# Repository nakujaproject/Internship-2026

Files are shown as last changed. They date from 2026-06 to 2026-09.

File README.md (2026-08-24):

# Nakuja Project internship 2026

**Vision**: Build and launch a sub-orbital rocket to 100 km (Kármán Line).

**Mission**: Successful N4 Launch by September 2026.

## Quick Navigation
- [Project Overview](./00_PROJECT_OVERVIEW)
- [Solid Propulsion](./01_SOLID_PROPULSION)
- [Airframe](./02_AIRFRAME)
- [Recovery/Avionics](./03_RECOVERY)
- [Progress Tracker](./00_PROJECT_OVERVIEW/02_Progress_Tracker.md)

**Workshop Hours**: 9:00 AM – 5:00 PM, Monday–Friday.

**How to Contribute**: See [Contributing Guidelines](CONTRIBUTING.md)

# Nakuja Rocketry Repository Structure

```text
Internship-2026/
├── README.md                        
├── 00_PROJECT_OVERVIEW/
│   ├── 01_N4_ROCKET/
│   │   ├── image/
│   │   ├── Rocket_Specification.md
│   ├── 02_Organistaion_&_Structure/
│   │   ├── Nakuja_Project_Organisation_&_Operational_Structure.docx
│   │   ├── 02_Progress_Tracker.md
│   ├── 03_Meeting_Minutes/
│   ├── 04_Risk_Register.md
│   ├── 05_Launch_Checklist.md
│   └── 06_Timeline_Gantt.md
│
├── 01_SOLID_PROPULSION/                  
│   ├── 01_Propellant/
│   │   ├── Grains/
│   │   ├── Liners/
│   │   ├── Ignitors/
│   │   ├── Crimson_Powder/
│   │   ├── Experiments/
│   │   └── Research/
│   ├── 02_Machining_Team/
|   |   ├── Nozzles/
|   |   ├── Bulkheads/
│   │   ├── Motor_Assembly/
|   |   └── Test_Stand/
│   ├── 03_Ignition_Circuit/
|   |   ├── Software/
|   |   ├── Hardware/
│   ├── 04_3D_Printing/
│   ├── 05_Documentation/
│   │
│   ├── Static_Tests/
│   │   ├── One_Grain/
│   │   └── Five_Grain/
│   │
│   └── Photos_&_Videos/
│
├── 02_AIRFRAME/
│   ├── CAD_Designs/
│   ├── Fabrication/
│   ├── Launch_Pad_Rail/
│   └── Integration/
│
├── 03_RECOVERY/
│   ├── Flight_Computer/
│   ├── Telemetry/
│   ├── Ejection_System/
│   ├── Parachutes/
│   └── Integration/
│
├── 04_CROSS_TEAM/
│   ├── Integration_Dry_Runs/
│   ├── Safety_Protocols/
│   ├── Budget_Purchasing/
│   └── Media_Outreach/
│
├── 05_ARCHIVES/
│   ├── Previous_Tests/
│   ├── Old_Designs/
│   └── Backup/
│
├── .github/  *Make sure each folder has its own template
│   ├── ISSUE_TEMPLATE/
│   │   ├── experiment-template.md
│   │   ├── static-test-template.md
│   │   └── task-template.md
│   │
│   └── workflows/
│       └── README.md                  # Future CI/CD workflows
│
└── docs/
    ├── Scientific_Method_Guide.md
    ├── Grain_Preparation_Criteria.md
    └── Folder_Naming_Convention.md
```

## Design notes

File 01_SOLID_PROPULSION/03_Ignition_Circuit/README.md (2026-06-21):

## Purpose

This folder serves as the main documentation and development space for the ignition subsystem. It should help future team members understand, reproduce, test, maintain, and improve the ignition system.

The folder should contain:

* ESP32 firmware for the igniter board.
* ESP32 firmware for the trigger board.
* Web dashboard source files.
* Circuit diagrams and PCB files.
* Pin mappings and wiring documentation.
* Sensor calibration notes.
* Static-test and dry-run telemetry data.
* Dashboard screenshots and CSV logs.
* Safety checklists and operating notes.
* Relevant progress reports and technical summaries.

## System Architecture

The ignition system is divided into two main hardware modules:

| Module | Location | Main Function |
| --- | --- | --- |
| Igniter Circuit Board | Near the motor or static test stand | Reads sensors, controls the ignition-output circuit, and sends telemetry |
| Trigger Circuit Board | Operator side / safe distance | Sends ignition commands, receives telemetry, and streams data to the dashboard |
| Web Dashboard | Laptop or tablet connected to the trigger board | Displays real-time telemetry, logs events, and exports CSV data |

## Igniter Circuit Board

The igniter board is the test-stand-side module. It handles sensor acquisition, ignition-output control, and telemetry transmission.

Main functions:

* Reads thrust data from a load cell through the HX711 module.
* Reads temperature using the DS18B20 temperature sensor.
* Interfaces with the pressure transmitter circuit for chamber pressure monitoring.
* Receives wireless commands from the trigger board.
* Controls the MOSFET-based ignition-output circuit.
* Limits the ignition-output duration using firmware safety logic.
* Sends telemetry data to the trigger board.

Main components:

| Component | Purpose |
| --- | --- |
| ESP32 | Main controller |
| HX711 | Load-cell signal acquisition |
| Load cell | Thrust measurement |
| DS18B20 | Temperature measurement |
| Pressure transmitter/interface | Chamber pressure measurement |
| IRFZ44N MOSFET | Ignition-output switching |
| Power regulation circuit | Stable supply for logic and sensor circuits |

## Trigger Circuit Board

The trigger board is the operator-side module. It acts as the control and communication bridge between the igniter board and the dashboard.

Main functions:

* Sends ignition commands to the igniter board.
* Receives telemetry from the igniter board through ESP-NOW.
* Creates a local Wi-Fi access point.
* Runs a WebSocket server for dashboard communication.
* Provides operator feedback using indicators such as buzzer, status LED, or display output.
* Supports safer test operation by keeping the operator away from the test stand.

## Web Dashboard

The dashboard is a browser-based interface for real-time test monitoring and data recording.

Main functions:

* Displays thrust, pressure, and temperature values.
* Shows telemetry trends using graphs.
* Displays system and connection status.
* Logs important events such as arming, disconnection, and ignition status.
* Allows recording to be started and stopped.
* Exports telemetry as timestamped CSV files for later analysis.

The dashboard is developed using:

| Technology | Use |
| --- | --- |
| HTML | Dashboard structure |
| CSS | Styling and layout |
| JavaScript | Data handling, plotting, event logging, and CSV export |
| WebSocket  | Real-time telemetry communication |
| Node.js | Dashboard testing or telemetry simulation where applicable |

## Communication Flow

The system uses two communication layers:

| Link | Method | Purpose |
| --- | --- | --- |
| Igniter board ↔ Trigger board | ESP-NOW | Board-to-board command and telemetry communication |
| Trigger board ↔ Dashboard | Wi-Fi access point + WebSocket | Real-time dashboard streaming |

General data flow:

```text
Sensors
   ↓
Igniter Circuit Board
   ↓
ESP-NOW
   ↓
Trigger Circuit Board
   ↓
Wi-Fi + WebSocket
   ↓
Web Dashboard
   ↓
CSV Export
```

## Telemetry Variables

| Variable | Unit | Source |
| --- | ---: | --- |
| Thrust | N | Load cell + HX711 |
| Pressure | bar | Pressure transmitter |
| Temperature | °C | DS18B20 |
| Armed State | Status | Firmware logic |
| Ignition State | Status | Firmware logic |
| Time | s / ms | ESP32 or dashboard timestamp |

## Sensor and Data Acquisition

### Load Cell and HX711

The load cell is used to measure thrust during static testing. The HX711 converts the small load-cell signal into digital data that can be processed by the ESP32.

The HX711 sampling rate was improved to increase the number of useful data points during short static-test burns. This improves thrust-curve resolution and helps with later comparison against simulation results.

### Temperature Sensor

The DS18B20 digital temperature sensor is used for temperature measurement. It provides a digital reading and reduces the need for analog signal conditioning.

### Pressure Transmitter Interface

The pressure measurement system is intended to monitor chamber pressure during static testing. Since the ESP32 reads voltage, the pressure transmitter signal must be conditioned into a safe analog voltage range before being connected to the ESP32 analog input.

Pressure data is important for understanding combustion behavior, validating simulations, and supporting future motor scaling decisions.

## Safety Logic

The ignition system is safety-critical. The firmware and operating procedure must ensure that ignition only occurs under controlled conditions.

Core safety features:

* Remote operator-side command.
* Wireless separation between operator and test stand.
* Arming logic before ignition.
* Timed ignition-output window.
* Status feedback through the dashboard and indicators.
* Telemetry confirmation before test operation.
* Data recording for post-test review.
* Documentation of abnormal behavior before further testing.

## Software Folder

The `Software/` folder should contain all firmware and dashboard-related files.

Recommended structure:

```text
Software/
├── Igniter_Board_Firmware/
├── Trigger_Board_Firmware/
├── Web_Dashboard/
└── Simulation_or_Test_Tools/
```

Recommended contents:

* ESP32 igniter firmware.
* ESP32 trigger firmware.
* Dashboard HTML, CSS, and JavaScript files.
* WebSocket or Node.js simulation tools.
* Required libraries.
* Upload instructions.
* Firmware notes.
* Dashboard screenshots.
* Sample test data.

## Hardware Folder

The `Hardware/` folder should contain all physical design and electronics documentation.

Recommended structure:

```text
Hardware/
├── Schematics/
├── PCB/
├── Wiring_Diagrams/
├── Photos/
├── BOM.md
└── Pin_Mapping.md
```

## Development Status

| Area | Status |
| --- | --- |
| Igniter board firmware | In development / testing |
| Trigger board firmware | In development / testing |
| Web dashboard | Developed for real-time telemetry visualization  |
| ESP-NOW communication | Implemented for board-to-board communication |
| WebSocket communication | Implemented for dashboard streaming |
| HX711 load-cell acquisition | Improved for higher sampling-rate thrust capture |
| DS18B20 temperature sensing | Integrated |
| Pressure transmitter interface | Requires final validation and calibration |
| Power stability | Brownout mitigation requires final validation |
| CSV export | Implemented in dashboard workflow |
| Static-test validation | To be updated after each test campaign |

## Repository Scope

This folder covers:

* Ignition system electronics.
* ESP32 firmware.
* Wireless communication.
* Web dashboard development.
* Sensor interfacing.
* Telemetry logging.
* Calibration notes.
* Hardware documentation.
* Test data.
* Safety checklists.

## Safety Notice

All ignition-system testing must be conducted only under approved Nakuja Project procedures, supervision, safe-distance operation, and proper pre-test checks.

This repository folder is for electronics, firmware, telemetry, calibration, data logging, and safety documentation only.

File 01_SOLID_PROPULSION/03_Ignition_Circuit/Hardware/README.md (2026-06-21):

# Hardware — Ignition Circuit

## Overview

This folder contains the hardware documentation for the Nakuja Project ignition and real-time telemetry system. It includes circuit diagrams, PCB files, wiring diagrams, pin mappings, power-system notes, bill of materials, and reference photos.

The hardware system is divided into two main modules:

1. Igniter Circuit Board
2. Trigger Circuit Board

The igniter board is placed near the motor or static test stand, while the trigger board is operated from a safe distance.

## Recommended Folder Structure

```text
Hardware/
├── README.md
├── Schematics/
├── PCB/
├── Wiring_Diagrams/
├── Photos/
├── BOM.md
└── Pin_Mapping.md
```

## Main Hardware Modules

| Module | Location | Purpose |
| --- | --- | --- |
| Igniter Circuit Board | Near static test stand | Sensor reading, telemetry transmission, ignition-output control |
| Trigger Circuit Board | Operator side | Command input, telemetry reception, dashboard link, operator feedback |
| Sensor Interfaces | Test-stand side | Thrust, pressure, and temperature measurement |
| Power System | Both boards | Provides regulated voltage to electronics and sensors |

## Igniter Circuit Board

The igniter board handles test-stand-side sensing and output control.

Main hardware functions:

* Interface with the load cell through the HX711 module.
* Interface with the DS18B20 temperature sensor.
* Interface with the pressure transmitter circuit.
* Control the MOSFET-based ignition-output stage.
* Send telemetry to the trigger board.
* Receive wireless command signals from the trigger board.

Recommended documentation:

```text
Igniter_Board/
├── schematic.pdf
├── pcb_layout.png
├── wiring_diagram.png
├── board_photo.jpg
└── notes.md
```

## Trigger Circuit Board

The trigger board handles the operator-side control and communication functions.

Main hardware functions:

* Provide operator command input.
* Give status feedback through buzzer, LED, or display output.
* Receive telemetry from the igniter board.
* Support Wi-Fi and WebSocket communication to the dashboard.
* Maintain operator-side separation from the test stand.

Recommended documentation:

```text
Trigger_Board/
├── schematic.pdf
├── pcb_layout.png
├── wiring_diagram.png
├── board_photo.jpg
└── notes.md
```

## Main Components

| Component | Purpose |
| --- | --- |
| ESP32 | Main controller for both boards |
| HX711 | Load-cell signal acquisition |
| Load cell | Thrust measurement |
| DS18B20 | Temperature measurement |
| Pressure transmitter/interface | Chamber pressure measurement |
| IRFZ44N MOSFET | Ignition-output switching |
| Buck converter | Step-down voltage regulation |
| Boost converter | Pressure transmitter supply where required |
| XT60 / XT30 connectors | Secure power connection |
| JST connectors | Secure sensor connections |
| Buzzer | Operator feedback |
| Status LED | Visual indication |

## Power System

The hardware should include clear documentation of the power path.

Document the following:

* Main battery voltage.
* Regulated logic voltage.
* ESP32 supply voltage.
* Sensor supply voltage.
* Pressure transmitter supply voltage.
* Ground reference connections.
* Connector type and polarity.
* Fuse or protection method where used.
* Brownout issues and mitigation steps.

## Sensor Interfaces

### Load Cell and HX711

The load cell and HX711 subsystem is used for thrust measurement. The hardware documentation should include:

* Load-cell wiring.
* HX711 wiring.
* HX711 sampling-rate configuration.
* Calibration connection notes.
* Mechanical mounting reference where available.

### DS18B20 Temperature Sensor

The DS18B20 subsystem is used for temperature measurement. The hardware documentation should include:

* Sensor wiring.
* Pull-up resistor value where used.
* Connector type.
* Physical mounting location.

### Pressure Transmitter Interface

The pressure transmitter/interface is used for chamber pressure measurement. The hardware documentation should include:

* Pressure transmitter wiring.
* Supply voltage.
* Current-to-voltage conversion circuit.
* ESP32 analog input connection.
* Resistor value used for conversion.
* Expected voltage range.
* Calibration notes.

## PCB Documentation

For each PCB revision, include:

| File | Description |
| --- | --- |
| Schematic | Circuit-level design |
| PCB layout | Board routing and component placement |
| Gerber files | Fabrication files |
| Board photos | Physical reference |
| Revision notes | What changed between versions |
| Test notes | What was verified |

## Pin Mapping

Create or update `Pin_Mapping.md` with a table such as:

| Function | ESP32 Pin | Board | Notes |
| --- | ---: | --- | --- |
| MOSFET gate | GPIO26 | Igniter | Ignition-output control |
| HX711 DOUT | GPIO33 | Igniter | Load-cell data |
| HX711 SCK | GPIO32 | Igniter | Load-cell clock |
| DS18B20 data | GPIO14 | Igniter | Temperature input |
| Pressure input | GPIO13 | Igniter | Analog pressure signal |
| Buzzer | To be documented | Trigger | Operator feedback |
| Status input/button | To be documented | Trigger | Operator command or state input |

## Hardware Documentation Rules

When adding hardware files:

1. Use clear file names.
2. Separate schematics, PCB files, wiring diagrams, and photos.
3. Label every board revision.
4. Add notes for tested and untested circuits.
5. Document connector polarity.
6. Document voltage levels.
7. Document sensor pinouts.
8. Keep photos compressed but clear.
9. Do not upload unexplained Gerber or schematic files.
10. Add a short note when replacing or modifying a component.

## Current Status

| Area | Status |
| --- | --- |
| Igniter board hardware | In development / testing |
| Trigger board hardware | In development / testing |
| Load-cell interface | Integrated |
| Temperature sensor interface | Integrated |
| Pressure transmitter interface | Requires final validation |
| Power regulation | Requires brownout validation |
| PCB documentation | To be updated with final board files |
| Wiring documentation | To be completed with labelled diagrams |

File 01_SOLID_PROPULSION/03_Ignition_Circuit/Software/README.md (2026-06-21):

# Software — Ignition Circuit

## Overview

This folder contains all software files for the Nakuja Project ignition and real-time telemetry system. It includes ESP32 firmware for the igniter and trigger boards, web dashboard source files, and simulation or testing tools used during development.

The software system supports wireless command transmission, real-time telemetry streaming, dashboard visualization, event logging, and CSV data export.

## Recommended Folder Structure

```text
Software/
├── README.md
├── Igniter_Board_Firmware/
├── Trigger_Board_Firmware/
├── Web_Dashboard/
└── Simulation_or_Test_Tools/
```

## Software Modules

| Module | Purpose |
| --- | --- |
| `Igniter_Board_Firmware/` | Firmware for the test-stand-side ESP32 board |
| `Trigger_Board_Firmware/` | Firmware for the operator-side ESP32 board |
| `Web_Dashboard/` | Browser-based telemetry dashboard files |
| `Simulation_or_Test_Tools/` | Scripts or tools for testing telemetry without full hardware |

## Igniter Board Firmware

The igniter board firmware runs on the ESP32 located near the static test stand.

Main responsibilities:

* Read thrust data from the HX711 load-cell subsystem.
* Read temperature data from the DS18B20 sensor.
* Read pressure data from the pressure transmitter interface.
* Receive ignition commands from the trigger board through ESP-NOW.
* Control the MOSFET-based ignition output.
* Enforce the programmed ignition safety window.
* Send telemetry packets to the trigger board.

Recommended files:

```text
Igniter_Board_Firmware/
├── README.md
├── main.ino
├── config.example.h
├── pins.h
└── libraries.md
```

## Trigger Board Firmware

The trigger board firmware runs on the ESP32 located with the operator.

Main responsibilities:

* Receive telemetry from the igniter board.
* Send operator ignition commands to the igniter board.
* Create the local Wi-Fi access point.
* Run the WebSocket server for dashboard communication.
* Forward telemetry data to the dashboard.
* Provide operator feedback using indicators such as buzzer, LED, or display output.

Recommended files:

```text
Trigger_Board_Firmware/
├── README.md
├── main.ino
├── config.example.h
├── pins.h
└── libraries.md
```

## Web Dashboard

The web dashboard is used to monitor the static test in real time from a laptop or tablet.

Main functions:

* Display thrust, pressure, and temperature.
* Plot telemetry values against time.
* Show system connection status.
* Log important events.
* Start and stop data recording.
* Export recorded telemetry as CSV files.

Recommended files:

```text
Web_Dashboard/
├── README.md
├── index.html
├── style.css
├── script.js
├── assets/
├── screenshots/
└── sample_data/
```

## Communication Flow

```text
Igniter Board Firmware
        ↓
ESP-NOW telemetry
        ↓
Trigger Board Firmware
        ↓
Wi-Fi Access Point + WebSocket
        ↓
Web Dashboard
        ↓
CSV Export
```

## Main Technologies

| Technology | Use |
| --- | --- |
| ESP32 | Main microcontroller platform |
| ESP-NOW | Board-to-board wireless communication |
| Wi-Fi Access Point | Local dashboard connection |
| WebSocket | Real-time telemetry streaming |
| HTML | Dashboard structure |
| CSS | Dashboard styling |
| JavaScript | Dashboard logic, plotting, recording, and CSV export |
| Node.js | Optional testing or telemetry simulation |

## Telemetry Data

The software should handle the following main telemetry values:

| Variable | Unit | Description |
| --- | ---: | --- |
| Thrust | N | Load-cell measurement through HX711 |
| Pressure | bar | Pressure transmitter/interface reading |
| Temperature | °C | DS18B20 sensor reading |
| Armed State | Status | Indicates arming condition |
| Ignition State | Status | Indicates ignition-output state |
| Time | s / ms | Timestamp for plotting and data recording |

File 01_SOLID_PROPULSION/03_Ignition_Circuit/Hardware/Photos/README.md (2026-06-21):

# Hardware Photos

## Overview

This folder contains reference photos for the Nakuja Project ignition circuit hardware.

Photos should help team members understand the physical assembly, wiring, PCB layout, connector arrangement, test setup, and hardware changes between revisions.

## Recommended Contents

```text
Photos/
├── README.md
├── Igniter_Board/
├── Trigger_Board/
├── PCB_Fabrication/
├── Sensor_Connections/
├── Power_System/
└── Test_Setup/
```

## Photos to Include

| Photo Type | Purpose |
| --- | --- |
| Igniter board top view | Shows component placement |
| Igniter board wiring | Shows sensor and power connections |
| Trigger board top view | Shows operator-side hardware |
| Trigger board wiring | Shows command and feedback connections |
| PCB fabrication photos | Shows etching, drilling, soldering, or manufacturing process |
| HX711/load-cell connection | Shows thrust sensor wiring |
| DS18B20 connection | Shows temperature sensor wiring |
| Pressure interface setup | Shows pressure sensor/transmitter connection |
| Power system photo | Shows battery, buck converter, boost converter, and connectors |
| Test setup photo | Shows safe hardware arrangement during dry run or static test  |

## Photo Naming Format

Use clear file names:

```text
igniter_board_revA_top_view.jpg
igniter_board_revA_wiring.jpg
trigger_board_revA_top_view.jpg
trigger_board_revA_wiring.jpg
pcb_etching_revA_process.jpg
hx711_load_cell_connection.jpg
ds18b20_sensor_connection.jpg
pressure_interface_test_setup.jpg
power_system_wiring_revA.jpg
```

## Documentation Notes

For important photos, add a short note explaining:

* What the photo shows.
* Which board revision it belongs to.
* Whether the setup was tested.
* Any known issue visible in the photo.
* Date taken, if available.

## Quality Guidelines

* Upload clear and well-lit photos.
* Avoid duplicate photos.
* Avoid blurry wiring photos.
* Compress very large images before uploading.
* Do not upload unrelated personal photos or unsafe test images without context.

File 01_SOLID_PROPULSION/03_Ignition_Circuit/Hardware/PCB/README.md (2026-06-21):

# PCB Documentation

## Overview

This folder contains printed circuit board documentation for the Nakuja Project ignition circuit hardware.

It should include PCB layout files, Gerber files, board images, fabrication notes, and revision records for the igniter board and trigger board.

## Recommended Contents

```text
PCB/
├── README.md
├── Igniter_Board/
├── Trigger_Board/
├── Gerber_Files/
├── PCB_Layout_Images/
└── Fabrication_Notes/
```

## PCB Files to Upload

| File Type | Purpose |
| --- | --- |
| Schematic-linked PCB layout | Shows component placement and routing |
| Gerber files | Used for PCB fabrication |
| Drill files | Used for PCB hole drilling |
| Top copper image | Shows top copper routing |
| Bottom copper image | Shows bottom copper routing |
| Silkscreen image | Shows labels and component positions |
| Board photo | Shows the physical fabricated board |
| Fabrication notes | Documents etching, drilling, soldering, or manufacturing steps |

## Board Revision Format

Use clear revision names:

```text
igniter_board_revA
trigger_board_revA
igniter_board_revB
trigger_board_revB
```

## Recommended Revision Table

| Board | Revision | Date | Status | Notes |
| --- | --- | --- | --- | --- |
| Igniter Board | Rev A | YYYY-MM-DD | Draft / Fabricated / Tested | Initial version |
| Trigger Board | Rev A | YYYY-MM-DD | Draft / Fabricated / Tested | Initial version |

## Documentation Notes

For every PCB version, document:

* Board name.
* Revision number.
* Date created.
* Design software used.
* Main changes from previous version.
* Known issues.
* Test status.
* Photos of the final assembled board where available.

## Safety Note

PCB files must match the latest verified schematic and firmware pin mapping. Any mismatch between PCB routing, firmware pins, and wiring diagrams must be corrected before testing.

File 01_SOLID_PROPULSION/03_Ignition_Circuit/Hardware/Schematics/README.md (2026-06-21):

## File: `Schematics/README.md`

# Schematics

## Overview

This folder contains circuit schematics for the Nakuja Project ignition system hardware.

The schematics should document the electrical connections for the igniter board, trigger board, sensor interfaces, power regulation stage, and ignition-output switching circuit.

## Recommended Contents

* Igniter board schematic.
* Trigger board schematic.
* Power regulation schematic.
* HX711 load-cell interface schematic.
* DS18B20 temperature sensor interface.
* Pressure transmitter/interface circuit.
* MOSFET ignition-output switching circuit.
* Status LED and buzzer connections.

## Documentation Notes

Each schematic should clearly show:

* Component labels.
* Connector names.
* Voltage levels.
* Ground reference.
* ESP32 pin connections.
* Sensor wiring.
* Power input and output paths.
* Revision number and date.

---

## File: `PCB/README.md`

# PCB

## Overview

This folder contains printed circuit board documentation for the ignition system.

It should include PCB layout files, Gerber files, board images, fabrication notes, and revision history for both the igniter board and trigger board.

## Recommended Contents

* PCB layout screenshots.
* Gerber files.
* Board fabrication files.
* Etching or manufacturing notes.
* Component placement diagrams.
* Top and bottom copper layer images.
* Board revision notes.
* Photos of assembled PCBs.

## Documentation Notes

Each PCB revision should include:

| Item | Description |
| --- | --- |
| Board name | Igniter board or trigger board |
| Revision | Rev A, Rev B, etc. |
| Date | Date uploaded or fabricated |
| Status | Draft, fabricated, tested, or archived |
| Notes | Main changes or known issues |

---

## File: `Wiring_Diagrams/README.md`

# Wiring Diagrams

## Overview

This folder contains wiring diagrams for the ignition system.

The wiring diagrams should make it easy for a team member to connect the boards, sensors, power supply, and dashboard communication hardware correctly.

## Recommended Contents

* Full system wiring diagram.
* Igniter board wiring diagram.
* Trigger board wiring diagram.
* Load-cell and HX711 wiring.
* DS18B20 wiring.
* Pressure transmitter/interface wiring.
* Power wiring.
* Connector pinout diagrams.

## Documentation Notes

Each wiring diagram should clearly show:

* Connector names.
* Pin numbers.
* Wire colors where applicable.
* Voltage level.
* Ground connections.
* Signal direction.
* Sensor polarity.
* Power polarity.
* Safety-related connections.

---

## File: `Photos/README.md`

# Photos

## Overview

This folder contains reference photos for the ignition system hardware.

Photos should help future team members understand the physical assembly, wiring, PCB layout, and test setup.

## Recommended Contents

* Igniter board photos.
* Trigger board photos.
* PCB fabrication photos.
* Wiring photos.
* Sensor connection photos.
* Dashboard setup photos.
* Static-test setup photos where appropriate.

## Photo Naming Format

Use clear names such as:

```text
igniter_board_revA_top_view.jpg
trigger_board_revA_wiring.jpg
hx711_load_cell_connection.jpg
pressure_interface_test_setup.jpg
pcb_etching_process_revA.jpg
```

## Documentation Notes

Avoid uploading unclear or duplicate photos. Each important photo should be labelled or accompanied by a short note explaining what it shows.

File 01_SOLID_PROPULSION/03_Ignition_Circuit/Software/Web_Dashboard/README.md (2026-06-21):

# Web Dashboard

## Overview

This folder contains the browser-based dashboard for the Nakuja Project ignition and real-time telemetry system.

The dashboard is used to monitor thrust, pressure, temperature, connection status, arming state, and ignition events during dry runs and static motor tests. It receives telemetry through a WebSocket connection and allows recorded data to be exported as CSV files.

## Main Functions

* Display real-time thrust readings.
* Display real-time pressure readings.
* Display real-time temperature readings.
* Plot telemetry values against time.
* Show connection status.
* Log important events.
* Start and stop data recording.
* Export recorded telemetry as CSV files.
* Support review of static-test and dry-run data.

## Recommended Folder Contents

```text
Web_Dashboard/
├── README.md
├── index.html
├── style.css
├── script.js
├── assets/
├── screenshots/
└── sample_data/
```

## Main Files

| File/Folder | Purpose |
| --- | --- |
| `index.html` | Main dashboard page structure |
| `style.css` | Dashboard styling and layout |
| `script.js` | WebSocket connection, charting, event logging, and CSV export |
| `assets/` | Logos, icons, and visual resources |
| `screenshots/` | Dashboard preview images |
| `sample_data/` | Example telemetry data for testing |

## Dashboard Data

| Variable | Unit | Description |
| --- | ---: | --- |
| Thrust | N | Load-cell measurement |
| Pressure | kPa / bar | Pressure transmitter/interface reading |
| Temperature | °C | DS18B20 reading |
| Armed State | Status | System arming condition |
| Ignition State | Status | Ignition-output condition |
| Time | s / ms | Used for plotting and recording |

## Communication

The dashboard receives data from the trigger board through a WebSocket connection.

```text
Trigger Board
     ↓
Wi-Fi Access Point
     ↓
WebSocket
     ↓
Browser Dashboard
```

## Development Notes

When updating the dashboard, document:

* Dashboard version.
* WebSocket IP address or hostname.
* WebSocket port.
* Telemetry packet format.
* Chart update rate.
* CSV export format.
* Known bugs.
* Screenshots of the interface.

## Testing Notes

The dashboard can be tested using:

* Live data from the trigger board.
* Simulated telemetry from Node.js or another test script.
* Sample CSV files.
* Manually generated telemetry packets.

## Safety Note

The dashboard is a monitoring and recording interface. It should not be treated as the only safety control. Physical procedures, firmware safety logic, and approved test checklists must still be followed.

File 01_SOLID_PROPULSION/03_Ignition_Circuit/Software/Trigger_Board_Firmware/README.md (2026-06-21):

# Trigger Board Firmware

## Overview

This folder contains the ESP32 firmware for the trigger-side board of the Nakuja Project ignition and real-time telemetry system.

The trigger board is positioned with the operator at a safe distance. It sends ignition commands, receives telemetry from the igniter board, provides operator feedback, and streams data to the web dashboard.

## Main Responsibilities

* Send ignition commands to the igniter board.
* Receive telemetry from the igniter board through ESP-NOW.
* Create a local Wi-Fi access point for dashboard connection.
* Run a WebSocket server for real-time dashboard communication.
* Forward telemetry values to the dashboard.
* Provide operator feedback using buzzer, LED, LCD, or other indicators.
* Support safe operator-side control.

## Main Interfaces

| Function | Device/Interface | Notes |
| --- | --- | --- |
| Board-to-board communication | ESP-NOW | Receives telemetry and sends commands |
| Dashboard connection | Wi-Fi access point | Laptop connects locally |
| Dashboard streaming | WebSocket server | Sends live telemetry |
| Operator feedback | Buzzer / LED / display | Shows status and alerts |
| Operator command | Push button / switch | Used for controlled command input |

## Recommended Folder Contents

```text
Trigger_Board_Firmware/
├── README.md
├── main.ino
├── config.example.h
├── pins.h
└── libraries.md
```

## Firmware Logic

The firmware should generally follow this sequence:

1. Initialize pins and feedback devices.
2. Initialize ESP-NOW communication.
3. Create the Wi-Fi access point.
4. Start the WebSocket server.
5. Receive telemetry from the igniter board.
6. Forward telemetry to the dashboard.
7. Monitor operator command input.
8. Send ignition command only when required.
9. Report connection and system-status changes.

## Communication Role

```text
Igniter Board
     ↓
ESP-NOW
     ↓
Trigger Board
     ↓
Wi-Fi + WebSocket
     ↓
Web Dashboard
```

## Documentation Requirements

When firmware is uploaded, include:

* Firmware version.
* Required libraries.
* Board type used.
* Pin mapping.
* Wi-Fi access point name.
* WebSocket port.
* Upload instructions.
* Known issues.
* Test notes.

## Safety Note

The trigger board should not send an ignition command accidentally. Operator input, arming status, communication status, and system state should be handled clearly in the firmware.

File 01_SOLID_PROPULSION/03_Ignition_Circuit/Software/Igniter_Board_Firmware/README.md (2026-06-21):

# Igniter Board Firmware

## Overview

This folder contains the ESP32 firmware for the igniter-side board of the Nakuja Project ignition and real-time telemetry system.

The igniter board is positioned near the solid rocket motor or static test stand. It is responsible for reading sensor data, receiving ignition commands, controlling the ignition-output circuit, and transmitting telemetry to the trigger board.

## Main Responsibilities

* Read thrust data from the load cell through the HX711 module.
* Read temperature data from the DS18B20 temperature sensor.
* Read pressure data from the pressure transmitter/interface circuit.
* Receive wireless commands from the trigger board.
* Control the MOSFET-based ignition-output circuit.
* Enforce the programmed ignition safety window.
* Send telemetry data to the trigger board.

## Main Hardware Interfaces

| Function | Device/Interface | Notes |
| --- | --- | --- |
| Thrust measurement | Load cell + HX711 | Used for static-test thrust data |
| Temperature measurement | DS18B20 | Digital temperature sensor |
| Pressure measurement | Pressure transmitter/interface | Requires signal conditioning before ESP32 input |
| Ignition output | MOSFET switching stage | Controlled by ESP32 firmware |
| Wireless communication  | ESP-NOW | Receives command and sends telemetry |

## Suggested Pin Mapping

| Function | ESP32 Pin | Notes |
| --- | ---: | --- |
| MOSFET gate | GPIO26 | Ignition-output control |
| HX711 DOUT | GPIO33 | Load-cell data |
| HX711 SCK | GPIO32 | Load-cell clock |
| DS18B20 data | GPIO14 | Temperature sensor data |
| Pressure input | GPIO13 | Analog pressure signal  |

## Recommended Folder Contents

```text
Igniter_Board_Firmware/
├── README.md
├── main.ino
├── config.example.h
├── pins.h
└── libraries.md
```

## Firmware Logic

The firmware should generally follow this sequence:

1. Initialize ESP32 pins, sensors, and communication.
2. Read thrust, temperature, and pressure values.
3. Send telemetry to the trigger board.
4. Wait for valid command from the trigger board.
5. Check arming and safety conditions.
6. Activate ignition output only when allowed.
7. Automatically disable ignition output after the safety window.
8. Continue sending telemetry and system-status data.

## Documentation Requirements

When firmware is uploaded, include:

* Firmware version.
* Required libraries.
* Board type used.
* Pin mapping.
* Upload instructions.
* Calibration assumptions.
* Known issues.
* Test notes.

## Safety Note

The ESP32 must not directly power the ignition load. It should only control the switching stage. The ignition output must remain disabled until all safety conditions are satisfied.

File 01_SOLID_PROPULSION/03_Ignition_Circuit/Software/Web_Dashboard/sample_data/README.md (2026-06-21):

# Sample Dashboard Data

## Overview

This folder contains sample telemetry data for testing and documenting the Nakuja ignition web dashboard.

The files in this folder are not real static-test results. They are only used to confirm dashboard formatting, CSV export, telemetry parsing, and documentation examples.

## Recommended Files

| File | Purpose |
|---|---|
| `sample_telemetry_packet.json` | Example WebSocket telemetry packet |
| `sample_dashboard_data.csv` | Example dashboard CSV export |
| `sample_event_log.txt` | Example event log output, if required |

## Sample Data Rules

- Clearly label all sample files.
- Do not mix sample data with real test data.
- Do not use sample data for engineering conclusions.
- Real dry-run and static-test data should be stored in a separate test-data folder.
- Update the sample files when the dashboard telemetry format changes.

## Expected Telemetry Variables

| Variable | Unit | Description |
|---|---:|---|
| Temperature | °C | DS18B20 temperature reading |
| Pressure | kPa / bar | Pressure transmitter/interface reading |
| Thrust | N | Load-cell and HX711 thrust reading |
| Armed State | Status | Ignition arming condition |
| Event | Text | Optional event log message |

## Notes

Sample data is useful for software testing, documentation, and demonstrating dashboard behavior without connecting the full ignition hardware.

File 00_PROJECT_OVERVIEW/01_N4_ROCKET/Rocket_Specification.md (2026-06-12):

# N4 rocket portal

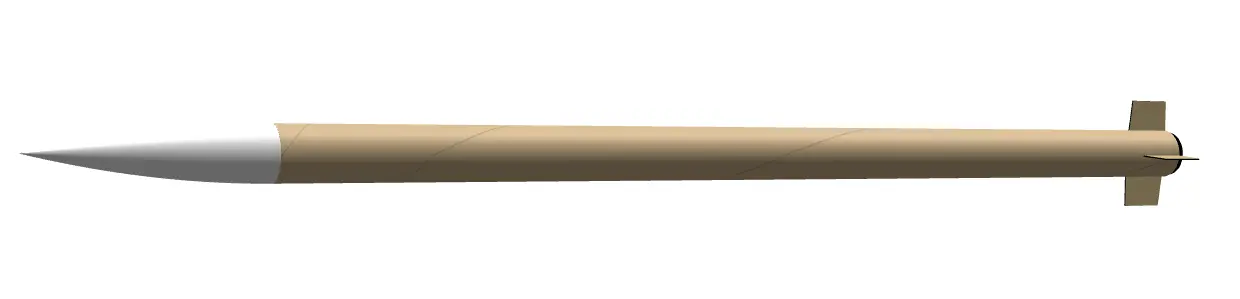
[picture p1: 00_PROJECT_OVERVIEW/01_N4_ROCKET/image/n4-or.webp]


## Specification

| Rocket | N-4  <br>(Names TBD) |
| --- | --- |
| Airframe material | Fibreglass |
| Length | 255 cm |
| External diameter | 110 mm |
| Dry mass | 13.1 kg |
| Total mass | 24.8 kg |
| Simulated apogee | 3,702 m |
| Propellant | KNSB |
| Simulated total impulse | 8,315 \[N•s\] (M2410 motor) |

## General information

| Component | Link  | 
|---|---|
| Rocket measured data | |
| Rocket photos | |

## Airframe
| Component | Link  | 
|---|---|
| OpenRocket simulation file |[link]https://github.com/nakujaproject/N4-Airframe-CAD-files/blob/main/N4_current.ork |
| Airframe CAD data |[link]https://github.com/nakujaproject/N4-Airframe-CAD-files |
| 3D Print data (Nose cone, launch lugs)|[link]https://github.com/nakujaproject/N4-Airframe-CAD-files |
| Avionics bay design data | |
| Parachute design data | |
| Fin design data | |

## Recovery
| Component | Link  | 
|---|---|
| Flight computer PCB design (Wifi-based. 3 of 4 N-3 rockets use this design) | []() |
| Flight computer PCB design (LoRa-based. 1 of 4 N-3 rocket uses this design) | []() |
| Ejection PCB design | []() |
| Flight computer firmware | |  
| Ground station dashboard |  | 

## Propulsion

| Component | Link  | 
|---|---|
| Solid rocket motor design calculation  | [link](https://github.com/nakujaproject/N-4_Solid_Propulsion/blob/main/SRM%20Components/Design%20Calculations.pdf)  |
| OpenMotor simulation file | [link](https://github.com/nakujaproject/N-4_Solid_Propulsion/blob/main/Grains/N4_grain%20design.ric) |  
| Casing CAD data  | [link](https://github.com/nakujaproject/N-4_Solid_Propulsion/blob/main/SRM%20Components/Casing.SLDPRT)  |  
| Casing drawing  | [link](https://github.com/nakujaproject/N-4_Solid_Propulsion/blob/main/SRM%20Components/Bulkhead_Drawing.pdf)|
| Nozzle CAD data  | [link](https://github.com/nakujaproject/N-4_Solid_Propulsion/blob/main/SRM%20Components/Nozzle2.SLDPRT) |  
| Nozzle drawing (No mounting holes)  | [link](https://github.com/nakujaproject/N-4_Solid_Propulsion/blob/main/SRM%20Components/Nozzle2_Drawing_redesigned.PDF)  |  
| Bulkhead CAD data |  [link](https://github.com/nakujaproject/N-4_Solid_Propulsion/blob/main/SRM%20Components/Bulkhead.SLDPRT) |  
| Bulkhead drawing (No mounting holes) | [link](https://github.com/nakujaproject/N-4_Solid_Propulsion/blob/main/SRM%20Components/Bulkhead_Drawing.pdf)|
| SRM casting video| | 

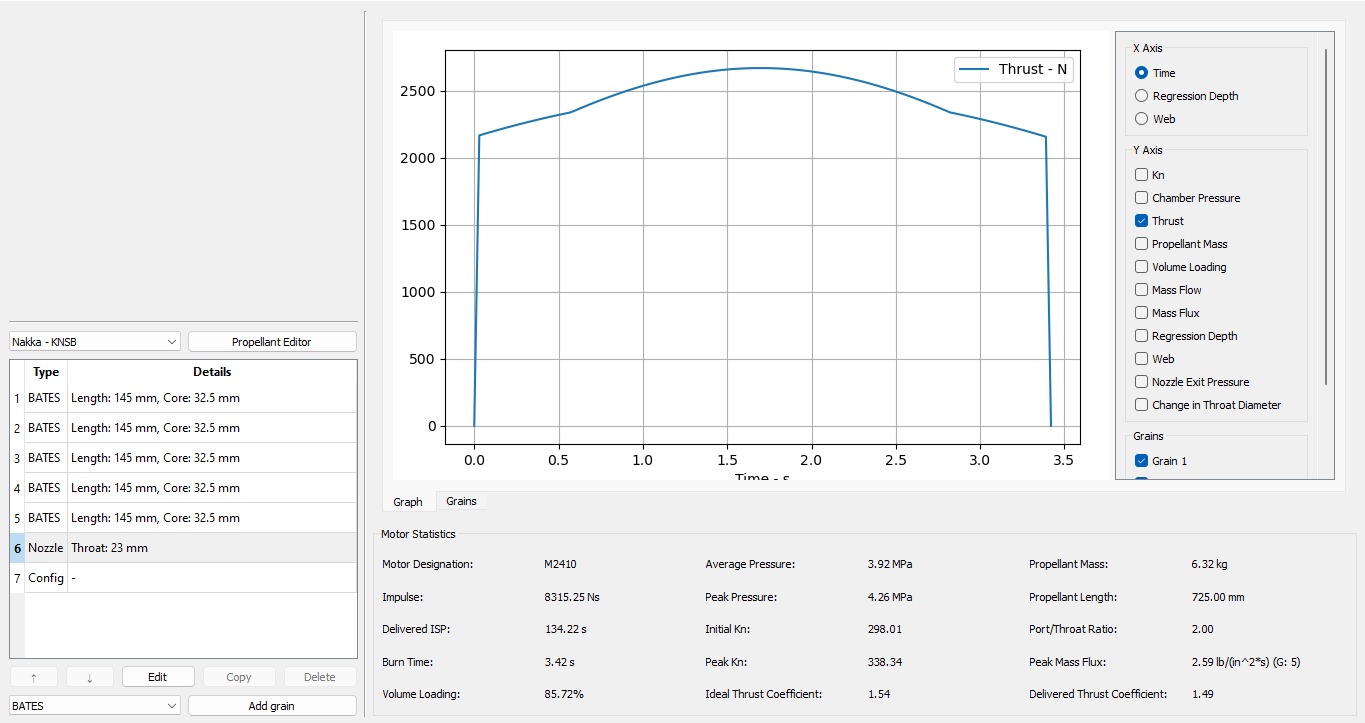
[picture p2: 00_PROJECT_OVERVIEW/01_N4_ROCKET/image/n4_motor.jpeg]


## Static test stand
| Component | Link  | 
|---|---|
| Ignitor design | |
| Ignition circuit design data | | 
| Ignition controller PCB design data | |
| Ignition controller firmware | | 
| Static test stand design calculation |  |
| Static test stand CAD data | |

## Testing
| Component | Link  | 
|---|---|
| Static test data| |
| Static test videos | | 
| Pop test data| |
| Pop test video| |
| Parachute test video| |
| Drone test data |  |

## Launch preparation documents
| Component | Link  | 
|---|---|
| Launch procedure | |
| Dry run | |
| Participants list || 

## Launch data
| Component | Link  | 
|---|---|
| Sensor telemetry data | |
| Video from onboard camera  | |
| Photos for launch | |

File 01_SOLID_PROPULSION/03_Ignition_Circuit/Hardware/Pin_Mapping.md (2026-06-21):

# Pin Mapping — Ignition Circuit

## Overview

This file documents the ESP32 pin assignments used in the Nakuja Project ignition and real-time telemetry system.

The pin mapping should be updated whenever the firmware, PCB, or wiring changes.

## Igniter Board Pin Mapping

| Function | ESP32 Pin | Direction | Device / Interface | Notes |
| --- | ---: | --- | --- | --- |
| Ignition MOSFET gate | GPIO26 | Output | IRFZ44N MOSFET | Controls ignition-output switching |
| HX711 DOUT | GPIO33 | Input | HX711 load-cell amplifier | Load-cell data line |
| HX711 SCK | GPIO32 | Output | HX711 load-cell amplifier | Load-cell clock line |
| DS18B20 data | GPIO14 | Input / data | DS18B20 temperature sensor | One-wire temperature data |
| Pressure input | GPIO13 | Analog input | Pressure transmitter/interface | Conditioned analog pressure signal |
| 5 V supply | 5 V / VIN | Power | ESP32 and logic circuits | From regulated supply |
| GND | GND | Ground | Common ground | Must be shared by logic and sensor circuits |

## Trigger Board Pin Mapping

| Function | ESP32 Pin | Direction | Device / Interface | Notes |
| --- | ---: | --- | --- | --- |
| Buzzer | GPIO18 | Output | Active buzzer | Audio feedback |
| Status button | GPIO32 | Input | Push button / status input | Operator input or status control |
| Wi-Fi access point | Internal radio | Wireless  | Dashboard connection | Local dashboard link |
| ESP-NOW communication | Internal radio | Wireless  | Igniter board | Board-to-board communication |
| WebSocket server | Internal Wi-Fi | Wireless  | Dashboard | Telemetry streaming |
| 5 V supply | 5 V / VIN | Power | ESP32 and logic circuits | From regulated supply |
| GND | GND | Ground | Common ground | Required for stable operation |

## Communication Details

| Link | Method | Notes |
| --- | --- | --- |
| Igniter board to trigger board | ESP-NOW | Sends telemetry and receives command |
| Trigger board to dashboard | Wi-Fi access point | Local dashboard connection |
| Dashboard telemetry | WebSocket, port 81 | Real-time data streaming |

## Important Hardware Notes

* GPIO26 controls the ignition-output switching stage through the MOSFET.
* The ESP32 must not directly power the ignition load.
* The pressure transmitter/interface must be conditioned before connection to the ESP32 ADC.
* All sensor and logic grounds must share a correct reference.
* Final pin mapping must match both the firmware and PCB layout.
* Any pin change must be updated in this file, the firmware, and the wiring diagram.

## Revision History

| Date | Revision | Change | Updated By |
| --- | --- | --- | --- |
| YYYY-MM-DD | Rev A | Initial pin mapping documentation | Joel Litu Ehenzo |

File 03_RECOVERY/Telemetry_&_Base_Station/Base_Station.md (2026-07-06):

# Base Station Hardware Documentation

**Nakuja Internship 2026 Recovery Team | N4 Rocket**

---

## 1. Introduction

The Nakuja N4 Base Station is the ground control hardware unit used to command, monitor, and recover the N4 rocket during flight operations. It functions as the primary interface between the ground crew and the rocket's Flight Computer (FC), enabling real-time monitoring of telemetry and the issuing of safety-critical commands during the launch and recovery sequence.

The base station is a self-contained, battery-powered unit built around two microcontrollers (an Arduino ATMEGA2560 and a NodeMCU-32S ESP32) and is designed to be portable, robust, and operable in the field.

### Key Functions
* **Arming:** Enables a physical arming switch and corresponding indicator LED that must be actuated by the ground crew before the recovery system (parachute deployment charges) can be live. This is a safety interlock that prevents accidental deployment during handling, transport, and pad operations.
* **Telemetry Reception:** Continuously receives downlink telemetry data (e.g., altitude, GPS position, battery status, system state) transmitted by the Flight Computer over the wireless link via the patch antenna, and relays this data to a PC over USB for logging, display, and analysis.
* **Parachute Deployment:** Allows the ground crew to transmit discrete commands to the Flight Computer through a terminal interface on the PC or the on-board keypad, including manual deployment of the drogue and/or main parachute in the event of a recovery anomaly.

---

## 2. System Architecture & Signal Flow

### Data & Command Signal Paths
* **Telemetry Path (Downlink):** Flight Computer → (RF downlink) → Patch Antenna → RF Amplifier → XBee Pro radio module → Arduino ATMEGA2560 → Serial/USB → Ground PC
* **Command Path (Uplink):** Ground PC / Keypad → Arduino ATMEGA2560 → XBee Pro radio module → RF Amplifier → Patch Antenna → (RF uplink) → Flight Computer
* **Auxiliary Path:** ESP32 (NodeMCU-32S) → handles auxiliary I/O: battery-level sensing, status LEDs, and Bluetooth-based status reporting, communicating with the ATMEGA2560 over UART.
* **Power Distribution:** 4S Li-Fe battery pack → BMS → Buck Converters (5V/3.3V) → distributes regulated power to all subsystems.

### Wireless Communication
The base station communicates with the Flight Computer entirely wirelessly, using a long-range, license-free RF data link. Wireless communication is implemented using XBee Pro radio modules which independently manage packetization, addressing, error checking, and over-the-air transmission. 

To extend the reliable range of the wireless link, the base station's receive/transmit path is routed through an external patch antenna rather than relying solely on the XBee module's integral antenna.

---

## 3. Power System

* **Supply:** Power is supplied by 4 x Lithium-Iron (Li-Fe / LiFePO4) 2500 mAh, 3.7V cells, connected in series to form a single battery pack. Cells are spot-welded together in series (rather than soldered) to form a low-resistance, mechanically robust series stack. The resulting pack is housed in a custom 3D-printed enclosure, designed to mechanically secure the cells, provide impact protection, and route wiring cleanly to the BMS and power input connector.
* **Battery Management:** The series battery stack is interfaced with a 3S-rated Battery Management System (BMS) that serves as a protection circuit sitting between the raw cell stack and the rest of the power system. It is responsible for over-charge protection, over-discharge protection, over-current protection, and short-circuit protection.
* **Voltage Regulation:** The regulated output of the BMS is stepped down to the voltages required by the onboard electronics using two buck converters: 3.3V and 5V.

---

## 4. User Interface & Indicators

### Hardware Switches
* **Power Switch:** Controls the main power state of the base station.
* **Arming Switch:** Arms the recovery system and turns on the Armed LED to confirm status, enabling parachute deployment commands to go live.

### Status LEDs
| LED | Function |
| :--- | :--- |
| **Armed LED** | Illuminates when the arming switch has been actuated and the system has confirmed an armed state, signaling that parachute deployment commands are now live. |
| **Data LED** | Pulses/illuminates on receipt of valid telemetry packets from the Flight Computer, giving the operator a visual heartbeat of the downlink. |
| **Connection LED** | Indicates that a valid wireless link (XBee association) is established between the base station and the Flight Computer. |
| **4th LED** | Reserved/spare status indicator for additional fault or mode signaling. |

### Keypad Mapping (3x4 Matrix Keypad)
| Key | Action | Functionality |
| :---: | :--- | :--- |
| **0** | HELP | Prints full list of commands/key mapping to the laptop via Serial. |
| **1** | ARM | Arms the ESP32. |
| **2** | DISARM | Disarms the ESP32. |
| **3** | RESET | Sends Reset command to ESP32. |
| **4** | MAIN ON | Turns on main chute deployment. |
| **5** | MAIN OFF | Turns off main chute deployment. |
| **6** | Page Cycle | Cycles the LCD display through its 4 pages: `PAGE_MAIN` → `PAGE_ALT` → `PAGE_GPS` → `PAGE_PYRO` → back to `PAGE_MAIN`. Clears and redraws the LCD. |
| **7** | DROGUE_ON | Turns on drogue chute deployment. |
| **8** | DROGUE_OFF | Turns off drogue chute deployment. |
| **9** | STATUS | Prints a status string to the laptop over USB serial (Shows `"STATUS->USB"` on LCD row 3). |
| **\*** | XBee Toggle | Toggles a local boolean (`xbeeOnLocal`) and sends either `XBEE_ON` or `XBEE_OFF` to the ESP32 depending on the new state. *Note: this toggle is purely local and can desync if a command fails.* |
| **#** | Clear LCD | Clears the LCD screen and forces a full redraw of the current page. |

### LCD Display
A 16x2-character LCD display with an I2C interface module provides at-a-glance status information (e.g., link status, armed state, battery level) directly on the base station enclosure.

---

## 5. Base Station Controllers

### Arduino ATMEGA 2560 (Central Controller)
Responsible for:
* Managing the XBee Pro shield and the serial command/telemetry protocol to and from the Flight Computer.
* Scanning the keypad matrix and driving the I2C LCD display.
* Driving the Armed/Data/Connection status LEDs and reading the arming switch.
* Forwarding telemetry received over the XBee link to the ground PC over USB/serial, and forwarding commands from the PC/keypad to the XBee link.
* Communicating with the ESP32 module over UART for auxiliary data such as battery level.

### NodeMCU-32S (ESP32)
Handles auxiliary monitoring functions, primarily:
* **Battery-level sensing:** Reading the analog voltage from the resistor-divider network and computing the remaining battery state-of-charge.
* Links with the XBees and reports back to the Arduino MEGA 2560.

---

## 6. Fabrication

* **PCB Design:** The base station's circuit board was produced in-house using a PCB etching process. The copper-clad board was patterned and chemically etched to form the circuit traces, after which through-hole and surface-mount components were manually soldered onto the board.
* **Testing:** Continuity testing is performed across all etched traces after fabrication to verify that no open circuits (incomplete etches) or short circuits (etching defects/bridges) are present before populating the board with components.
* **Battery Casing:** The 4-cell Li-Fe battery pack is housed in a custom-designed, 3D-printed casing dimensioned specifically to the spot-welded cell stack, providing mechanical retention and protection.

---

## 7. Bill of Materials (BOM)

| Component | EasyEDA Footprint | Qty |
| :--- | :--- | :---: |
| Buck converter (3.3V) | MP1584EN-5V | 1 |
| Buck converter (5V) | MP1584EN-5V | 1 |
| Switches | KEY-SMD_L6.0-W3.6-LS8.0 | 2 |
| LED | LED-TH LED-3MM_RED | 4 |
| Capacitor 10µF | CAP-TH BD5.0-P2.00-D0.6-FD | 2 |
| Diode | DIODE-1N4001 | 2 |
| XT30 Connector | CONN-TH_XT30UPB-F | 1 |
| 330Ω Resistor | RESISTORS THROUGHHOLE: RESISTOR_HORIZONTAL_RM10MM-VG | 3 |
| 10kΩ Resistor | RESISTORS_THROUGHHOLE: RESISTOR_HORIZONTAL_RM10MM-VG | 1 |
| 6.2kΩ Resistor | RESISTORS THROUGHHOLE: RESISTOR_HORIZONTAL_RM10MM-VG | 1 |
| 1kΩ Resistor | RESISTORS THROUGHHOLE: RESISTOR HORIZONTAL RM10MM-VG | 1 |
| RF Amplifier (patch antenna) | CONN-TH_XT30UPB-F | 1 |
| Keypad (3x4) | KEYPAD3X4 | 1 |
| XBee Pro Shield V03 | XBEE PRO V03 SHIELD | 1 |
| Arduino ATMEGA2560 | ARDUINO_ATMEGA2560_UFFH | 1 |
| NodeMCU-32S (ESP32) | AI-THINKER_NODEMCU-32SLUA | 1 |
| LCD Display (16x2, I2C) | 16*2 I2C LCD DISPLAY WITH INTERFACE1 | 1 |
| Bluetooth Module | BLUETOOTH MODULE | 1 |

---

## 8. Pin Assignments

### Arduino ATMEGA 2560
| Pin | Function / Connection |
| :---: | :--- |
| **D16** | BT RX |
| **D17** | BT TX |
| **D20** | LCD SDA |
| **D21** | LCD SCL |
| **D30** | Arming Switch |
| **D32** | Armed LED |
| **D34** | Data LED |
| **D35** | Connection LED |
| **D41** | KEY R2 |
| **D43** | KEY R1 |
| **D45** | KEY C2 |
| **D47** | KEY R3 |
| **D49** | KEY C0 |
| **D51** | KEY R0 |
| **D53** | KEY C1 |
| **5V** | +5V |

### ESP32 (NodeMCU-32S)
| Pin | Function / Connection |
| :---: | :--- |
| **1 (Vin)** | +5V |
| **13 (p32)**| XBee 9 |
| **14 (p35)**| XBee 11 |
| **15 (p34)**| XBee 10 |
| **17 (svp)**| Battery Level |
| **19 (3.3v)**| +3.3V |
| **29 (P5)** | XBee 12 |
| **38 (GND)**| GND |

---

## 9. Circuit Schematic & Project Links

* **EasyEDA Schematic & PCB Editor:** [EasyEDA Project Link](https://easyeda.com/editor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)
* **ESP32 Firmware Code:** [esp32_xbee_i2c_bridge.ino on GitHub](https://github.com/nakujaproject/internship2025/blob/e6acc07d8d0487493078e238bd3c8c6412509ef3/recovery%20team/N4-code/N4-Flight-Software/n4-flight-software/test/base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)
* **Arduino MEGA Firmware Code:** [mega_base_station_controller.ino on GitHub](https://github.com/nakujaproject/internship2025/blob/e6acc07d8d0487493078e238bd3c8c6412509ef3/recovery%20team/N4-code/N4-Flight-Software/n4-flight-software/test/base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 station_controller.ino)

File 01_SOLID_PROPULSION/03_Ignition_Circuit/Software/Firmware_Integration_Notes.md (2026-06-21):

# Firmware Integration Notes

## Overview

This document explains how the Nakuja ignition system firmware components work together.

The system uses two ESP32 boards:

1. **Igniter Board** — reads sensor data and controls the ignition-output switching stage.
2. **Trigger Board** — receives telemetry from the igniter board, sends ignition commands, and forwards telemetry to the web dashboard.

The dashboard receives real-time telemetry from the trigger board through a WebSocket connection.

## Firmware Data Flow

```text
Igniter Board
    ↓
ESP-NOW telemetry
    ↓
Trigger Board
    ↓
Wi-Fi Access Point + WebSocket
    ↓
Web Dashboard
```

## Igniter Board Role

The igniter board is positioned near the motor or static test stand.

Main functions:

* Reads thrust from the load cell through the HX711.
* Reads temperature from the DS18B20 sensor.
* Reads pressure from the analog pressure interface.
* Receives ignition command from the trigger board using ESP-NOW.
* Controls the MOSFET-based ignition output.
* Sends telemetry to the trigger board.

## Trigger Board Role

The trigger board is positioned with the operator.

Main functions:

* Receives telemetry from the igniter board using ESP-NOW.
* Parses the received telemetry.
* Converts the telemetry into dashboard-compatible JSON.
* Creates a Wi-Fi access point named `NAKUJA`.
* Runs a WebSocket server on port `81`.
* Sends telemetry to the web dashboard.
* Sends the ignition command to the igniter board when the trigger input is activated.
* Provides local feedback through the LCD and buzzer.

## Telemetry Format from Igniter Board

The igniter board sends telemetry as a comma-separated string:

```text
thrust,temp,pressure
```

Example:

```text
12.8,27.5,101.3
```

Field order:

| Position | Field | Unit | Description |
| ---: | --- | ---: | --- |
| 1 | `thrust` | N | Load-cell thrust value |
| 2 | `temp` | °C | DS18B20 temperature value |
| 3 | `pressure` | kPa / configured unit | Pressure sensor/interface value |

## Telemetry Format Sent to Dashboard

The trigger board converts the received telemetry into JSON before sending it to the dashboard.

Expected JSON format:

```json
{
  "thrust": 12.8,
  "temp": 27.5,
  "pressure": 101.3,
  "ignition_armed": false
}
```

The dashboard reads:

| JSON Field | Used For |
| --- | --- |
| `thrust` | Thrust card and thrust chart |
| `temp` | Temperature card and temperature chart |
| `pressure` | Pressure card and pressure chart |
| `ignition_armed` | Event/status display |
| `event` | Optional event log message |

## Ignition Command Format

The trigger board sends the ignition command to the igniter board through ESP-NOW.

Current command:

```text
on
```

When the igniter board receives `on`, it starts the firmware ignition window and drives the MOSFET output for the configured duration.

## Important Safety Notes

* The ESP32 must not directly power the ignition load.
* The ESP32 output pin should only control the MOSFET switching stage.
* The ignition-output window is limited in firmware.
* A proper arming condition should be added when the final hardware arm switch is confirmed.
* Firmware testing must be done only under approved Nakuja Project safety procedures.

## Current Pin Summary

### Igniter Board

| Function | ESP32 Pin |
| --- | ---: |
| MOSFET gate | GPIO26 |
| HX711 DOUT | GPIO33 |
| HX711 SCK | GPIO32 |
| DS18B20 data | GPIO14 |
| Pressure analog input | GPIO13 |

### Trigger Board

| Function | ESP32 Pin |
| --- | ---: |
| Buzzer | GPIO18 |
| Status button | GPIO32 |
| LCD I2C address | `0x3F` |
| WebSocket port  | `81` |

## Integration Checklist

Before testing both boards together:

* [ ] Igniter firmware compiles successfully.
* [ ] Trigger firmware compiles successfully.
* [ ] `pitches.h` exists in the trigger firmware folder.
* [ ] ESP32 board package is installed.
* [ ] Required libraries are installed.
* [ ] Igniter board boots with ignition output LOW.
* [ ] Trigger board creates the `NAKUJA` Wi-Fi access point.
* [ ] Dashboard connects to the trigger board WebSocket server.
* [ ] Igniter board sends telemetry in `thrust,temp,pressure` format.
* [ ] Trigger board converts telemetry to JSON.
* [ ] Dashboard cards update correctly.
* [ ] Dashboard charts update correctly.
* [ ] CSV recording and download are tested.
* [ ] Ignition command is tested only under approved safe conditions.

## Known Pending Improvements

| Area | Status |
| --- | --- |
| Hardware arming input | Pending final pin confirmation |
| Pressure calibration | Pending final validation |
| Load-cell calibration factor | Requires final calibration confirmation |
| Brownout mitigation | Requires hardware validation |
| Offline dashboard libraries  | Future improvement |

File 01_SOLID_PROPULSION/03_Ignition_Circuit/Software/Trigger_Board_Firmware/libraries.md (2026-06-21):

# Required Libraries — Trigger Board Firmware

## Overview

This file lists the libraries required by the trigger board firmware.

## Libraries

| Library | Purpose |
|---|---|
| `WiFi.h` | Wi-Fi access point and ESP32 wireless setup |
| `esp_now.h` | ESP-NOW communication with the igniter board |
| `WebSocketsServer.h` | WebSocket server for dashboard telemetry |
| `ArduinoJson.h` | JSON formatting for dashboard packets |
| `LiquidCrystal_I2C.h` | 16x2 I2C LCD display support |
| `Arduino.h` | Core Arduino functions |
| `pitches.h` | Local note-frequency definitions for buzzer melody |

## Notes

- The firmware uses the ESP32 Arduino core.
- The receive callback uses the ESP32 core 3.x callback format.
- The send callback uses the ESP32 core 3.x `wifi_tx_info_t` format.
- Confirm the installed WebSockets library matches `WebSocketsServer.h`.
- Confirm the installed LCD library supports the `LiquidCrystal_I2C` class.
- Record tested library versions after successful compilation.

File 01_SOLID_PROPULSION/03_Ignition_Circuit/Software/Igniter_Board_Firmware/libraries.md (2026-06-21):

# Required Libraries — Igniter Board Firmware

## Overview

This file lists the libraries required by the igniter board firmware.

## Libraries

| Library | Purpose |
|---|---|
| `WiFi.h` | ESP32 Wi-Fi mode setup |
| `esp_now.h` | ESP-NOW communication |
| `HX711_ADC.h` | HX711 load-cell data acquisition |
| `OneWire.h` | OneWire communication for DS18B20 |
| `DallasTemperature.h` | DS18B20 temperature reading |
| `Arduino.h` | Core Arduino functions |

## Notes

- The firmware uses the ESP32 Arduino core.
- The receive callback uses the ESP32 core 3.x callback format.
- Confirm the installed HX711 library matches `HX711_ADC.h`.
- Record tested library versions after successful compilation.

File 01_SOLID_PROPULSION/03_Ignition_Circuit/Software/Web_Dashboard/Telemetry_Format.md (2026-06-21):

# Telemetry Format — Web Dashboard

## Overview

This document defines the telemetry data format expected by the Nakuja ignition system web dashboard.

The dashboard receives telemetry from the trigger board through a WebSocket connection. The trigger board receives telemetry from the igniter board and forwards it to the dashboard.

## Expected WebSocket Address

```text
ws://<ESP32_IP_ADDRESS>:81
```

Example:

```text
ws://192.168.4.1:81
```

## Expected JSON Packet

```json
{
  "temp": 27.5,
  "pressure": 101.3,
  "thrust": 12.8,
  "ignition_armed": false,
  "event": "Telemetry update"
}
```

## Field Description

| Field | Type | Unit | Description |
| --- | --- | ---: | --- |
| `temp` | Number  | °C | Temperature reading from the DS18B20 sensor |
| `pressure` | Number  |  kPa | Pressure reading from the pressure transmitter/interface |
| `thrust` | Number  | N | Thrust reading from the load cell and HX711 |
| `ignition_armed` | Boolean | - | Shows whether the ignition system is armed |
| `event` | String  | - | Optional event message displayed in the dashboard event log |

## CSV Export Format

The dashboard records telemetry in the following format:

```csv
Stopwatch Time (HH:mm:ss.ms),Temperature (°C),Pressure (kPa),Thrust (N)
```

Example:

```csv
00:00:00.000,27.50,0.00,0.00
00:00:00.250,27.60,0.50,0.20
00:00:00.500,27.70,1.20,0.50
```

## Notes

* The dashboard expects valid JSON packets.
* Invalid or missing numerical values may be ignored.
* The WebSocket server is expected to run on port `81`.
* The trigger board should send telemetry at a stable rate suitable for dashboard plotting.
* Simulated telemetry must be clearly labelled so it is not confused with real static-test data.

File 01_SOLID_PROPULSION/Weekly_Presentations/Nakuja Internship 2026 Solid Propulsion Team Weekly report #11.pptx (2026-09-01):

## Nakuja Internship 2026 Solid Propulsion Team Weekly report #11

Presented by: Ben Wetu

August 28, 2026

## This week's tasks

1. Cooking of grains
2. Liner preparation
3. Nozzle and bulkhead fabrication
4. 5 grain static test

## Cooking of grains for 5 & 4 grain test

Purpose: These grains will be used during the 5 grain static test was held on Wednesday 26/08/2026 and 4 grain on Friday 4/09/2026.
Result: 6 out of 9 grains have been prepared

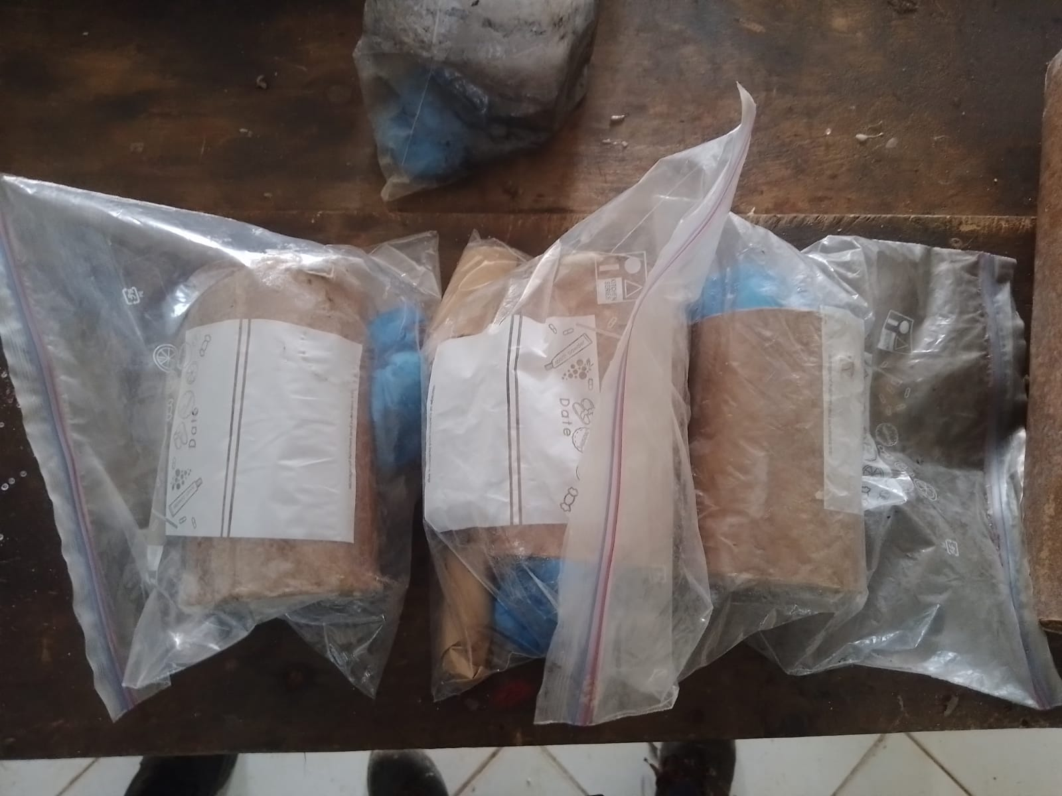
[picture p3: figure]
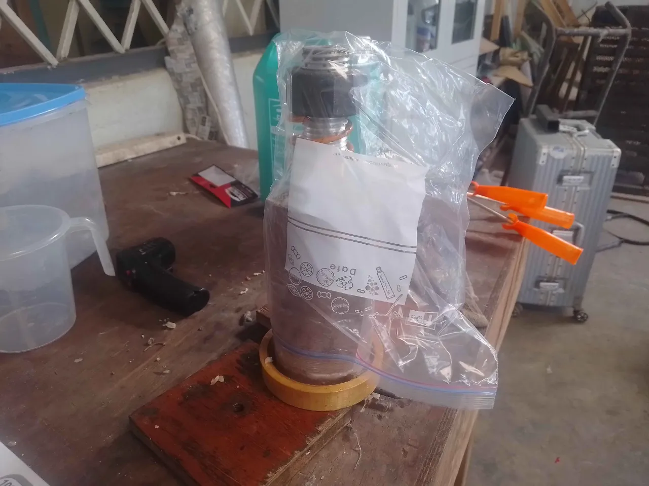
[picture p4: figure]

## 2. Liner preparation

Purpose: In preparation of the static tests campaign, we have fabricated 2 liners and both can fit the Aluminium and Stainless Steel dimensions.
Result: 6 out of 7 liners have been fabricated

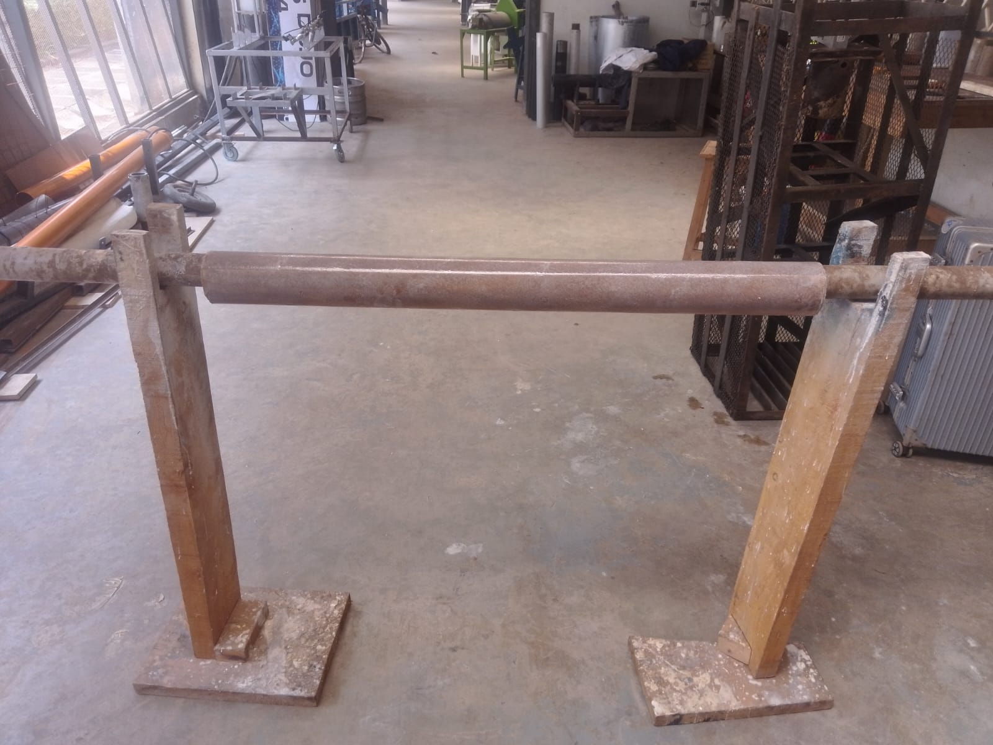
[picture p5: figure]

## 3. Machining of nozzle and bulkhead

Purpose: In preparation of the 4 grain static test, nozzle and bulkhead machining has began.
Result:

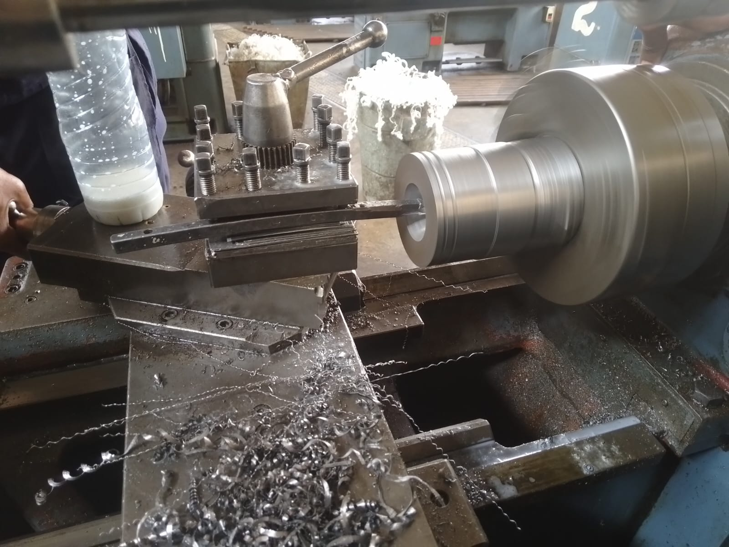
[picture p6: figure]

## 4. 5 grain static test

Purpose: This test was done in preparation for launch of the N4 rocket. 1.4g of Sodium Bicarbonate was added to each grain in an attempt to suppress the burn rate.
Result: The static test experienced CATO (Catastrophe At Take Off) as there was a rapid increase in pressure which caused the Solid Rocket Motor to explode.

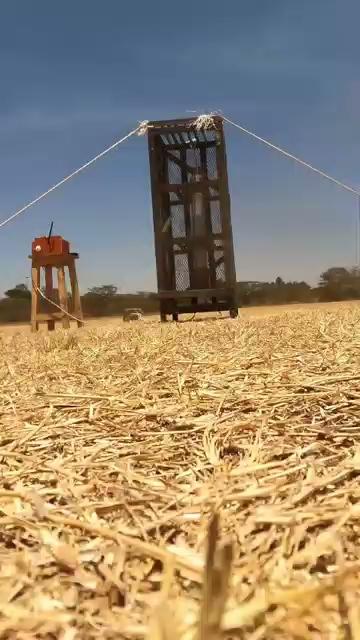
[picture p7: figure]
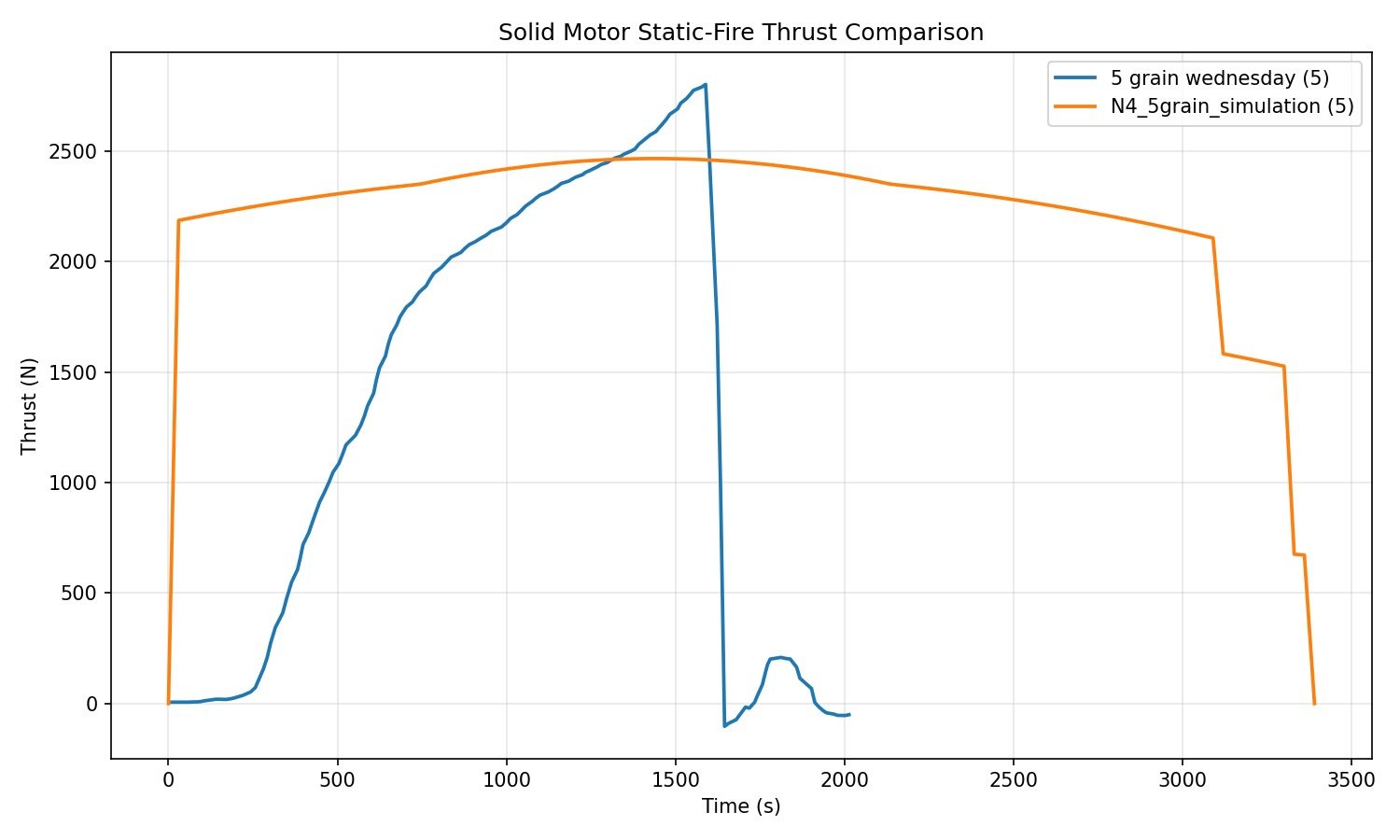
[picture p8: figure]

## Probable causes + solutions

1. Back burn -this was caused by movement of heat outside the thermal liner. This was because the liner had space between the casing.
Solution -use two liners for extra insulation. One continuous across the casing, another for individual grains.
1. Weak Aluminium alloy used -the Al 6063-T5 alloy used had a safety factor of 1.5 which decreases with increase in temperature.
Proposed changes:
1. Add 14g of Sodium Bicarbonate to the 5 grain test
2. Add 2.8g of Sodium Bicarbonate to 4 grain test

## Next week’s tasks

1. Motor assembly for 4 grain test
2. 4 grain static test using Stainless Steel dimensions
3. 5 grain static test with added suppressant
4. Compile report

## Challenges experienced

1. None experienced
Supervisors’ note:
Visit Solid Propulsion github projects @ https://github.com/orgs/nakujaproject/projects/26 to review the tasks done.

## Thank you for your attention!

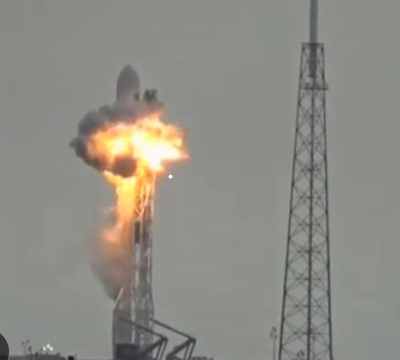
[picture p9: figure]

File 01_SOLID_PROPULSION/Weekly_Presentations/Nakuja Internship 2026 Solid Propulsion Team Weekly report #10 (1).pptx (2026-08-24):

## Nakuja Internship 2026 Solid Propulsion Team Weekly report #10

Presented by: Collins Kinyua

August 21, 2026

## This week's tasks

1. Cooking of grains for 4 grain test (stainless steel) & 5 grain test (Aluminium)
2. Machining of core rods
3. 3 grain static test
4. Liner preparation
5. One grain static test

## Cooking of grains for 5 grain test

Purpose: These grains will be used during the 5 grain static test which will be held on Wednesday 26/08/2026.
Result: 5 out of 9 grains have been prepared


## 2. Machining of core rods

Purpose: In preparation for mass production, the machining sub-team has been machining 3 new core rods to help increase number of grains cooked per day
Result: 3 out of 4 core rods complete

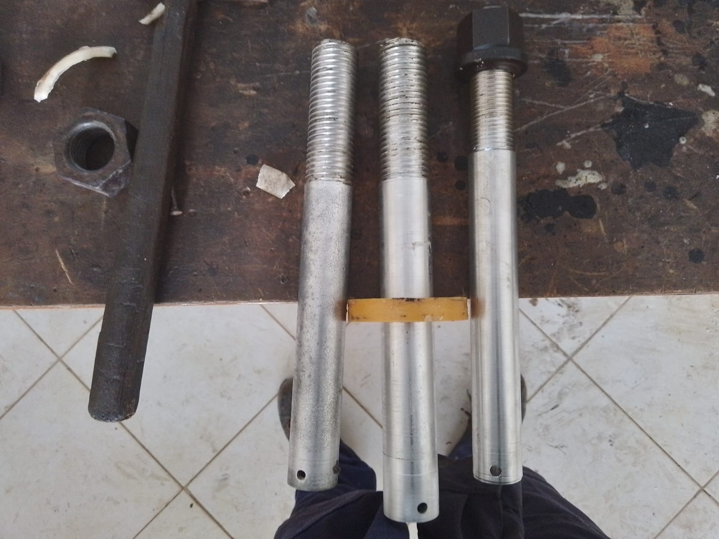
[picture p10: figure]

## 3. 3 grain static test

Purpose: This test was done in order to quantitatively verify the effect of adding 1% of Sodium Bicarbonate to the KNSB grains to act as a suppressant thus effectively lowering the peak thrust and by extension peak pressure values.
Result: The static test was a success with the data indicating lower thrust values than simulated one. The motor produced an ISP which was 89.69% of the theoretical maximum.
Results from previous test

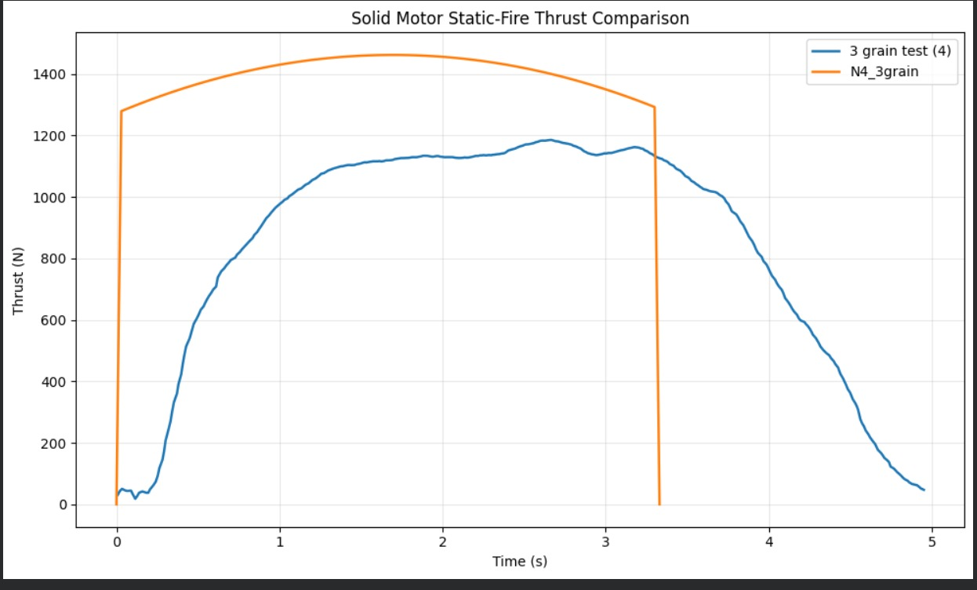
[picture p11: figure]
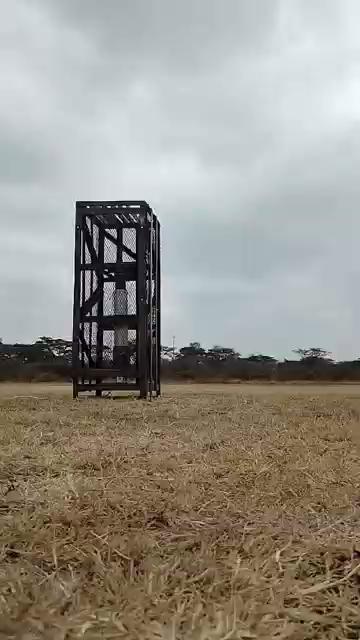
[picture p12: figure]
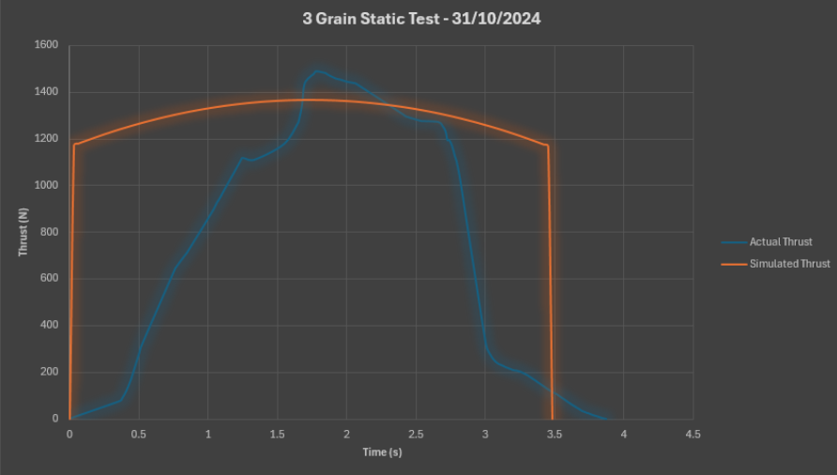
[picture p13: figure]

## 4. Liner preparation

Purpose: In preparation of the static tests campaign, we have fabricated 2 liners and both can fit the Aluminium and Stainless Steel fabrication.
Result: 5 out of 6 liners have been fabricated

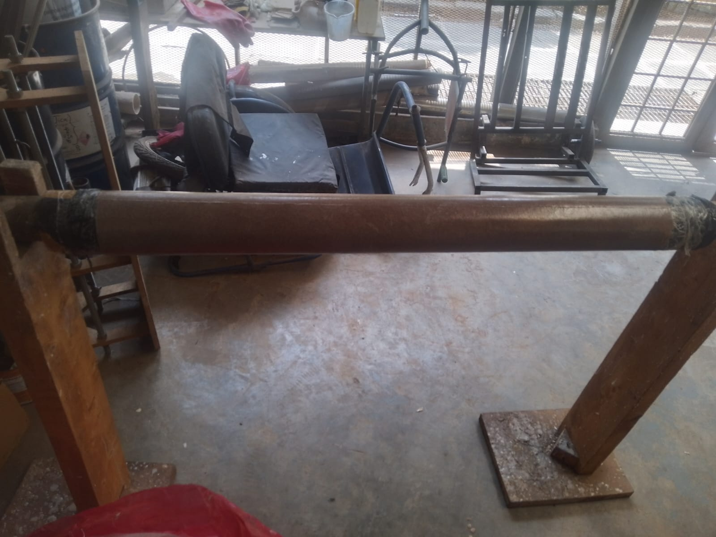
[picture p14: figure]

## 5. One grain static test: Cured after 2 weeks vs 3 days

Purpose: This static test was done in order to make a quantitative decision on the curing time for KNSB propellant grain. According to Richard Nakka, he states that for KNSB grains need one or two days prior to demoulding i.e removing the core rod (we remove the core rod after a day) after which the grains have fully cured and solidified. He also states that full curing may take a week but is is perfectly acceptable to fire a grain anytime after demoulding. https://www.nakka-rocketry.net/sorb.html
As observed from the first static test i.e. grain cured after 2 weeks, the longer the grain stays in storage, the higher the chances of being exposed to moisture which lowers the quality of the grain.
Conclusion: Curing time shall be 5 days instead of 3 to allow the grain to solidify properly
Results from 2 weeks cured Results from 3 days cured

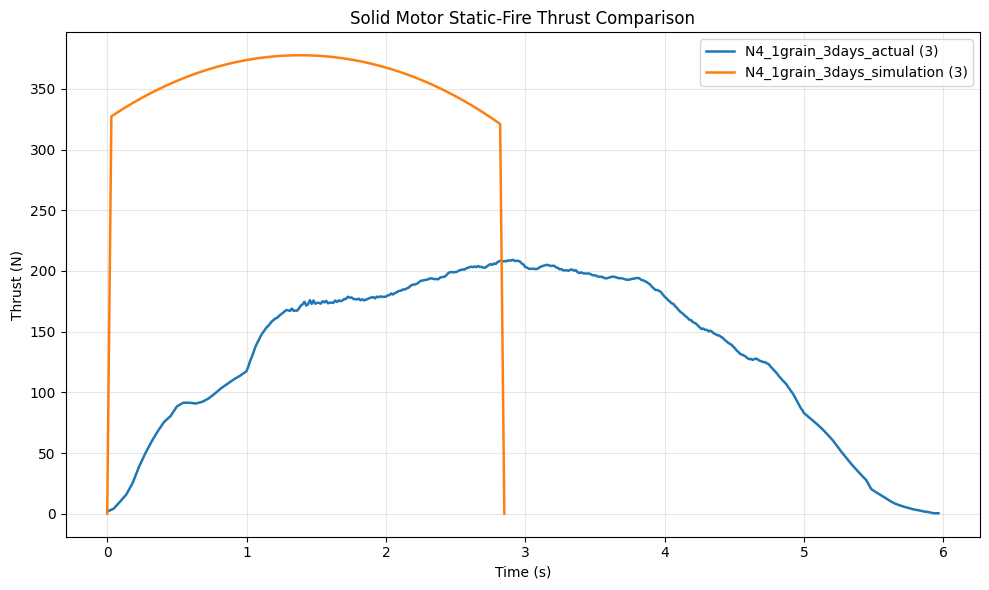
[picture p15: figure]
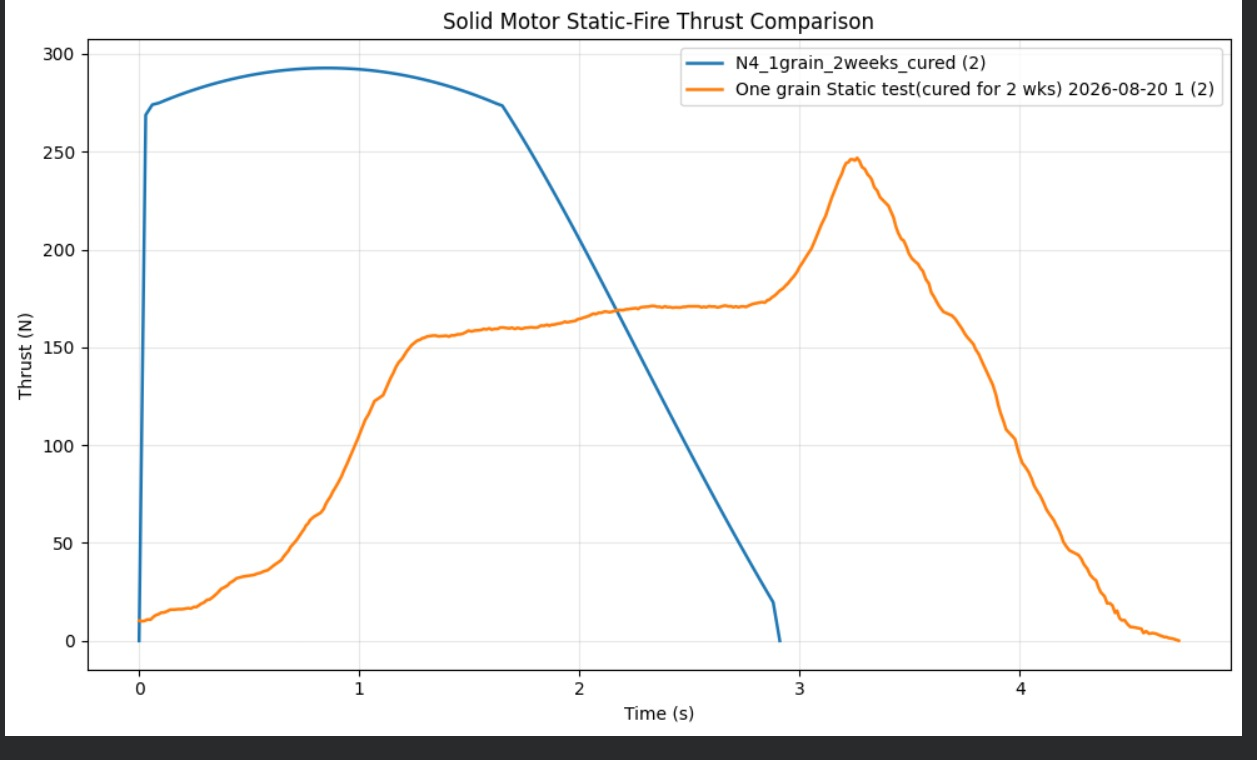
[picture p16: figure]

## Next week’s tasks

1. 5 grain static test
2. Motor assembly for 4 grain stainless steel casing
3. Cooking of grains
4. Liner preparation
5. Nozzle and bulkhead fabrication

## Challenges experienced

1. Transport of the test stand using a wheelbarrow has become tedious and is creating internal friction.
Supervisors’ note:
Visit Solid Propulsion github projects @ https://github.com/orgs/nakujaproject/projects/26 to review the tasks done.

## Thank you for your attention!

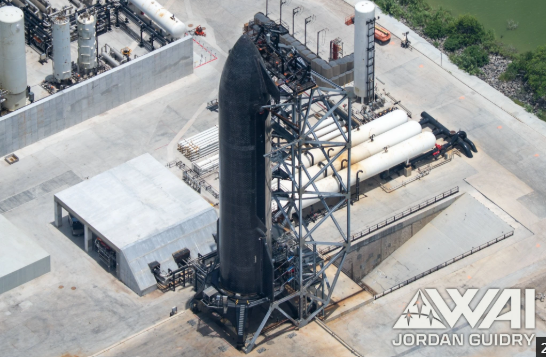
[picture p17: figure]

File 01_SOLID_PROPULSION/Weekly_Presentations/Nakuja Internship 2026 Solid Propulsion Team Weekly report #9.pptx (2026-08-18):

## Nakuja Internship 2026 Solid Propulsion Team Weekly report #9

Presented by: Paschal Peter

August 17, 2026

## Last week’s tasks

1. Cooking of grains for 3 grain static tests
2. Machining of core rods
3. Motor assembly for 3 grain test
4. Static test dry run (To test new ignition circuit hardware)
5. Liner preparation
6. Ignitor preparation

## Cooking of grains for 3 grain test

Purpose: These grains will be used during the 3 grain static test which will be held on Monday 17/08/2026.
Result: 3 out of 12 grains have been prepared


## 2. Machining of core rods

Purpose: In preparation for mass production, the machining sub-team has been machining 3 new core rods to help increase number of grains cooked per day
Result: The Aluminium 7075 core rods were turned to a diameter of 38 mm from 50 mm, the remaining operation is threading and once done be Monday 17/08/2026, the propellant sub-team can now easily mass-produce the propellant grains.

## 3. Motor assembly for 3 grain test

Purpose: In preparation for the 3 grain test, the propellant sub-team has been drilling, tapping and assembling the dry Solid Rocket Motor. This test will be done on Monday 17/08/2026
Result:

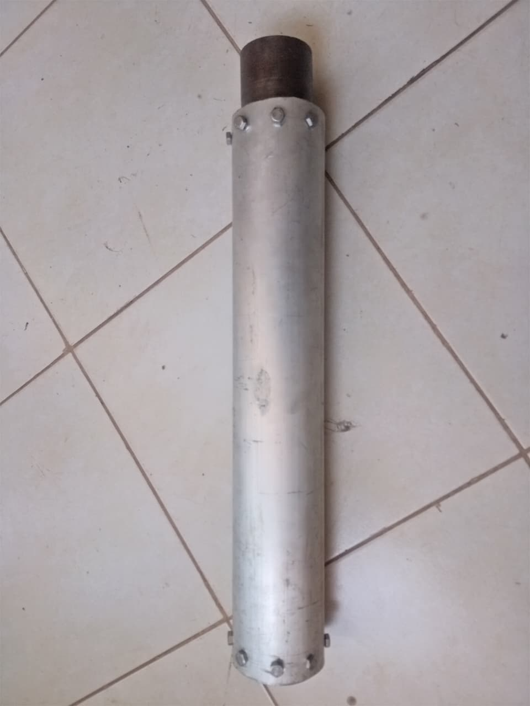
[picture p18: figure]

## 4. Static test dry run

Purpose: On addition of new hardware i.e. 3D printed case, LCD screen etc, the ignition subteam performed a dry run to ensure the ignition circuit was working (both trigger and igniter).
Result: The dry run was a success and we can proceed with the static test on Monday.

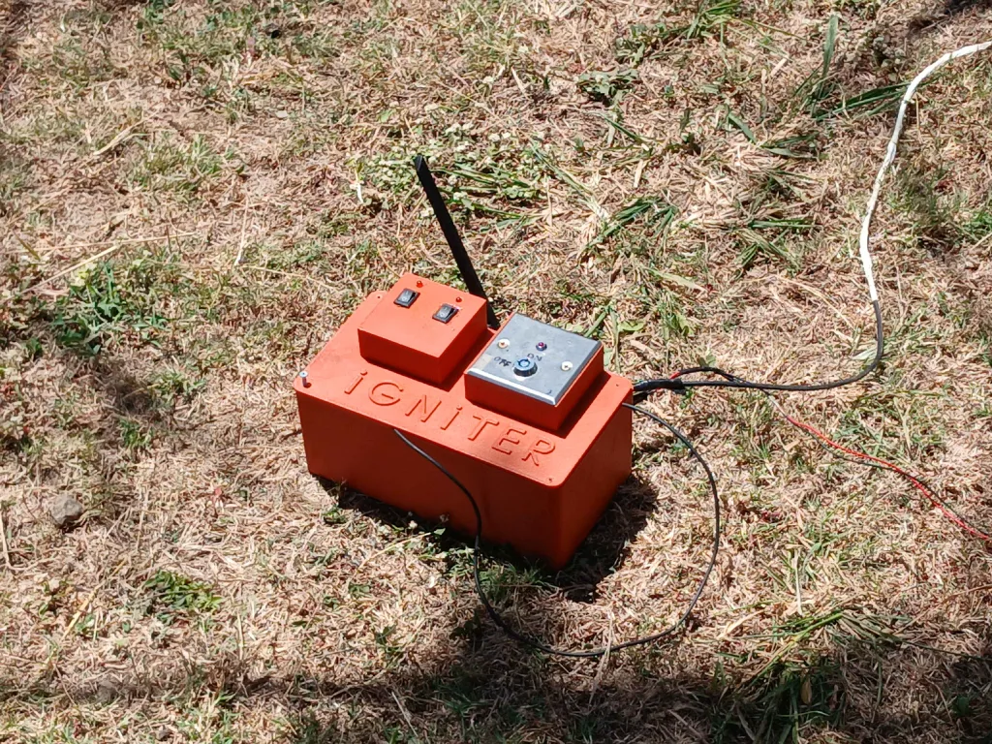
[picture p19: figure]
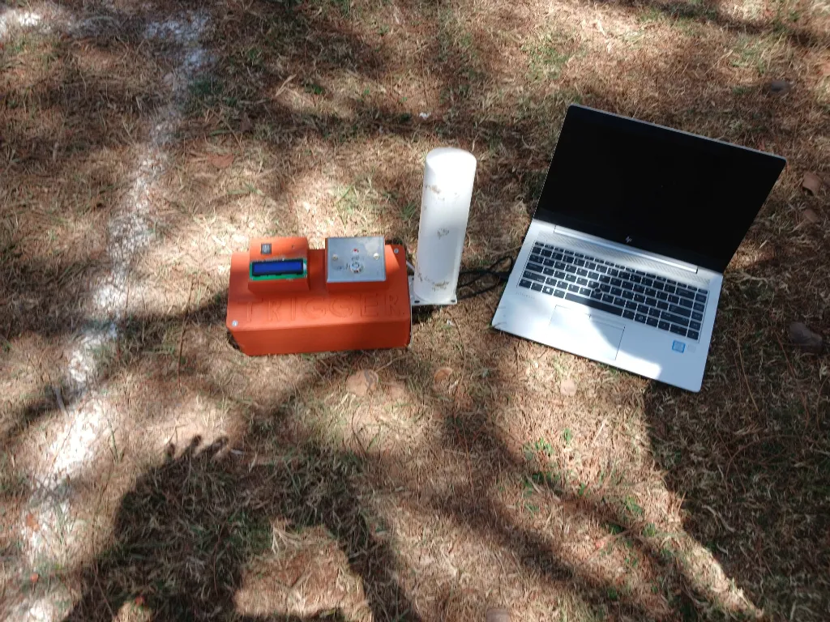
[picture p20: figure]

## 5. Liner preparation

Purpose: In preparation of the static tests campaign, we have fabricated 2 liners and both can fit the Aluminium and Stainless Steel fabrication.
Result: 3 out of 6 liners have been fabricated


## 6. Ignitor preparation

Purpose: In preparation for the static test campaign (3, 4 & 5 grain), the propellant sub-team prepared 3 whole ignitors which will be subdivided by mass later (20 g is used per static test) and will be used during the upcoming static test.
Result:

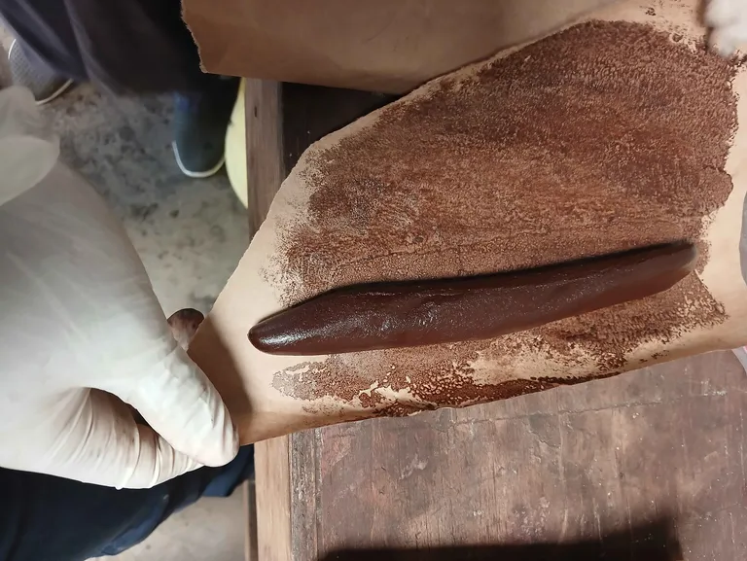
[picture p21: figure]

## This week's tasks

1. 3 grain static test
2. Cooking of grains for 4 grain test (stainless steel) & 5 grain test (Aluminium)
3. Machining of core rods
4. Machining of nozzle and bulkhead for 4 grain stainless steel Solid Rocket Motor.

## Challenges experienced

1. None
Supervisors’ note:
Visit Solid Propulsion github projects @ https://github.com/orgs/nakujaproject/projects/26 to review the tasks done.

## Thank you for your attention!

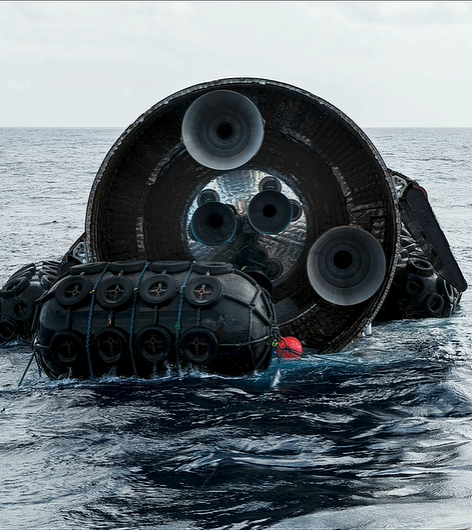
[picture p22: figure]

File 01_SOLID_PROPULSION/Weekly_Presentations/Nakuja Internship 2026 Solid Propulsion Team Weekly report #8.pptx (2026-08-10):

## Nakuja Internship 2026 Solid Propulsion Team Weekly report #8

Presented by: Bravin Limuli

August 7, 2026

## This week’s tasks

1. Update of static test procedure
2. Cooking of grains for 3 grain static test
3. Ignition circuit fabrication
4. Liner preparation
5. Purchasing of items

## Update of static test procedure

Purpose: Upon discussion with the supervisors, we decided to perform 3 static tests before mass production begins.
Here is the critical path documentation for the three planned static tests: https://github.com/nakujaproject/Internship-2026/blob/main/01_SOLID_PROPULSION/Static_Tests/N4%20Version%201%20%26%202%20%E2%80%93%20Final%20Test%20Campaign%20%26%20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

Static Test number | Casing material | No. of grains | Date planned
8 | Aluminium 6063-T5 | 3 | Monday 17/08/2026
9 | Stainless steel G 304 SCH 10 | 4 | Friday 21/08/2026
10 | Aluminium 6063-T5 | 5 | Monday 24/08/2026

## 2. Cooking of grains

Purpose: In-line with the planned static tests, the propellant sub-team has started grain preparation which will be used for the 3 grain test.
Result: 1 out of the planned 12 grains has already been prepared.

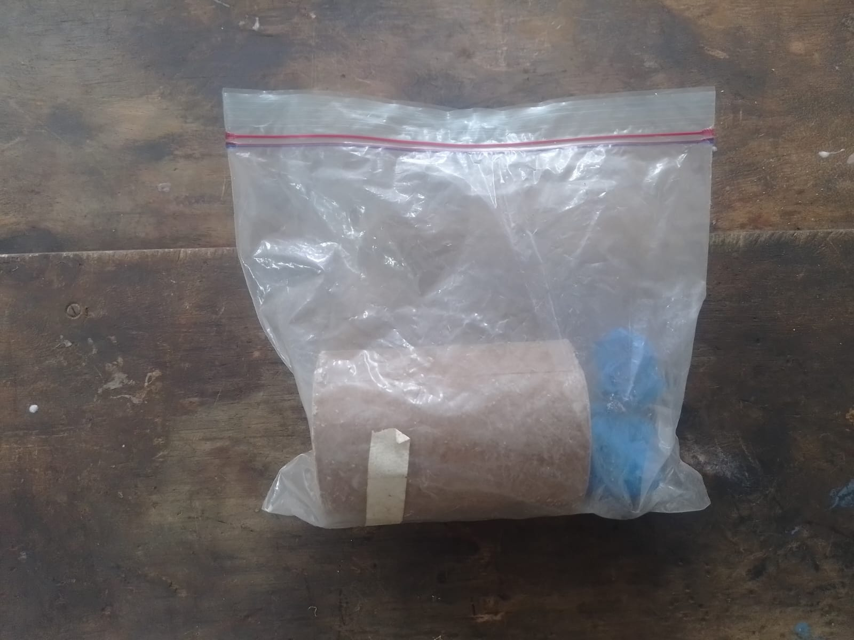
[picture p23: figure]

## 3. Ignition circuit fabrication

Purpose: In preparation for the upcoming static test campaign, the ignition circuit sub team has been fabricating a new ignition circuit which will be used.
Changes made:
1. Use of a perfboard instead of Printed Circuit Board (PCB) for easy repair and maintenance
2. Use of a relay instead of MOSFET
3. Addition of 3D printed case to improve reliability and protection during field tests

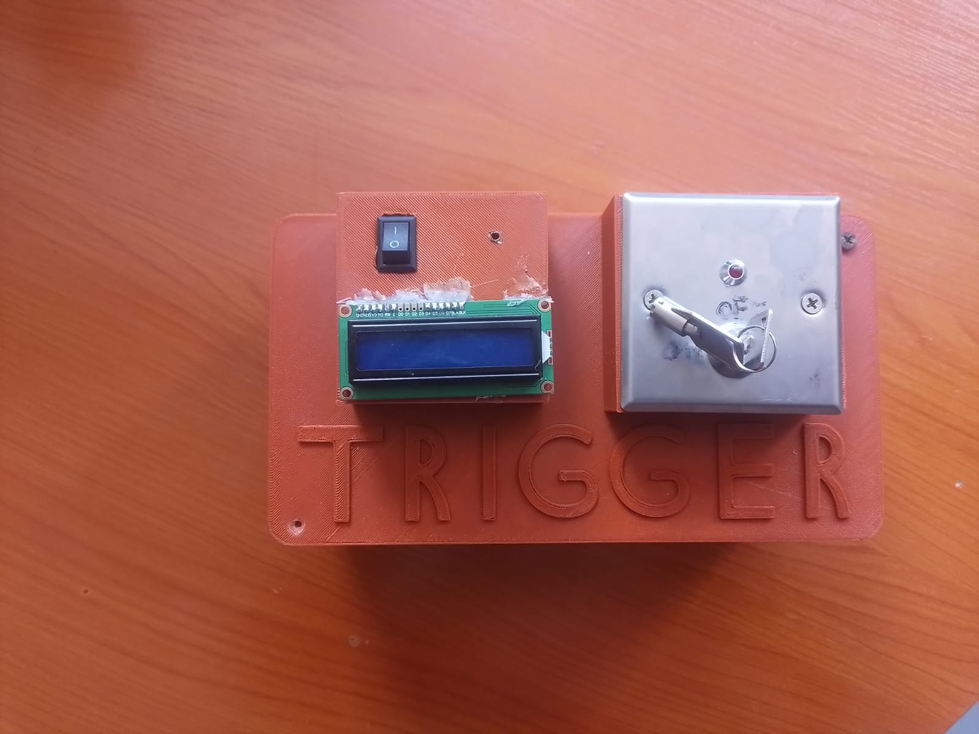
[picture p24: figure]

## 4. Liner preparation

Purpose: In preparation of the static tests, we have fabricated 2 liners and both can fit the Aluminium and Stainless Steel fabrication.
Result: 2 out of 4 liners have been fabricated


## 5. Purchasing of items

Purpose: In preparation for the upcoming static test, critical materials have to be purchased, here is the link to the purchase request for the 2nd disbursement: https://docs.google.com/spreadsheets/d/1ItQDAlRLaYcg9si493R-wpe7q-Kaqn-85Dn_sr7F3AY/edit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

## Next week's tasks

1. Cooking of grains for 3 grain and 5 grain static tests
2. Machining of core rods
3. Motor assembly for 3 grain test
4. Static test dry run (To test new ignition circuit hardware)
5. Liner preparation

## Challenges experienced

1. Poor internet connectivity.
Supervisors’ note:
Visit Solid Propulsion github projects @ https://github.com/orgs/nakujaproject/projects/26 to review the tasks done.

## Thank you for your attention!


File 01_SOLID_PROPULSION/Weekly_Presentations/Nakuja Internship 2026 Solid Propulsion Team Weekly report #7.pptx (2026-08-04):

## Nakuja Internship 2026 Solid Propulsion Team Weekly report #7

Presented by: Lynn Talam

July 31, 2026

## Tasks completed this week

1. 3D printed top and bottom plate for new casting tool design
2. Outlined procedure for N4 Version 2 Solid Rocket Booster production
3. 3D print trigger circuit casing
4. Mandrel fabrication to fit new dimensions
5. One grain static test (control and suppressant)

## 3D printed top and bottom plate for the new casting tool design

Purpose: Due to change in dimension for the grain diameter (Outer diameter increased from 86 mm to 104 mm), the team had to re-design the casting tools to fit this dimensions. One out of four casting tools have been printed.
Result:


## 2. Outlined procedure for N4 Version 2 SRB manufacturing

Reason for Version 2 change:
- Change in casing material from Aluminium A6063-T5 to stainless steel G 304 schedule 10
- Increase in motor outer diameter from 100 mm to 114 mm
- Improvement in grain preparation (curing under pressure, fine milled KNO3)
- Reduction in number of grains from 5 to 4 to reduce peak thrust to the target value of ~2322N
Documentation for critical path to N4 version 2 SRB manufacturing: https://github.com/nakujaproject/Internship-2026/blob/main/01_SOLID_PROPULSION/Static_Tests/Four_Grain_Test/Critical%20Path%20For%20N4%20Version%202%20Solid%20Rocket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

## 3. 3D print igniter circuit casing

Purpose: In order to protect the ignition circuit during static test and launch, the ignition sub-team designed and outer casing to protect the PCB during field tests.
Result:


## 4. Mandrel fabrication to fit new dimensions

Purpose: In order to fit the new dimensions for the outer diameter of the grain, the propellant subteam fabricated a new mandrel which will be used during liner fabrication.
Result:


## 5. One grain static test #6: Control test

Purpose: Due to exposure and entry of moisture during the first control static test, the propellant subteam prepared another grain and it was fired during the 6th static test. This grain will be used as our reference point when making any potential changes to the grain.
Result:


## 6. One grain static test #7: Addition of suppressant (Sodium Bicarbonate)

Purpose: Following the control static test, a second test was carried out using a KNSB grain with 1% sodium bicarbonate suppressant added to evaluate whether it’ll reduce thrust output.
Result: The SRM produced ~76% of the theoretical ISP and the peak thrust was slightly below simulated values indicating excellent performance of the suppressant.
Unfortunately, no video footage was captured as the SD card in the GoPro was full at the time of the static test.


## Next week’s tasks

1. Cooking of grains for 4 grain static test
2. Old grains disposal
3. Purchasing of items
4. Liner preparation
5. Liner thickness testing (Burn test)
6. Ignition circuit fabrication
7. Ignitor preparation and testing

## Challenges experienced

1. Poor internet connectivity.
Supervisors’ note:
Visit Solid Propulsion github projects @ https://github.com/orgs/nakujaproject/projects/26 to review the tasks done.

## Thank you for your attention!


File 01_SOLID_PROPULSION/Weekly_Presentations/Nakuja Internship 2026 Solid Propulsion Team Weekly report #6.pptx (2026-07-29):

## Nakuja Internship 2026 Solid Propulsion Team Weekly report #6

Presented by: BenCollins Mureithi

July 24, 2026

## Tasks completed this week

1. Cooking of grains for testing (control grain + suppressant)
2. One grain static test (surfactant, suppressant)
3. Old grains disposal
4. Test stand analysis
5. 3D print igniter circuit cover
6. 5 grain motor design + open rocket simulation
7. Drafting of a purchase request for second disbursement

## Cooking of propellant grain to be used as control

Purpose: Upon data analysis from the first one grain static test, we discovered an unusually long burn time which is an indicator of moisture presence in the propellant grain. This suggests that the data collected does not reflect the true performance of the grain thus the one grain test for the control grain has to be repeated while preventing moisture entry as our main objective.
Mitigation strategy: After cooking the grain and motor assembly, it shall be stored in a ziplock bag at all times.
Grain during storage: Solid Rocket Motor before static test:


## 2. One grain static test # 3 & 4 - Addition of surfactant

Purpose: Two one grain static tests were performed for grains containing 1% Sodium Laureth Sulphate (SLES) and 0.1% Sodium Lauryl Sulphate (SLS) in an attempt to mitigate air bubbles and voids, both of which produced similar results. The thrust output from both tests indicate that they cannot be used for motor integration.
Recommendation: SLS or SLES cannot be used for KNSB propellant grains as it suppresses the burn rate which affects the thrust output negatively.
Alternative: Use Lecithin


## 3. One grain static test #5 -Addition of suppressant

Purpose: Upon analysis from previous static tests, we noticed that the actual thrust often exceeds the simulated thrust. To mitigate this observation, we decided to add a suppressant to the KNSB grain.
Challenge encountered: Upon performing the one grain test #5, the test was successful except 1 major issue, due to a faulty load cell, we were not able to retrieve the thrust values generated by the static test. This necessitated purchasing of a new load cell as the one we have has been causing issues all through the test campaign.
Thrust curve from previous tests: Static test video: Faulty load cell:


## 4. Old grains disposal

Purpose: In an attempt to free up the inventory of old grains, the team decided to dispose some of the old propellant grains which were cooked by the previous teams. The grains were disposed remotely in batches of 6 inside a trench located at the baseball pitch at a safe distance of 30m


## 5. Test stand analysis

Purpose:To determine if the test stand could topple in a multi-grain static test. The designer from the previous team said it couldn't as the more the thrust the more stable it gets as its being pressed downward. However, the Load cell support should be reinforced further as the current one yielded in their last five grain test.


## 6. 3D printing igniter circuit cover

Purpose: The ignition circuit (trigger and ignitor circuit) fabricated by previous teams did not have any external shielding thus components were exposed to the physical elements which affected the reliability of the circuit as we noticed from the dry runs we conducted. This necessitated design and fabrication of a new case in order to improve the durability and reliability of the ignition circuit system.
Result:


## 7. 5 grain motor design + open rocket flight simulation

Purpose: In preparation for the 5 grain static test, we had to redesign the 5 grain configuration to fit the new dimensions of the new stainless steel casing.
Major change: Since our current casing has a wider diameter, this has led to a corresponding increase in propellant mass hence thrust, which in turn exceeds our target apogee from 3.5 Km to ~5 Km.
The thrust output of the new SRM cannot be reduced to a four grain as we will not reach the target apogee.


## 8. Drafting of purchase request for second disbursement

Purpose: As a result of continuous work being done on the project, most consumables i.e Sorbitol, Latex gloves etc have started to get depleted. This has led us to draft a purchase request with proper justification in order to restock some of the utilised materials and also replacement of faulty items.
Link to the new purchase request: https://docs.google.com/spreadsheets/d/1ItQDAlRLaYcg9si493R-wpe7q-Kaqn-85Dn_sr7F3AY/edit?usp=sharing

## Next week's tasks

1. Ignitor preparation and testing
2. Purchasing of items
3. One grain static test
4. Old grains disposal
5. Liner thickness testing (Burn test)
6. Load cell sensitivity analysis
7. 3D print trigger circuit casing

## Challenges experienced

1. Faulty load cell led to no data being recorded during the 5th static test
2. Unavailability of project car led us to use a wheelbarrow to transport the test stand which was tedious.
Supervisors’ note:
Visit Solid Propulsion github projects @ https://github.com/orgs/nakujaproject/projects/26 to review the tasks done.

## Potential concerns

1. Team members i.e. Recovery and Solid Propulsion are required to clean their respective working areas (Rapid Prototyping 1 and Exhibition Space) 15 mins before closing time every working day.
2. The purchased pipe has a ‘flash' which might act as a failure point during the 5 grain static test.


## Thank you for your attention!


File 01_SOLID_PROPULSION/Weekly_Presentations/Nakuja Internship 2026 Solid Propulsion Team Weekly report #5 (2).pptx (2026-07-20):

## Nakuja Internship 2026 Solid Propulsion Team Weekly report #5

Presented by: Collins Kinyua

July 17, 2026

## Tasks completed this week

1. Cooking of grains for one grain static test (addition of surfactant & suppressant)
2. Pyrogenic ignitor cooking and testing
3. Purchasing of items i.e. Stainless steel casing, crafting paper
4. Design and fabrication of new igniter circuit
5. One grain static fire test

## 1. Cooking of grain for static test – Addition of surfactant

Purpose: This grain contained ~1.8% of Sodium Laureth Sulphate (SLES) which is used as a surfactant i.e. it lowers the surface tension between the fuel (Sorbitol) and oxidizer (KNO3) which improved castability and removed air bubbles.
Major breakthrough: We were able to mitigate voids and air bubbles within the grains
Grain during cooking: Grain after curing: Grain core:


## 2. Cooking of pyrogenic igniter and testing

Purpose: This ignitor contained a new cooking method in an attempt to increase the burn rate of the ignitor by using black powder in the middle section of the ignitor and as our main pyrogen to generate required temperature and pressure while the KNSB is used as the binder.

## 3. Purchasing of items i.e. Stainless steel casing & craft paper

Purpose: This was done in preparation for the five grain test, the Stainless Steel G 304 schedule 10 round tube will be used as the casing while the craft paper will be used as ablative liner.


## 4. Design and fabrication of new trigger circuit

Problem statement: During last weeks’ (10/07) dry run and static test, the igniter circuit proved to be unreliable as we experienced various faults i.e. Miss-fire, incorrect data from load cell, short circuit that destroyed a mosfet.
Due to this challenges, the ignition circuit sub-team decided to fabricate a new pcb which to improve on reliability.
Result:


## 5. One grain static test #1

Purpose: This test was done as a control variable using the current grain preparation methods and the data will be compared against subsequent tests.
Video footage: Thrust curve comparison:


## 6. One grain test #2

Purpose: This test was done with a propellant grain with an altered Oxidiser to Fuel ratio of 60:40 as opposed to the standard 65:35, which means that the propellant is fuel rich which should correspond to a lower thrust output. This was done in an attempt to lower the thrust output.
Video footage: Thrust curve:


## Next week's tasks

1. Ignitor preparation and testing
2. Cooking of grains for testing
3. One grain static test
4. Old grains disposal
5. Liner thickness testing (Burn test)
6. Motor assembly for one grain test
7. 3D print ignition circuit casing

## Challenges experienced

1. Unavailability of power led to delays in 3D printing.
2. Unavailability of project car led us to use a wheelbarrow to transport the test stand which was tedious.
Supervisors’ note:
Visit Solid Propulsion github projects @ https://github.com/orgs/nakujaproject/projects/26 to review the tasks done.

## Potential concerns

1. Due to a higher expected thrust output value for the five grain test, our load cell cannot record the expected peak thrust thus a new load cell is required.
2. An increase in Solid Rocket Motor diameter and requires redesign of the body tube and flight computer avionics bay to compensate for this change.

## Thank you for your attention!


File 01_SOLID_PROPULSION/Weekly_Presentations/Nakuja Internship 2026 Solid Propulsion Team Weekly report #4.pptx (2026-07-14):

## Nakuja Internship 2026 Solid Propulsion Team Weekly report #4

Presented by: Paschal Peter

July 10, 2026

## Tasks completed this week

1. Pyrogenic ignitor testing
2. Cooking of grains for one grain static test
3. Catalyst determination from Chemistry labs
4. Dry run
5. One grain static fire test

## Pyrogenic ignitor testing

Purpose: For effective Solid Rocket Motor (SRM) ignition, the pyrogenic ignitor used has to have a very short burn time to provide as much heat to the grains as possible and reach the required SRM chamber pressure.
The first test done was to try to reduce the burn time of the ignitor by increasing the number of nichrome wires in the ignitor from one to three.
Previous design: New design:
Result: This resulted in a shorter burn time i.e 5.25 seconds for the previous design and 5.12 seconds for the new design, a 2.5% improvement. Our aim is to reduce the burn time upon subsequent tests.


## 2. Cooking of grains for one grain static test

Purpose: Two Potassium Nitrate & Sorbitol (KNSB) propellant grains were prepared using the standard procedure documented here (https://github.com/nakujaproject/Internship-2026/blob/main/01_SOLID_PROPULSION/01_Propellant/Grains/GrainProcedure%20Update%202.pdf). This KNSB grain will be used as the control for our grain analysis test campaign.
The second prepared grain had an altered oxidiser to fuel ratio of 60:40 as opposed to the standard 65:35 making a slightly fuel rich mixture in an attempt to reduce thrust output
Control grain: Fuel rich propellant:


## 3. Catalyst determination from chemistry labs

Purpose: This experiment was done to help theoretically determine the correct epoxy to catalyst ratio to be used during liner preparation. Fourier-transform infrared spectroscopy (FTIR) and Atomic Absorption Spectroscopy (AAS) tests were done.
Result: The report is currently being written and will be uploaded to github once complete. The following were the FTIR test results. We await AAS test results.


## 4. Dry run

Purpose: This was done in preparation of the static test which is to be held on Friday 10/07/2026 and these were the objectives met:
a. Verify remote ignition circuit functionality using an empty Solid Rocket Motor (SRM).
b. Practice team coordination, timing, and emergency procedures.
c. Measure total setup-to-ignition time. 1hr 5mins (2:55 pm to 4pm) in our third attempt
d. Ensure all members are familiar with roles and safety protocols.
e. Identify any issues before the actual static test.
Challenges faced:
a. Load cell battery failure
b. Uncommanded ignition failure
The dry run report is documented here (https://github.com/nakujaproject/Internship-2026/blob/main/01_SOLID_PROPULSION/Static_Tests/One_Grain_Tests/dry_run_report.pdf) with the relevant photos and video uploaded to the joint album.

## 5. One grain static fire test

Purpose: This one grain static fire test will be used as the control or reference test in the coming subsequent tests. We will gather the data from this test and use it to improve our propellant grains.
Result: The static fire test was unsuccessful due to a faulty ignition wire which caused a short circuit which destroyed the mosfet, thus ignition did not take place.

## Next week's tasks

1. Pyrogenic ignitor testing
2. Cooking of grains for one grain static test
3. Liner thickness testing (Burn test)
4. Purchasing of items i.e. Stainless steel casing, crafting paper
5. Nozzle and Bulkhead machining
6. 3D print ignition circuit casing
7. One grain static fire test

## Challenges experienced

1. None encountered
Supervisors’ note:
Visit Solid Propulsion github projects @ https://github.com/orgs/nakujaproject/projects/26 to review the tasks done.

## Potential concerns

1. The load cell has a rating of 3000N while our expected peak thrust is 2500N which might require replacement of load cell
2. Concerns on test stand stability

## Thank you for your Attention!


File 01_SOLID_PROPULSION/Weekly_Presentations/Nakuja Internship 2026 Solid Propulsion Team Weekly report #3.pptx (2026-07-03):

## Nakuja Internship 2026 Solid Propulsion Team Weekly report #3

Presented by: Ben Wetu

July 3, 2026

## Tasks completed this week

1. Cooked one propellant grain
2. Prepared 3 pyrogenic ignitors
3. Validated the error we got from open motor for the one grain test
4. Motor assembly
5. Designed a new ignitor circuit casing

## Cooked one grain

Purpose: This Potassium Nitrate & Sorbitol (KNSB) propellant grain will be used as the control grain for the upcoming grain analysis and testing campaign. This propellant grain will be used for microscopic analysis to determine the number of voids or air bubbles formed during the curing process.
The grains were compressed with a force of 236.88 N with a compression length of 2.8 cm. The spring details are here (https://docs.google.com/document/d/1tc-LvfmBLr1dBrcV1fSMpZ0FVgUXRoszm2JYe_RCPrE/edit?usp=sharing).
Sections for microscopic analysis:


## 2. Preparation of pyrogenic ignitor

We embarked on designing a new pyrogenic ignitor by adding Black Powder (Potassium Nitrate, Sulphur, Charcoal) to the previous KNSB + FeO3 ignitor.
This was done to improve the ignition properties of the pyrogenic ignitor thus leading to a faster and more reliable Solid Rocket Motor ignition with the right chamber pressure.
Tests on the new ignitor design shall be done next week.


## 3. Error validation from Open Motor

Upon simulating, the motor performance for the one grain test, we encountered an open motor error; low exit pressure nozzle flow may separate but upon research from Richard Nakka and consulting with early N4 members, we concluded the following (full documentation available here (https://github.com/nakujaproject/Internship-2026/tree/main/01_SOLID_PROPULSION/Static_Tests/One_Grain_Tests)) also uploaded to github:
1. No need to change the grain diameter and nozzle size in order to test hardware to be used in the 5 grain static test.
2. It is possible to obtain the pressure exponent without a pressure sensor using the following relation:


## 4. Motor Assembly for one grain test

The machining sub-team began and completed assembling the dry solid rocket motor in preparation for a one grain test.


## 5. Designed new ignitor circuit casing

The ignitor circuit i.e. the one used to ignite the nichrome wire to fire the solid rocket motor, needed a new casing design and the following was the proposed design which is ready for 3D printing as soon as the filament is purchased


## Next week's tasks

1. Pyrogenic ignitor testing
2. Cooking of grains for one grain static test
3. Old grains disposal
4. Liner thickness testing (Burn test)
5. Purchasing of items i.e. Stainless steel casing, crafting paper
6. Motor assembly for one grain test
7. 3D print ignition circuit casing

## Challenges experienced

1. Delayed procurement of items led to stalling of some tasks.
Supervisors’ note:
Visit Solid Propulsion github projects @ https://github.com/orgs/nakujaproject/projects/26 to review the tasks done.

## Thank you for your Attention!


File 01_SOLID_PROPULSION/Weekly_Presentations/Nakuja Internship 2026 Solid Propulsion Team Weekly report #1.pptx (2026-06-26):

## Nakuja Internship 2026 Solid Propulsion Team Weekly report #1

Presented by: Collins Kinyua

June 19, 2026

## Tasks completed this week:

1. Began procurement process for new SRM casing and simulated possible solid rocket motor performance.
2. Design of new casing for ignition circuit system.
3. Wrote a report on mitigation of pressure spikes in BATES(BAllistic Test and Evaluation System) grain.
4. Failure analysis of previous static tests.

## Procurement process for new casing and simulated SRM performance

Problem statement: Upon use of the Aluminum A6063-T5 casing during static fire testing led to rapid unscheduled disassembly (The motor exploded during static fire testing).
This indicated that the Aluminum casing could not withstand the simulated peak pressure value which necessitated a change of casing material.


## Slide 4

The following materials were considered:
1. Mild steel SCH 160 -available in our inventory
2. Stainless steel G 316 -Kens Metal industries
3. Carbon steel seamless pipe schedule 40 Grade B API 5L -Kens metal industries.

## Selected Material

Stainless steel G316 is the material to be used for the casing.
It is selected for having a 2mm thickness and higher yield strength than aluminium.
See the full comparison table to aluminium here (https://docs.google.com/spreadsheets/d/12ZEqdzojJpOwdd-moT2f31HzPiEnxrXmXsnNbVNElK4/edit?usp=sharing)

Parameter | Aluminium 6063-T5 | Stainless Steel G316
Outer Diameter | 100 mm | 101.6 mm
Inner Diameter | 94 mm | 97.6 mm
Thickness (t) | 3 mm | 2 mm

## 2. Design of new casing for ignition circuit.

Problem statement: During static fire testing, the current ignition circuit system (Trigger and Ignitor circuit) was bulky to transport and set-up prompting a change to a more compact and heat resistant design.
Old Design:


## New proposed design:

Trigger casing Trigger top cover


## 3. Report on mitigation of pressure spikes in BATES grain.

Key findings:
Two main areas of focus were brought to attention:
A. Structural Integrity of the grain
B. Ignition timing

## Structural Integrity

Problem faced:
1. Formation of air bubbles and voids -this causes rapid increase in chamber pressure contributing to CATO.
2. Erosive burning -this was observed by ejection of unburnt chunks of propellant during static test.
Proposed solutions:
1. Addition of surfactant -Sodium Laureth Sulphate(~1%), reduces the surface tension of sorbitol thus allowing wetting of KNO3 crystal without forming air bubbles and voids.
2. Addition of plasticizer -Glycerol(~1%) introduces flexibility to the binder thus allowing the grain to resist cracking during firing to prevent erosive burning

## B. Ignition timing

Problem statement:
During previous static fire testing, delayed ignition was observed which contributes to non-uniform pressure rises.


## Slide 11

Proposed solution:
1. Implementation of a dual ignition sequence consisting of high-sensitivity primer (KNO3, Charcoal, Isopropyl Alcohol -Binding agent) and internal pyrogenic ignitor charge to ensure the entire grain surface initiates combustion simultaneously, preventing localised pressure surges caused by slow or uneven ignition.
2. Increase inter-grain spacing to 15% of grain diameter to allow for easy penetration of hot gases thus instantaneous ignition.


## Effect of adding primer and increasing spacing between the grains inside the SRM

Delayed ignition without primer: Proper ignition with primer:
(Notice the time taken to reach 500N in both curves, it should be instantaneous)


## 4. Failure analysis of previous static tests.

A scientific workflow for failure analysis was developed and will be used to record, analyse and provide possible solutions for why the previous N-4 SRM failed.
This is the workflow we came up with:


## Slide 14


## Challenges faced this week

1. Lack of internet connection hindered effective research.

## The End!


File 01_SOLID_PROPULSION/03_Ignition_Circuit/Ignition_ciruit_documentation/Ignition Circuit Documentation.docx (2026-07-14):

NAKUJA SOLID ROCKET MOTOR

IGNITION PROCESS

A Technical Explanation of the Firmware, Wireless Link, and Safety Logic Governing Ignition


Prepared by Ben Wetu

Table of Contents

1. Introduction & System Overview.................................................................................... 3

1.1 Why This Separation Matters.................................................................................. 3

2. Hardware Involved in the Ignition Path........................................................................... 3

2.1 The Critical Path..................................................................................................... 4

3. Step-by-Step: How Ignition Is Triggered.......................................................................... 5

Step 1 — Operator presses and releases the arm/fire button......................................... 5

Step 2 — Trigger Board broadcasts the ignition command.............................................. 5

Step 3 — Trigger Board gives operator feedback............................................................ 5

Step 4 — Igniter Board receives and validates the command.......................................... 5

Step 5 — Ignition pin is driven HIGH.............................................................................. 5

Step 6 — Automatic cut-off after 15 seconds................................................................. 6

4. Ignition Sequence Diagram............................................................................................ 6

5. Timing Behaviour of the Ignition Pin............................................................................... 7

5.1 Why a Fixed Timer Instead of a Manual Hold............................................................ 7

6. Safety Mechanisms and Failure Handling........................................................................ 8

6.1 Boot-Time Safety Default........................................................................................ 8

6.2 Exact-Match Command Validation........................................................................... 8

6.3 Self-Terminating Burn Window................................................................................ 8

7. Telemetry Running Alongside Ignition............................................................................ 9

7.1 Data Flow Summary................................................................................................ 9

# 1. Introduction & System Overview

This report explains, in detail, how the ignition process works on the NAKUJA solid motor static-fire test stand. The system is built from two ESP32 microcontroller boards that communicate wirelessly, plus a browser-based dashboard for the operator. Its job is to let an operator safely trigger ignition of a solid rocket motor from a distance while continuously monitoring thrust, chamber temperature, and chamber pressure.

The system is composed of three cooperating parts:

· Igniter Board — mounted at the test stand itself, next to the motor. It reads sensor data and physically switches the ignition circuit.

· Trigger Board — the operator's console, some distance away. It hosts the arm/fire button, a local display, and a Wi-Fi access point.

· Web Dashboard — a browser page that connects over Wi-Fi to visualize live telemetry and log the test.

The two boards never touch the same wires — they communicate purely over a wireless protocol called ESP-NOW, which is what allows the operator to stand at a safe distance from the motor while still commanding ignition in real time.

1.1 Why This Separation Matters

Keeping the ignition switch physically at the motor (Igniter Board) and the human trigger physically at the operator's console (Trigger Board) is a deliberate safety boundary. The only thing that crosses the gap between operator and motor is a short wireless message — there is no direct electrical path a person could accidentally complete, and the Igniter Board defaults its ignition pin to LOW on every boot regardless of what the Trigger Board is doing. Figure 1 on the title page illustrates this layout; refer back to it whenever the roles of the two boards are mentioned below.

# 2. Hardware Involved in the Ignition Path

The table below lists every component that plays a role in either sensing the motor or carrying out the ignition command.

Component | Board | Function
HX711 + load cell | Igniter | Measures thrust force, sampled at 80 Hz, 8-sample smoothing
DS18B20 | Igniter | Motor/chamber temperature, read asynchronously once per second
Analog pressure sensor | Igniter | Chamber pressure via ADC, 10-sample rolling average
Ignition MOSFET/relay (GPIO 26) | Igniter | Switches power to the e-match / igniter element
ESP32 + ESP-NOW radio | Both | Low-latency peer-to-peer wireless link between boards
Arm/fire push-button | Trigger | Operator input that initiates the ignition command
16x2 I2C LCD | Trigger | Local read-out of live telemetry and ignition status
Piezo buzzer | Trigger | Audible non-blocking melody cue on ignition
Wi-Fi AP + WebSocket server | Trigger | Bridges ESP-NOW telemetry to the browser dashboard

## 2.1 The Critical Path

Only a small subset of this hardware is actually in the ignition 'critical path' — the chain of events that must work correctly for ignition to happen safely and on command:

· The push-button on the Trigger Board (physical input).

· The ESP-NOW radio link between the two ESP32s (wireless transport).

· The receiveCallback() handler and ignition pin (GPIO 26) on the Igniter Board (the actual switch).

Everything else — the LCD, buzzer, dashboard, load cell, temperature and pressure sensors — is instrumentation. It informs the operator but is not required for ignition itself to occur.

# 3. Step-by-Step: How Ignition Is Triggered

This section walks through exactly what happens, in order, from the moment the operator presses the button to the moment the burn ends.

## Step 1 — Operator presses and releases the arm/fire button

The button is wired to GPIO 32 on the Trigger Board with INPUT_PULLUP, so it reads HIGH when not pressed and LOW while pressed. The firmware specifically watches for the release edge, not the press itself — the code tracks a buttonDown flag and only fires when the button transitions from pressed back to released. This release-triggered design avoids firing immediately on contact bounce during the press.

## Step 2 — Trigger Board broadcasts the ignition command

On a valid release, the Trigger Board calls broadcast("on"), which sends the two-character string "on" as an ESP-NOW packet to the broadcast MAC address (FF:FF:FF:FF:FF:FF). Because ESP-NOW is connectionless and does not require an established Wi-Fi association, this message reaches the Igniter Board within a few milliseconds.

if (digitalRead(STATUS_BUTTON)) {
if (!buttonDown) {
buttonDown = true;
broadcast("on");
// LCD + buzzer feedback follows
}
} else {
buttonDown = false;
}

## Step 3 — Trigger Board gives operator feedback

Immediately after sending the command, the Trigger Board updates its LCD to read "! IGNITION !" and starts a short, non-blocking buzzer melody so the operator has audible and visual confirmation that the command was sent — independent of whether the Igniter Board actually received it.

## Step 4 — Igniter Board receives and validates the command

The Igniter Board's ESP-NOW receive callback fires as soon as the packet arrives. It copies the incoming bytes into a buffer and compares it against the literal string "on". Only an exact match is accepted; anything else is silently ignored.

void receiveCallback(const esp_now_recv_info_t *recv_info,
const uint8_t *data, int dataLen) {
char buffer[ESP_NOW_MAX_DATA_LEN + 1];
int msgLen = min(ESP_NOW_MAX_DATA_LEN, dataLen);
strncpy(buffer, (const char *)data, msgLen);
buffer[msgLen] = '\0';
if (strcmp(buffer, "on") == 0) {
IGN_STATUS = true;
t_ignition_start = millis();
}
}

## Step 5 — Ignition pin is driven HIGH

Setting IGN_STATUS to true and recording t_ignition_start does not itself fire the igniter — it only arms a condition that the main loop() checks on every pass. The main loop continuously evaluates whether IGN_STATUS is true and whether less than 15,000 milliseconds have elapsed since t_ignition_start. While both are true, it drives the ignition pin HIGH, which switches on the circuit feeding the e-match / igniter element in the motor.

if (IGN_STATUS && (millis() - t_ignition_start < 15000)) {
digitalWrite(ign_pin, HIGH);
} else {
digitalWrite(ign_pin, LOW);
IGN_STATUS = false;
}

## Step 6 — Automatic cut-off after 15 seconds

There is no separate "off" command from the operator. The Igniter Board is entirely self-timed: once 15,000 milliseconds have elapsed since ignition started, the same condition above becomes false on its own, the pin is driven LOW, and IGN_STATUS resets — returning the board to its safe idle state without requiring any further wireless communication.
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

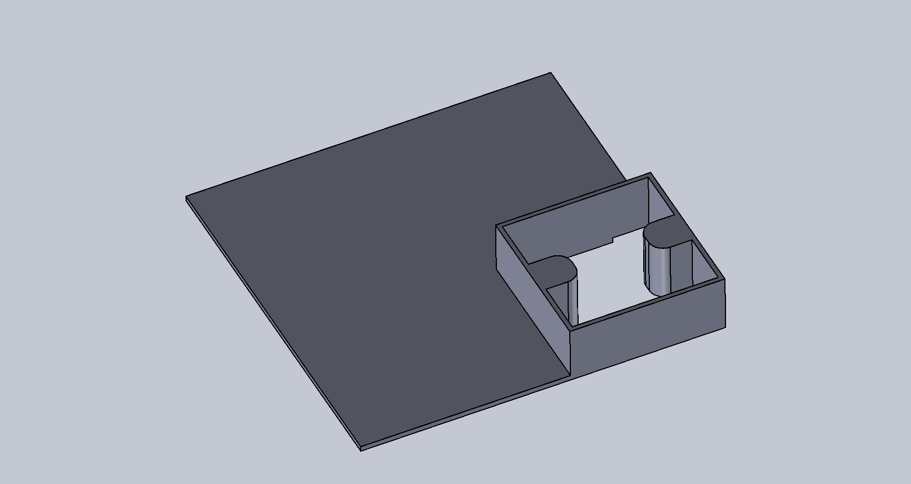
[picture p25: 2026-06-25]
01_SOLID_PROPULSION/03_Ignition_Circuit/Hardware/Photos/trigger cover TOP.PNG

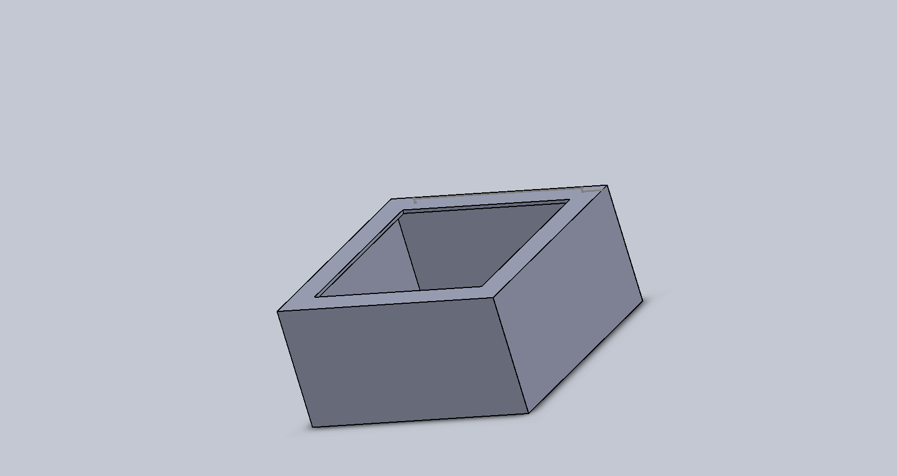
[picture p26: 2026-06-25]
01_SOLID_PROPULSION/03_Ignition_Circuit/Hardware/Photos/trigger 3d casing simplw (2).PNG

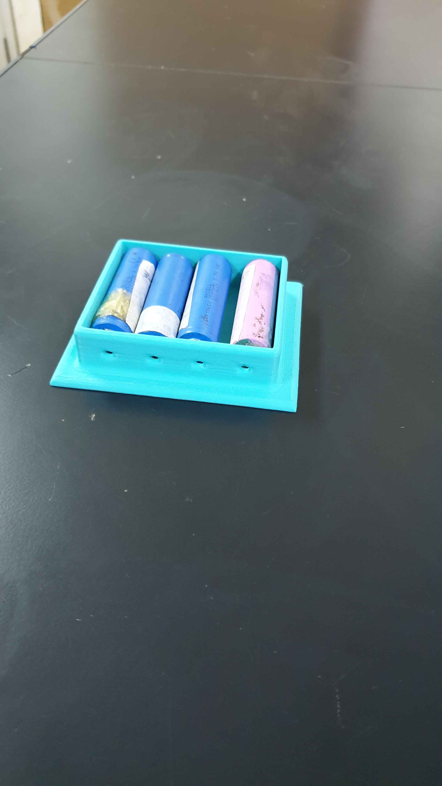
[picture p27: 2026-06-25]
01_SOLID_PROPULSION/03_Ignition_Circuit/Hardware/Photos/Battery_holder_ignition_circuit.jpeg

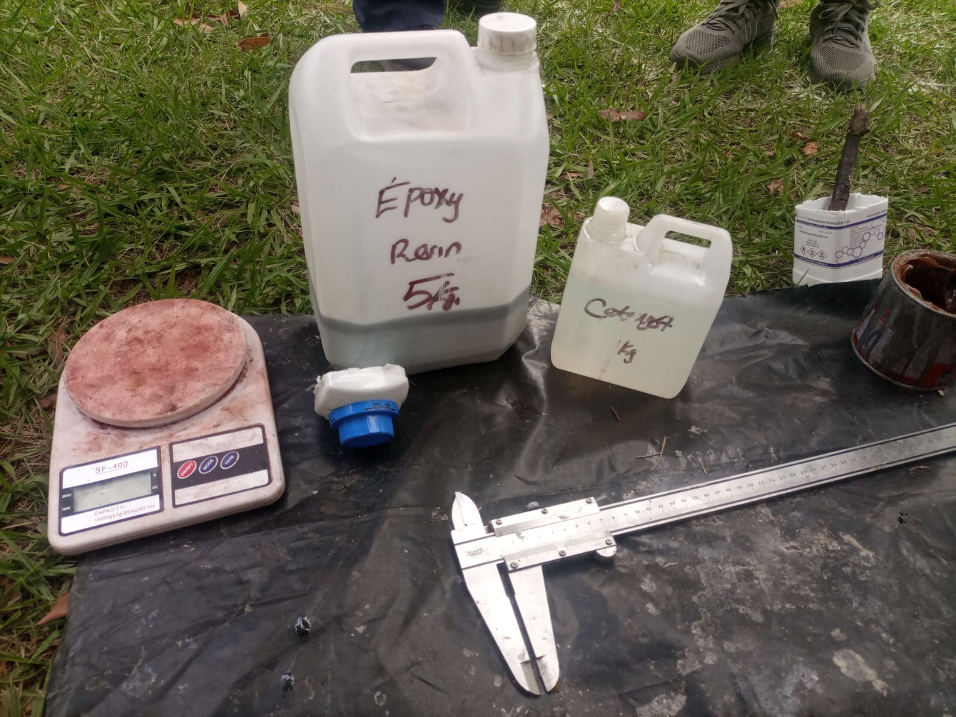
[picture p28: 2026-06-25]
01_SOLID_PROPULSION/01_Propellant/Liners/Liner_requirements.jpeg

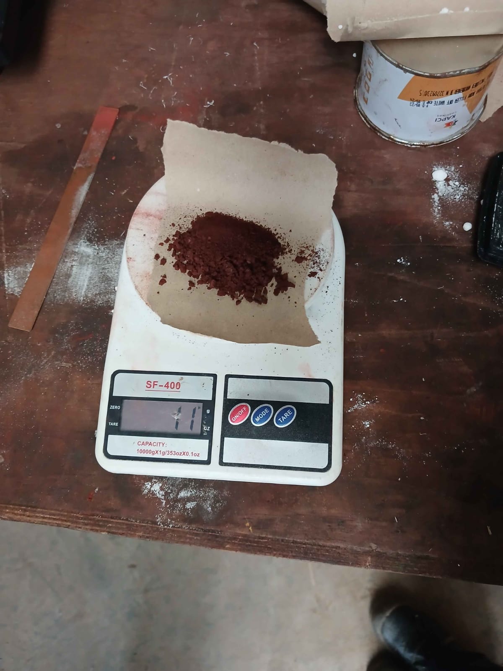
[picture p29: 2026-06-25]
01_SOLID_PROPULSION/01_Propellant/Crimson_Powder/Photos/Crimson_Powder_Image_June2026.jpeg

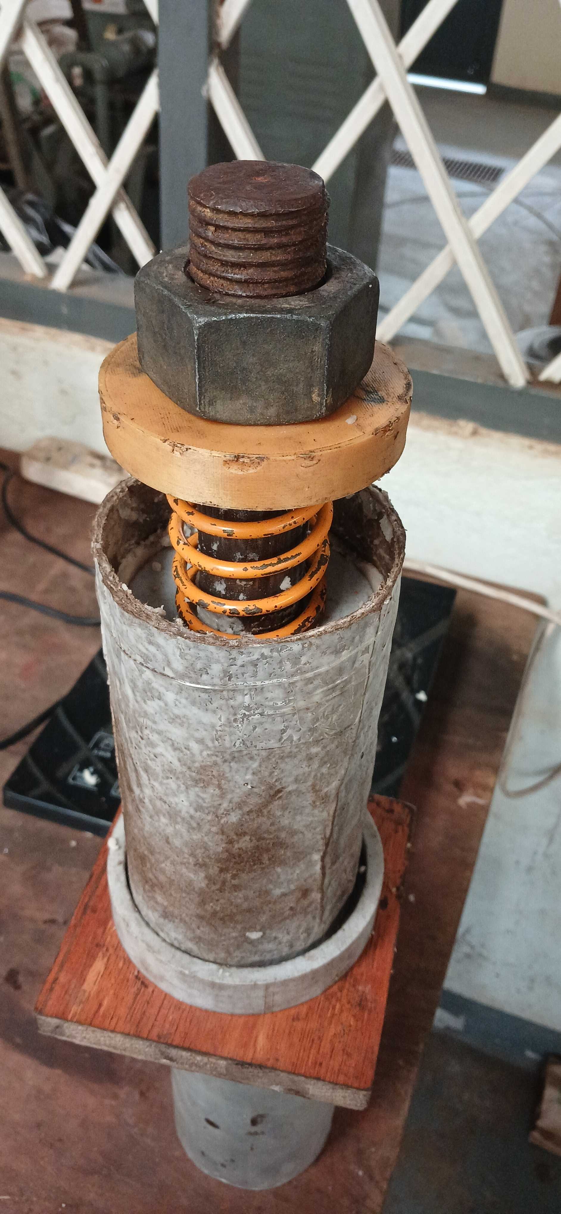
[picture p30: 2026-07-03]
01_SOLID_PROPULSION/01_Propellant/Grains/Photos/Grains_cured_under_pressure.jpg

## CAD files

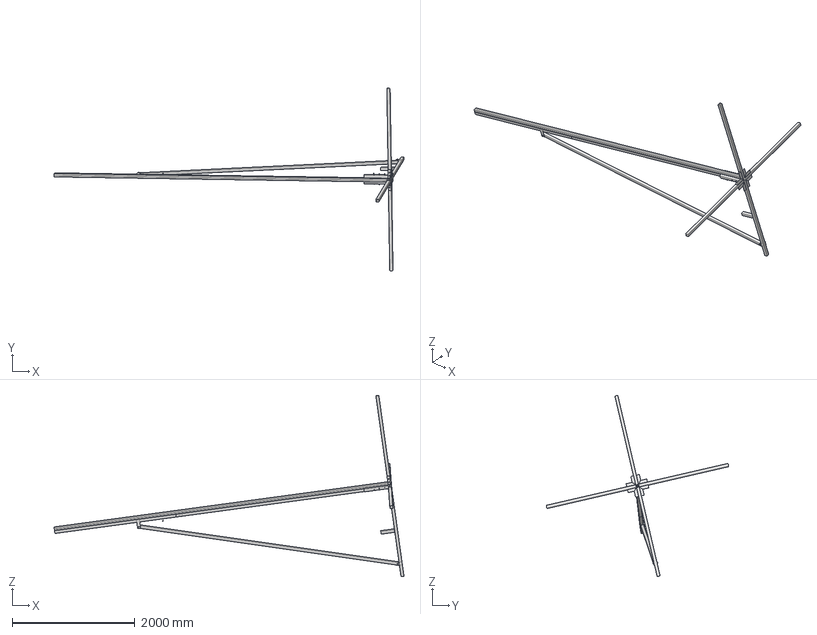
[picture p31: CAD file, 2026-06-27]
02_AIRFRAME/CAD_Files/END LAUNCHPAD ASSEMBLY.stp
5714.3 x 2980.7 x 2961.6 mm
leg x 3
Angle line1 x 4
Angle line2 x 4
SUPPORT LEG
rest arm
top support x 2
outer flat x 2
telecopic frame BOTTOM
telecopic frame top
telecopic frame COUPLER
NEW SUPPORT
ISO 4014 - M8 x 70 x 12
thread rod x 3
ISO 4032 - M8 x 10
ISO 4032 - M8_1 x 6
Launchrail

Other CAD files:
01_SOLID_PROPULSION/02_Machining/one-grain static test motor/bulk_head/bulkHead_94mm.dwg
01_SOLID_PROPULSION/02_Machining/one-grain static test motor/casing/casing_258mm.dwg
01_SOLID_PROPULSION/02_Machining/one-grain static test motor/nozzle/nozzle_94mm.dwg
01_SOLID_PROPULSION/02_Machining/one-grain static test motor/bulk_head/bulkHead_94mm.ipt
01_SOLID_PROPULSION/02_Machining/one-grain static test motor/casing/casing_258mm.ipt
01_SOLID_PROPULSION/02_Machining/one-grain static test motor/nozzle/nozzle_94mm.ipt

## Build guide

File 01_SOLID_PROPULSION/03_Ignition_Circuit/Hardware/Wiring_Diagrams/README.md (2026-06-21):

# Wiring Diagrams

## Overview

This folder contains wiring diagrams for the Nakuja Project ignition circuit hardware.

The wiring diagrams should help team members correctly connect the igniter board, trigger board, sensors, power supply, and dashboard communication setup.

## Recommended Contents

```text
Wiring_Diagrams/
├── README.md
├── Full_System_Wiring/
├── Igniter_Board_Wiring/
├── Trigger_Board_Wiring/
├── Sensor_Wiring/
└── Power_Wiring/
```

## Diagrams to Include

| Diagram | Purpose |
| --- | --- |
| Full system wiring diagram | Shows the complete ignition system connection |
| Igniter board wiring diagram | Shows test-stand-side wiring |
| Trigger board wiring diagram | Shows operator-side wiring |
| HX711 and load-cell wiring | Shows thrust measurement connection |
| DS18B20 wiring | Shows temperature sensor connection |
| Pressure transmitter/interface wiring | Shows pressure measurement connection |
| Power wiring diagram | Shows battery, regulators, and board supply paths |
| Connector pinout diagram | Shows XT, JST, and board connector wiring |

## Wiring Documentation Requirements

Each wiring diagram should clearly show:

* Component names.
* Connector names.
* Pin numbers.
* Wire colors where applicable.
* Voltage levels.
* Ground connections.
* Signal direction.
* Power polarity.
* Sensor polarity.
* ESP32 pin connections.
* Revision date.

## Recommended Naming Format

```text
full_system_wiring_revA.png
igniter_board_wiring_revA.png
trigger_board_wiring_revA.png
hx711_load_cell_wiring_revA.png
pressure_interface_wiring_revA.png
power_distribution_wiring_revA.png
```

## Important Notes

* The wiring diagram must match the schematic.
* The wiring diagram must match `Pin_Mapping.md`.
* Any changed wire, connector, or ESP32 pin must be updated here.
* Sensor wiring should be labelled clearly to avoid reverse connection.
* Power and ground wiring should be shown clearly to reduce brownout and grounding issues.

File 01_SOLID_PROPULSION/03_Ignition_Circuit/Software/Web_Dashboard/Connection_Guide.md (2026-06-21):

# Dashboard Connection Guide

## Overview

This document explains how to connect the Nakuja ignition web dashboard to the ESP32 trigger board.

The dashboard receives telemetry through a WebSocket connection from the trigger board. The trigger board receives telemetry from the igniter board and forwards it to the browser dashboard.

## Connection Steps

1. Power the trigger board.
2. Confirm that the trigger board has created its Wi-Fi access point.
3. Connect the laptop or tablet to the trigger board Wi-Fi network.
4. Open the dashboard file in a browser:

```text
index.html
```

5. Enter the ESP32 IP address in the dashboard input field.
6. Click **Connect**.
7. Confirm that the dashboard status changes to **Connected**.
8. Confirm that temperature, pressure, and thrust values update.

## Default WebSocket Settings

| Item | Value |
| --- | --- |
| Default ESP32 IP address | `192.168.4.1` |
| WebSocket port | `81` |
| WebSocket address | `ws://192.168.4.1:81` |
| Dashboard file | `index.html` |
| Logo file | `nakuja_icon.png` |

## Expected Connection Flow

```text
Igniter Board
     ↓
ESP-NOW
     ↓
Trigger Board
     ↓
Wi-Fi Access Point
     ↓
WebSocket
     ↓
Browser Dashboard
```

## Successful Connection Indicators

A successful connection should show:

* Dashboard status changes from **Disconnected** to **Connected**.
* System status changes to **Operational**.
* Temperature value updates.
* Pressure value updates.
* Thrust value updates.
* Event log records the connection event.

## Troubleshooting

| Problem | Possible Cause | Recommended Check |
| --- | --- | --- |
| Dashboard does not connect  | Wrong IP address | Confirm the ESP32 IP address |
| Status remains disconnected | WebSocket server is not running | Check trigger board firmware |
| Values remain zero | No telemetry packets received | Check ESP-NOW communication |
| Charts do not update | Invalid telemetry format | Check JSON field names |
| CSV has no data | Recording was not started | Click **Start Recording** before test |
| Logo does not show | Missing image file | Confirm `nakuja_icon.png` is in the same folder as `index.html` |
| Browser shows errors | Missing internet/CDN access | Check Chart.js loading or use offline libraries later |

## Notes

* The laptop must be connected to the ESP32 trigger board access point before the dashboard can connect.
* The WebSocket server is expected to run on port `81`.
* The dashboard is a monitoring and recording interface only.
* It does not replace firmware safety logic, physical safety procedures, or approved test checklists.

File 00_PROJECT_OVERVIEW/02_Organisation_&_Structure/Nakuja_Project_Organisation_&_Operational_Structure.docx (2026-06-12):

Nakuja Project

Organization Structure & Operations Manual

Date: 15 June, 2026.

Prepared by: Collins Kinyua, Team Coordinator.

### 1. Introduction

Nakuja Project is a university-based organization dedicated to designing, building, and launching sub-orbital rockets. Our flagship project is N4 — a solid-propelled rocket targeting 3.5 km altitude with a Can Sat payload.

It also aims to provide hands-on aerospace engineering experience, foster interdisciplinary collaboration, and promote scientific excellence among students. We operate primarily during the internship period (June–August) and academic term with flexible participation.

Current Goal (2026): Achieve a successful 5-grain static test and N4 launch by end of July 2026.

### 2. Mission, Vision & Values

- Mission: Build a liquid propelled rocket to reach the Karman Line(100km).
- Vision: Become Africa’s leading launch provider.
- Core Values: Safety first, scientific rigor, documentation, collaboration, and continuous improvement (“standing on the shoulders of giants”).

### 3. Organizational Structure

Nakuja operates with a flat but clear hierarchy:

Supervisors

- Dr. Shohei Aoki
- Dr. Patrick Irungu
- Dr. Anthony Muchiri

Leadership(Students)

- Team Coordinator
- Team Leaders (Solid, Airframe and Recovery)
- Digital Media

Core Teams

- Solid Propulsion Team
- Airframe Team
- Recovery Team
- KEFIRE (Liquid Propulsion Team) - Research & Prototyping

### 4. Work Policies & Procedures

Working Hours

- Monday to Friday: 9:00 AM – 5:00 PM
- Lunch Break: 1:00 PM – 2:00 PM
- Members may come within these hours and contribute as their schedule allows.

Workstations & Access

- Main Areas:
  - Main Brainstorming Room (IPIC 1st Floor)
  - Rapid Prototyping Lab 1 (IPIC 1st Floor)
  - Exhibition Hall (IPIC Ground Floor)
  - Advanced Research Lab (IPIC Liquid Team)
- Additional Areas: Garden Space (Solid & Airframe), Baseball Pitch (Solid & Recovery).
- Restricted Access: Chemistry labs, Engineering workshops and other areas require an official signed letter from one of the supervisors.

Safety & Conduct

- Safety boots and overalls are mandatory in workshops and Exhibition Hall.
- Clean workstations by 4:45 PM daily.
- Strict adherence to safety protocols during propellant handling and static tests.

### 5. Communication & Documentation

Primary Channels

- GitHub — Official documentation, weekly memos, experiment reports, progress tracking.
- Discord — Day-to-day communication, quick questions, announcements.

Daily Requirement

Every member must post at least one photo + short summary of activities done in their team’s Discord channel or GitHub repository (Internship-2026).

Weekly Reporting

- Detailed weekly memos submitted every Friday.
- Friday Meeting: 2:00 PM – 4:00 PM (all teams present progress).
- Fortnight Leaders Meeting (Team Coordinator + Team Leads).

### 6. Resource Management & Purchasing

Consumables Borrowing

- All tools and consumables are managed by Mr. Lenny.
- Sign-out / sign-in register required for every item borrowed and returned the same day.

Purchasing Process

- Each team has a designated purchasing member.
- Purchases are consolidated periodically for efficiency.
- Procedure:
  1. Submit the documents for procurement (list of items, justification document)
  2. After the supervisor’s approval, go to the store
  3. Get receipt with “Dr. Peter Oketch” written on it.
  4. Take a photo of receipt + date + till/paybill. Share the photo on the WhatsApp procurement group.
  5. The supervisor will make the payment via Mpesa
- Travel claims: Seek approval by explaining the necessity of the travel. Once approved, carry the travel form upon departure from Mr. Billy for reimbursement.

### 7. Progress Tracking & Scientific Approach

- All work follows the Scientific Method: Problem → Hypothesis → Experiment → Analysis → Iteration.
- Progress tracked via GitHub Projects.
- Every experiment requires a one-page hypothesis sheet

### 8. Team Roles & Responsibilities

Cross-Learning & Responsibility

While tasks are assigned to specific subgroups for efficiency, every member is expected to develop a broad understanding of the assigned team e.g. Solid Propulsion.

Documentation & Housekeeping

Documentation is a shared responsibility. Every member must document their work, observations, and lessons learned. Maintaining a clean workspace and proper tool return is also everyone’s duty.

Safety Note

Access to the Workshops is restricted. Members must complete the internal attachment/training before working there. This rule will be strictly enforced for safety.

Teams

1. Solid Propulsion -this team is tasked with developing the solid propellant (KNSB), machining the Solid Rocket Motor components (Bulkhead & Nozzle) and reaching a target peak thrust of 2500N which will contribute towards the rocket reaching its 3.5 Km target. The team will work on the following aspects: Propellant, Machining, Ignition Circuit, 3D Printing, and Documentation.

2. Airframe -this team is tasked with designing and fabricating the body tube and launch pad for the N-4 rocket.

3. Recovery -this team is tasked with designing and fabricating the flight computer, telemetry and parachute deployment system.

4. Liquid Propulsion -this team is currently dealing with researching and prototyping a liquid propelled engine for future flight missions.

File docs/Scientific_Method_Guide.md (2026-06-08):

This file explains the scientific method.

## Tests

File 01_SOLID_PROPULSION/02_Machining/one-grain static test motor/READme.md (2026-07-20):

# One-Grain Static Test Motor

This repository/folder contains the design files for a **one-grain static test motor**. It includes manufacturing drawings and the native CAD project for editing.

## Working Drawings (PDFs)

The following manufacturing-ready drawings are provided:

- **`bulkHead_94mm.pdf`** – Bulkhead drawing (94 mm Casing Inner Diameter)
- **`casing_258mm.pdf`** – Casing drawing (258 mm Long)
- **`nozzle_94mm.pdf`** – Nozzle drawing (94 mm Casing Inner Diameter)

These PDFs serve as the primary reference for fabrication.

## Editing the Design Files

To modify the parametric 3D models:

1. **Install Autodesk Inventor** (any recent version compatible with the project files).
2. **Download the entire folder** `"one-grain static test motor"`.
3. **Open the project file**:  
   **`One-Grain Static Test Al-Motor 2026.ipj`**

Opening the `.ipj` project file will automatically link and load all associated part (`.ipt`) and assembly (`.iam`) files for editing.

### Recommended Workflow
- Use the project file to maintain proper file references and search paths.
- Make changes to individual parts/assemblies as needed.
- Update drawings (.idw) if dimensions or views require revision.
- Export updated PDFs or STEP files for manufacturing.

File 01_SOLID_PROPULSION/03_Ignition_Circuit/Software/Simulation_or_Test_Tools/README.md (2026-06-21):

# Simulation or Test Tools

## Overview

This folder contains scripts, sample packets, and test utilities used to validate the ignition telemetry software without requiring the full hardware setup.

The tools in this folder are mainly for dashboard testing, WebSocket testing, telemetry-format verification, and software debugging.

## Purpose

This folder may be used for:

* WebSocket telemetry simulators.
* Dashboard test scripts.
* Sample telemetry packet generators.
* CSV replay tools.
* Serial monitor logs.
* Offline dashboard testing.
* Communication debugging.
* Sensor data simulation.

## Recommended Folder Structure

```text
Simulation_or_Test_Tools/
├── README.md
├── WebSocket_Simulator/
├── CSV_Replay/
├── Sample_Telemetry_Packets/
└── Test_Logs/
```

## Example Use Cases

| Tool | Purpose |
| --- | --- |
| WebSocket simulator | Sends fake telemetry to the dashboard for testing |
| CSV replay script | Replays saved test data into the dashboard |
| Sample telemetry packets | Shows the expected JSON format from the ESP32 |
| Test logs | Stores software test observations and debugging notes |

## Expected Telemetry Variables

| Variable | Unit | Description |
| --- | ---: | --- |
| Temperature | °C | Simulated or received DS18B20 value |
| Pressure | kPa / bar | Simulated or received pressure value |
| Thrust | N | Simulated or received load-cell value |
| Armed State | Status | Simulated system arming condition |
| Ignition State | Status | Simulated ignition-output state |
| Time | s / ms | Timestamp used for plotting and recording |

## Notes

Simulation tools are for software validation only. They do not replace full hardware testing, safety procedures, sensor calibration, or approved static-test operations.

Any simulated data must be clearly labelled so that it is not confused with real static-test data.

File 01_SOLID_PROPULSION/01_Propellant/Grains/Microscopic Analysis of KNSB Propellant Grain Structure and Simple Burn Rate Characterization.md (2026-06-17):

**Nakuja Project** 
**Scientific Experiment Protocol**  

**Date:** 16 June 2026 
**Prepared by:** Solid Propulsion Team  

---

### Abstract
This experiment aims to investigate the microscopic structure of KNSB (Potassium Nitrate – Sorbitol) propellant grains to identify defects such as voids, air bubbles, and microcracks that contribute to rapid pressure spikes and CATO failures. A standard reference grain will be produced using optimized casting and curing methods. The grain will be sectioned and examined under a microscope. A simple strand burn rate test will also be performed to correlate microstructure with combustion behavior. Results will inform improved grain fabrication protocols for the 5-grain motor.

---

### 1. Introduction
KNSB is our chosen composite propellant (65% KNO₃ oxidizer + 35% sorbitol fuel). Past static tests have shown CATO failures linked to suspected internal defects causing sudden increases in burning surface area and chamber pressure. Understanding grain microstructure is critical for mitigating these issues before full motor production.

---

### 2. Objectives
1. Produce a high-quality reference KNSB grain using standardized procedures.
2. Examine the internal microstructure (voids, cracks, crystal distribution) under a microscope.
3. Perform a simple burn rate test to correlate microstructure with combustion performance.
4. Establish baseline data for comparison with improved curing methods (pressure, vacuum, slow cooling, additives).

---

### 3. Hypothesis
- **Primary Hypothesis**: Grains produced with pressure curing and vacuum degassing will exhibit significantly fewer voids and microcracks compared to standard room-temperature cured grains.
- **Secondary Hypothesis**: Reduced defects will result in more consistent burn rates and lower risk of pressure spikes during combustion.

---

### 4. Materials
- Potassium Nitrate (finely milled KNO₃)
- Sorbitol
- Liner
- Microscope 
- Cutting tools (saw or blade for sectioning)
- Burn rate test setup (simple strand holder, stopwatch, ruler)
- Safety equipment (PPE, fume hood)

---

### 5. Methods & Procedure

#### Phase 1: Reference Grain Preparation (Standard Method)
1. Melt sorbitol at ~120°C.
2. Gradually add finely milled KNO₃ while stirring to achieve uniform 65/35 mixture.
3. Pour into liner cast.
4. Cure under pressure (threaded rod + plate) for 1 week.
5. Record: mass, dimensions, density.

#### Phase 2: Microscopic Analysis
1. Carefully section the cured grain into thin slices (longitudinal and cross-sectional).
2. Prepare samples on glass slides.
3. Observe under microscope at 40x–400x magnification.
4. Document:
   - Void size and distribution
   - Microcracks
   - Crystal uniformity
   - Density variations
5. Take high-resolution photos with scale.

#### Phase 3: Simple Burn Rate Test
1. Cut a small strand (~5–10 mm long, uniform cross-section) from the reference grain.
2. Mount vertically in a holder.
3. Ignite one end and record burn time with stopwatch.
4. Measure burned length.
5. Calculate linear burn rate (\( r = \frac{\text{length burned}}{\text{time}} \)).
6. Repeat 3–5 times for average.

---

### 6. Data Collection & Analysis
- **Microscopic Data**: Number of voids per field, average void size, crack density.
- **Burn Rate Data**: Average \( r \) (mm/s), consistency across samples.
- **Comparison**: Compare with previous grains and simulations.
- **Tools**: Google Sheets for data logging, microscope software for measurements.

---

### 7. Safety Protocols
- Conduct all propellant handling in fume hood with PPE.
- Small sample sizes only for burn rate test.
- Fire extinguisher and sand bucket nearby.
- No testing near main motor components.

---

### 8. Timeline (Next Week)
- **Day 1–2**: Grain casting and initial curing setup.
- **Day 3–7**: Curing period (monitor conditions).
- **Day 8**: Sectioning and microscopic examination.
- **Day 9**: Burn rate tests and data analysis.
- **Day 10**: Report writing and recommendations.

---

### 9. Expected Outcomes & Success Criteria
- Clear microscope images showing internal structure.
- Quantitative data on defects.
- Burn rate value consistent with literature (~5–10 mm/s at target pressure).
- Actionable recommendations for grain improvement (e.g., best curing method).

---

This protocol follows the scientific method and will be documented thoroughly. Results will be archived in the GitHub repository under `Nakujaproject/Internship-2026/01_SOLID_PROPULSION/Grains/Microstructure_Analysis`.

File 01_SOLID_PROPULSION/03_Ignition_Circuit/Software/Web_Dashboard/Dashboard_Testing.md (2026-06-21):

# Dashboard Testing Notes

## Overview

This document records how the Nakuja ignition web dashboard should be tested before use during dry runs or static motor tests.

The dashboard should be tested before every important test session to confirm that the interface loads correctly, the WebSocket connection works, telemetry values update, and CSV export functions properly.

## Basic Test Checklist

- [ ] `index.html` opens correctly in the browser.
- [ ] `nakuja_icon.png` loads correctly.
- [ ] Temperature card is visible.
- [ ] Pressure card is visible.
- [ ] Thrust card is visible.
- [ ] Temperature chart loads correctly.
- [ ] Pressure chart loads correctly.
- [ ] Thrust chart loads correctly.
- [ ] Event log is visible.
- [ ] Start Recording button works.
- [ ] Stop Recording button works.
- [ ] Download CSV button works.
- [ ] WebSocket connection works when connected to the trigger board.
- [ ] CSV file contains timestamped values.

## Browser Compatibility

| Browser | Status | Notes |
|---|---|---|
| Google Chrome | To be tested | Recommended browser |
| Microsoft Edge | To be tested | Alternative browser |
| Mozilla Firefox | To be tested | Optional browser |

## Functional Test Cases

| Test | Expected Result |
|---|---|
| Open dashboard offline | Page loads and shows disconnected/offline status |
| Enter correct ESP32 IP address | Dashboard attempts WebSocket connection |
| Connect to trigger board | Status changes to connected |
| Receive valid telemetry packet | Cards and charts update |
| Receive event message | Event log updates |
| Start recording | Stopwatch resets and data recording begins |
| Stop recording | Data recording stops |
| Download CSV | CSV file downloads successfully |
| Refresh page | Dashboard reloads without layout errors |

## Telemetry Test Values

Use sample values such as:

| Variable | Example Value | Unit |
|---|---:|---|
| Temperature | 27.5 | °C |
| Pressure | 101.3 | kPa |
| Thrust | 12.8 | N |
| Ignition armed | false | status |

## Known Issues

| Issue | Status | Notes |
|---|---|---|
| Demo data disabled | Intentional | Real telemetry should be used during actual tests |
| Dashboard depends on CDN libraries | To review | Internet may be required unless libraries are stored locally |
| Pressure calibration | Pending | Final pressure conversion must be verified |
| Brownout effects | Under validation | Power stability should be checked during hardware tests |

## Pre-Test Recommendation

Before a dry run or static test:

1. Open the dashboard.
2. Connect to the trigger board Wi-Fi access point.
3. Enter the ESP32 IP address.
4. Confirm telemetry updates.
5. Start recording.
6. Verify that CSV download works using a short test.
7. Clear old test data before the real test.
8. Record the firmware version and dashboard version used.

## Notes

Dashboard testing validates the user interface and telemetry path only. It does not replace sensor calibration, hardware inspection, ignition safety checks, or approved static-test procedures.

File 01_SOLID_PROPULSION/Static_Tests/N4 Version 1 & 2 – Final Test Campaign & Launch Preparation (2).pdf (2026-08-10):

## N4 Version 1 & 2 – Final Test Campaign & Launch Preparation

Nakuja Rocketry Club
Solid Propulsion Team
Updated Critical Path Documentation
N4 Version 2 – Final Test Campaign & Launch Preparation

Document Version: 3.0
Date: 6 August 2026

## 1. Campaign Objectives

Priority | Motor Configuration | Casing | Static Test Target Date | Purpose
1 | 3-grain | Aluminium 6063-T5 | Monday 17 August | Intermediate verification
2 | 4-grain | Stainless Steel G304 SCH 10 | Friday 21 August | High Margin Option
3 | 5-grain | Aluminium 6063-T5 | Monday 24 August | Primary flight candidate

Post-success: Mass-produce two flight motors of each successful configuration for dual launch (minimum two rockets).

Hard deadline: All static tests completed and flight motors ready for launch by 11 September 2026.

## 2. Critical Path Overview (from 10 August)

Main Sequence:

1. Materials available (10 Aug)

## 3. Detailed Timeline

Phase 0 – Materials & Preparation (10–11 August)

Phase 1 – 3-Grain Aluminium Motor (Target Static Test: 17 August)

Task | Owner | Start | Duration | Notes
Machine core rods + motor preparation (drilling, tapping) | Machining Team | 10 Aug | 3–4 days | Parallel where possible
Cook 3 grains | Propellant Team | 10–12 Aug | 1 day each | Max 1 grain/day initially
Cure grains | — | — | 7 days | Critical path item
Fabricate liners | Propellant Team | 10–12 Aug | 1 day each
Dry assembly | Machining + Propellant | 14–15 Aug | 1–2 days
Wet assembly + ignitor | Full team | 16 Aug | 1 day
2. Parallel start: Core rods + Machining (nozzles + bulkheads) + Casting tool printing + Grain cooking
3. 3-grain assembly & static test → 17 Aug
4. Immediate transition to Stainless Steel 4-grain cooking/assembly → static test 21 Aug
5. Aluminium 5-grain path (parallel where possible) → static test from 24 Aug week
6. Mass production of successful configurations

Receive and inventory all purchased items
3D-print additional casting tools (target: 3–4 tools total) Machine first set of core rods
Begin liner fabrication (if epoxy is available)

Task | Owner | Start | Duration | Notes
Static Fire – 3 Grain | Full team | 17 Aug | 1 day | Data review same day

Phase 2 – 4-Grain Stainless Steel Motor (Target Static Test: 21 August)

Task | Owner | Start | Duration | Notes
Machine nozzle + bulkhead | Machining Team | 18–22 Aug | 3–4 days | Parallel with 3-grain work
Cook 4 grains | Propellant Team | 18–21 Aug | 4 days
Cure + Assembly | Full team | 22–25 Aug | —
Static Fire – SS 4 Grain | Full team | 25–28 Aug | 1 day | Flexible within week

Phase 3 – 5-Grain Aluminium Motor (Week of 24 August)

Task | Owner | Start | Duration | Notes
Cook 5 grains | Propellant Team | 13–17 Aug | 5 days | Overlap with 4-grain cure
Cure grains | — | — | 7 days | Must finish by 20 Aug
Assembly (dry + wet) | Full team | 19–20 Aug | 2 days
Static Fire – 5 Grain | Full team | 21 Aug | 1 day | Critical decision point

Phase 4 – Mass Production (from 24 August / after successful tests)

Replicate successful Aluminium 5-grain configuration (priority)
Replicate successful Stainless Steel 4-grain configuration
Target: 2 flight-ready motors of each successful type

## 4. Resource & Constraint Notes

## 5. Decision Gates

Date | Gate | Possible Outcomes
17 Aug | 3-grain Aluminium result | Proceed / Hold / Adjust
21 Aug | Stainless Steel 4-grain result | High Margin of error backup
25–28 Aug | 5-grain Aluminium result | Use results from 3 grain to produce 5 grain

## 6. Team Responsibilities

Re-use proven casings, nozzles, and bulkheads where possible to compress timeline

Grain production rate: Initially limited to 1 grain/day (1 core rod + 1 casting tool). Additional tools must be printed immediately on 10 August to increase throughput.
Curing remains the longest single constraint (7 days). Overlapping cooking of the next motor’s grains while the previous set cures is mandatory.
Machining: Nozzles (3 days), bulkheads (2 days) and core rods (1 day) must be scheduled aggressively in parallel across the two aluminium motors and the stainless-steel motor.
Ignitors: Can be prepared in a single day and done in parallel with grain work.

Propellant Team (2): Grains, liners, ignitors, chemistry
Machining Team (2): Nozzles, bulkheads, core rods, assembly support Ignition Team: Circuit fabrication, motor ignition, data acquisition
3D Printing (1): Casting tools, any urgent housings
Documentation (1): Daily logs, test reports, GitHub updates

## 7. Success Criteria for Launch Readiness

At least one configuration (Al 5-grain or SS 4-grain) successfully static-tested Two flight motors of the chosen configuration fully assembled and inspected All data packages and safety documentation complete

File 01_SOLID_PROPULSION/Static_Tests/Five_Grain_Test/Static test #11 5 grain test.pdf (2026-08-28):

Nakuja Project — Solid Propulsion Team | N4 Five-Grain Static Test Report

## Nakuja Project Solid Propulsion Team

N4 Five-Grain Static Test — Technical Report

CATO Incident Report

Prepared by: Paschal Peters (Data Recorder / Timer)

Document Version: 1.0 (Post-Execution Report) Date of Execution: Wednesday, 27 August 2026

### 1 Purpose

This report documents the static test of the N4 five-grain motor configuration conducted on Wednesday, 27 August 2026. The test extends the team’s three-grain N4 test series to a five-grain configuration, combining five individually prepared BATES grains within a single aluminium casing. The test was not completed successfully: the motor produced a good, rising thrust profile for approximately 1.55 seconds before a Catastrophic At Take-Off (CATO) event — case burst — terminated the burn. This report presents the grain configuration, simulated performance prediction, experimental results up to the point of failure, an analysis of the failure event, and recommendations for corrective action.

### 2 Theoretical Section — Grain Configuration

### 2.1 Grain and Casing Details

Parameter | Value
Motor Configuration | N4, 5-Grain, Aluminium Casing, BATES Geometry
Casing Material | Aluminium 6063-T5
Casing Inner Diameter | 94 mm
Casing Wall Thickness | 3 mm
Liner Material | Kraft paper, epoxy-catalyst cured (50:3 ratio)
Liner Thickness | 2 mm
Propellant | KNO3:Sorbitol 65:35, 0.1% NaHCO3 suppressant
Nozzle Throat | 23.1 mm

### 2.2 Propellant Configuration

All five grains were prepared as BATES geometry units with identical core diameters and lengths consistent with the team’s N4 grain standard, for a total propellant length of 725 mm. The propellant formulation used 65:35 KNO3:Sorbitol with 0.1% sodium bicarbonate (NaHCO3) as a combustion suppressant, consistent with the suppressant concentration evaluated and confirmed as viable in the team’s one-grain suppressant trial of 21 July 2026.

### 3 Simulation

The N4 five-grain configuration was modelled in OpenMotor prior to testing. The simulation predicts the following performance:

Parameter | Simulated Value
Motor Designation | M2436 (58%)
Peak Thrust | ≈2450 N
Peak Chamber Pressure | 4.34 MPa
Average Chamber Pressure | 3.91 MPa
Peak Kn | 341.41
Total Impulse | 8114.46 Ns
Burn Time | 3.30 s
Delivered ISP | 134.91 s
Propellant Mass | 6133.10 g

The simulated thrust profile follows the characteristic fast-rise, broad-plateau shape typical of a BATES multi-grain configuration with this Kn range.

### 4 Results

### 4.1 Experimental Performance (to point of failure)

The motor ignited successfully and produced a steadily rising thrust profile consistent in shape with a normal BATES burn build-up phase. The burn progressed normally for approximately 1.55 seconds, during which thrust climbed from zero to a peak of approximately 2780 N — exceeding the simulated peak of ≈2450 N at the moment of failure. At approximately t = 1.55 s, a CATO event occurred: the aluminium casing burst, terminating the burn catastrophically. No injuries were sustained.

Parameter | Value | Note
Time to CATO | ≈1.55 s | from ignition
Peak thrust before CATO | ≈2780 N | exceeded simulation
Failure mode | Case burst | mechanical
Post-CATO residual | Small (∼200 N) at t ≈ 1.75–2.0 s | scattered burn
Outcome | CATO | total motor loss

### 4.2 Thrust Curve

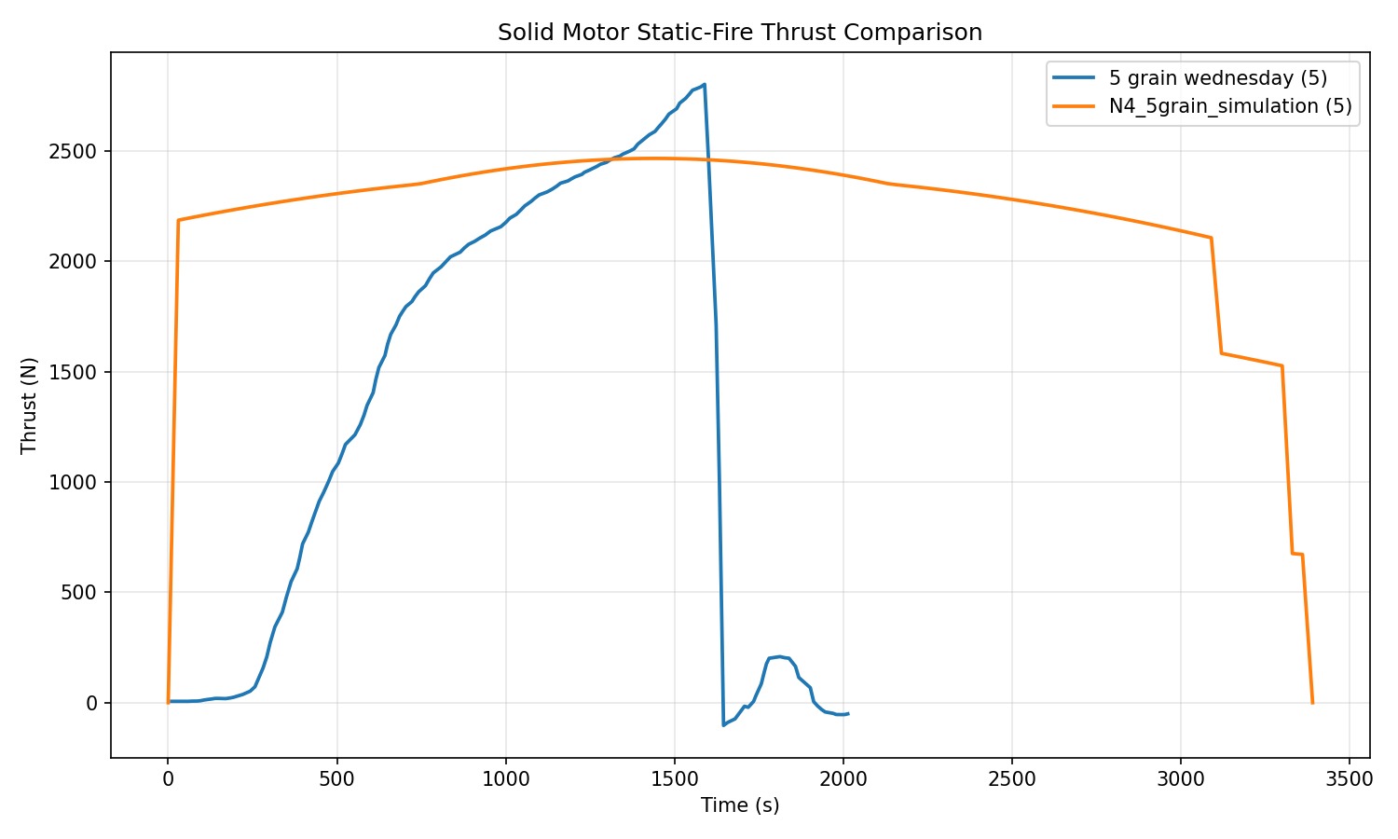
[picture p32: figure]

Figure 1: N4 five-grain static test: experimental thrust curve (blue) vs. OpenMotor simulated prediction (orange). The experimental curve shows a steady rising phase reaching ≈2780 N before the sharp vertical drop at t ≈ 1.55 s marks the CATO event. The brief residual signal near t ≈ 1.75– 2.0 s is consistent with scattered propellant burning outside the burst casing. Note: the x-axis in the plot is labelled “Time (s)” but internal comparison against the OpenMotor simulation burn time (3.30 s, ending at ≈3400 on the axis) confirms the axis unit is milliseconds (ms); the CATO occurred at ≈1550 ms = 1.55 s.

### 4.3 Theoretical vs. Experimental Comparison

Parameter | Simulated | Experimental | Note
Peak Thrust (N) | ≈2450 | ≈2780 | +13.5% at CATO
Burn Time (s) | 3.30 | 1.55 | terminated by CATO
Total Impulse (Ns) | 8114.46 | partial only | not recoverable

A significant observation from the thrust curve is that the experimental thrust at the moment of failure exceeded the simulated peak — by approximately 13.5%. This indicates that the actual chamber pressure at the time of case burst was likely higher than the 4.34 MPa OpenMotor prediction, not lower. This is the reverse of the correction factor previously derived from the three-grain test (which showed a −18.9% peak thrust deviation), and represents an important update to the team’s understanding of propellant scaling behaviour between grain counts. The five-grain configuration may develop higher-than-simulated Kn or burn rate due to the larger combined burning surface area and inter-grain gas dynamics not fully captured in the simulation.

### 5 Failure Analysis

### 5.1 Failure Mode

The failure is classified as a case burst (CATO). The aluminium casing ruptured during the burn, not at ignition, indicating the structural failure was driven by a condition that developed over the first 1.55 seconds of motor operation rather than an instantaneous ignition-transient overpressure. All personnel were outside the safety exclusion zone and no injuries were sustained.

### 5.2 Root Cause Assessment

Two coupled mechanisms are the primary candidates for the case burst:

1. Thermal softening of the aluminium case wall. The 2 mm liner thickness provides limited thermal insulation over a sustained burn. Aluminium 6063-T5 begins to lose meaningful yield strength above approximately 150–200◦C, and the case exterior on prior tests has been observed to reach temperatures in the 200s◦C range during a burn. As the wall softens under sustained thermal exposure, the effective safety factor against hoop stress failure decreases progressively during the burn even if chamber pressure is constant or declining — this mechanism produces a time-delayed burst characteristic, consistent with the observed failure at t ≈ 1.55 s rather than at ignition.
2. Chamber pressure exceeding the design load. The experimental thrust at the point of failure exceeded the simulated peak, implying actual chamber pressure was above the 4.34 MPa simulation prediction. If the safety factor was already reduced by thermal softening, even a modest pressure exceedance could have been sufficient to trigger burst.

These two mechanisms are coupled: the case wall softens (structural margin erodes) while pressure potentially rises beyond the simulated plateau (applied load increases), creating a double-adverse condition not captured in any single-point, room-temperature safety factor calculation.

### 6 Outcome Classification

This test is classified as a CATO — Catastrophic At Take-Off. The motor burst during the burn, resulting in total loss of the motor hardware. The burn itself was progressing nominally (rising thrust, expected profile shape) up to the point of failure, confirming the propellant formulation and ignition system performed as intended. The failure was structural/thermal in nature, not a combustion or ignition fault.

### 7 Recommendations

1. Conduct a dedicated liner thickness analysis. The role of the 2 mm liner thickness as a potential contributing factor to the thermal softening mechanism is identified here but not fully quantified in this report. A dedicated thermal analysis document is recommended to establish the minimum liner thickness required to protect the aluminium case wall for the full burn duration at 2276◦C combustion temperature, and to determine a revised liner specification for the next five-grain configuration.

2. Evaluate higher-temperature-resistant liner materials. Consider supplementing or replacing the kraft paper/epoxy liner with a phenolic composite or silicone-based liner with higher char resistance and lower thermal diffusivity, to provide greater protection at equivalent thickness.
3. Evaluate case material upgrade. Aluminium 6063-T5 loses significant yield strength above 150◦C. A direct upgrade to 6063-T6 (yield ≈214 MPa at room temperature) or 7075-T6 (yield ≈500 MPa) would substantially increase the room-temperature safety factor and reduce sensitivity to thermal derating. Titanium (Ti-6Al-4V) offers superior thermal stability but at significantly higher material and machining cost.
4. Conduct thermal simulation of the five-grain assembly. A finite-element thermal stress analysis of the liner-case assembly, using the actual combustion temperature and an appropriate transient or equivalent steady-state thermal boundary condition, is recommended to quantify the case wall temperature evolution during the burn and determine the minimum liner thickness required to maintain structural margin throughout. This analysis should account for the temperature-dependent yield strength of the case material.
5. Recalibrate the CATO probability model for the five-grain configuration. The thrust curve indicates the five-grain motor developed higher chamber pressure than the simulated peak, the reverse of the correction factor derived from the three-grain test. The empirical correction factor applied to the five-grain design load should be revised upward accordingly, and structural safety factors should be re-evaluated against the updated pressure estimate.
6. Investigate inter-grain scaling of burn rate and Kn. The inversion of the simulation deviation between the three-grain and five-grain tests (under-thrust at 3 grains, over-thrust at 5 grains at the point of failure) suggests grain-count-dependent burn behaviour not captured in the current simulation model. A dedicated investigation into inter-grain gas dynamics and effective Kn scaling is recommended before further multi-grain testing.
7. Verify x-axis unit labelling in the thrust curve plotting script. The exported thrust curve plots the x-axis as “Time (s)” but internal comparison with simulation data confirms the unit is milliseconds. This should be corrected to avoid misinterpretation in future reports.

Nakuja Project — Solid Propulsion Team, KNSB Solid Rocket Motor Development

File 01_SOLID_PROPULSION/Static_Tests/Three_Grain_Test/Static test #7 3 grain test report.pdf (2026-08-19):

Nakuja Project — Solid Propulsion Team | N4 Three-Grain Static Test Report

# Nakuja Project

## Solid Propulsion Team

## N4 Three-Grain Static Test — Technical Report

Document Version: | 1.0 (Post-Execution Report)
Motor Configuration: | N4, Three-Grain, Aluminium Casing
Date of Execution: | Monday, 17 August 2026
Prepared by: | Paschal Peters (Data Recorder / Timer)
Outcome: | SUCCESS — No issues encountered

## 1 Purpose

This report documents the static test of the N4 three-grain motor configuration conducted on Monday, 17 August 2026. This test extends the team’s single-grain N4 test series to a three-grain configuration, combining three individually prepared grains within a single aluminium casing, separated by a fixed inter-grain spacing. The test was completed successfully, with no issues encountered during preparation, ignition, or burn. This report presents the grain criteria and theoretical configuration, the simulated performance prediction, the experimental results, and recommendations for future three-grain testing.

## 2 Theoretical Section — Grain Criteria and Configuration

### 2.1 Grain Details

Three individually prepared grains were assembled into the N4 casing for this test, each weighed and measured prior to loading.

Grain | Mass (g) | Length (mm) | Liner Thickness (mm)
Grain One | 132.1 | 153.35 | 1.43
Grain Two | 120.4 | 135.53 | 1.43
Grain Three | 141.6 | 160.00 | 1.43
Total (Propellant) | 394.1 | — | —

### 2.2 Assembly and Configuration Details

Inter-grain Spacing | 10 mm
Casing Material | Aluminium
Number of Grains | 3
Total Propellant Mass | 394.1 g
Igniter Mass | 23 g
Total Charge Mass (Propellant + Igniter) | 417.1 g

The 10 mm inter-grain spacing allows combustion gases and flame front to propagate between grain segments, ensuring near-simultaneous ignition across all three grains rather than a sequential, grain-by-grain burn. The igniter mass of 23 g is recorded here as part of the theoretical charge configuration, as it contributes to the total initial mass loaded into the motor and is a required input for the corresponding OpenMotor simulation.

## 3 Simulation

The N4 three-grain configuration was modelled in OpenMotor prior to testing, using the grain geometry, spacing, and igniter mass detailed in Section 2. The simulation predicts the following performance for the assembled three-grain motor:

Parameter | Simulated Value
Peak Thrust | 1462.2 N
Time of Peak Thrust | 1.710 s
Total Impulse | 4627.930 Ns
Burn Time | 3.330 s

The simulated curve for the N4 3grain configuration follows the same fast-rise, sustained-plateau, sharpcutoff shape seen in the team’s earlier single-grain OpenMotor predictions, scaled up in magnitude to reflect the combined burning surface area of three simultaneously burning grains.

## 4 Results

### 4.1 Experimental Performance

Parameter | Experimental Value
Peak Thrust | 1185.7 N
Time of Peak Thrust | 2.668 s
Total Impulse | 4151.053 Ns

Parameter | Experimental Value
Burn Time | 4.943 s

### 4.2 Thrust Curve Comparison

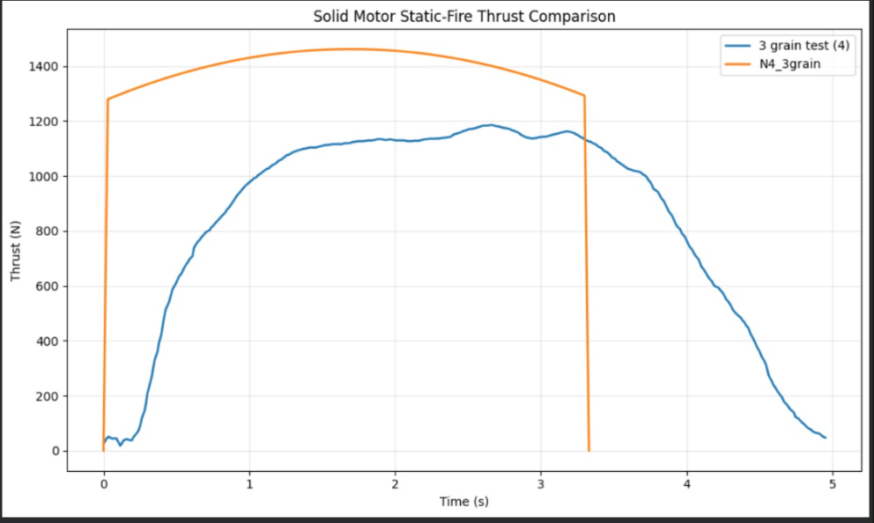
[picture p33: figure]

Figure 1: Solid motor static-fire thrust comparison for the N4 three-grain test (17 August 2026): experimental (blue) vs. simulated N4 3grain prediction (orange).

The experimental curve rises more gradually than the simulation, reaching its peak later (2.668 s vs. 1.710 s simulated) and sustaining a broad, gently rising plateau through the middle of the burn before a longer tail-off, in contrast to the simulation’s fast rise, flat-topped plateau, and sharp cutoff.

### 4.3 Theoretical vs. Experimental Comparison

Parameter | Simulated | Experimental | Deviation
Peak Thrust (N) | 1462.2 | 1185.7 | −18.9%
Time of Peak (s) | 1.710 | 2.668 | +56.0%
Total Impulse (Ns) | 4627.930 | 4151.053 | −10.3%
Burn Time (s) | 3.330 | 4.943 | +48.4%
Average Thrust (N) | 1389.8 | 839.8 | −39.6%

Total impulse delivered was within approximately 10% of the simulated prediction — a reasonably close match. Peak thrust was around 19% lower than predicted, and both burn time and time-of-peak were extended by roughly 48–56% relative to simulation, consistent with the pattern seen in prior single-grain tests: the grain regresses more slowly than the ideal BATES model assumes, spreading a similar total impulse over a longer, gentler burn rather than the sharper, shorter burn predicted.

Note on derived specific-impulse metrics: this report does not include derived specific impulse or effective exhaust velocity figures (as included in some prior single-grain reports), since dividing the recorded total impulse by the recorded total propellant mass (394.1 g) for this test yields values well outside the physically plausible range for a KNSB propellant. This suggests either the recorded grain masses are incomplete relative to what was actually loaded and burned, or a transcription issue exists in the mass or impulse figures. This is flagged here as a data-integrity item for the team to verify, not as a test failure — it does not affect the validity of the thrust-vs-time comparison above, which is self-consistent between the experimental and simulated curves.

## 5 Outcome Classification

This test is classified as a SUCCESS. All three grains ignited and burned as an assembled unit with no issues encountered during setup, ignition, or the burn itself. Performance deviated from the OpenMotor simulation in the expected direction — a longer, gentler burn delivering slightly less total impulse than predicted — consistent with the burn-time discrepancy pattern already documented across the team’s single-grain KNSB tests.

## 6 Recommendations

- Verify and reconcile the recorded total propellant mass (394.1 g) against the total impulse delivered (4151.053 Ns) for this test, as the two figures are inconsistent with typical KNSB specific impulse values — confirm whether all grain mass was correctly recorded or whether an additional mass component was omitted.
- Continue applying the burn-time correction measures already under investigation (surfactant dosing, vacuum degassing, grain homogeneity) to the three-grain configuration, as the same slow-regression pattern seen in single-grain tests is present here at multi-grain scale.
- Retain this test as the baseline three-grain dataset for comparison against future multi-grain configurations, including any changes to inter-grain spacing or grain count.
- Instrument chamber pressure on the next three-grain test, consistent with the team’s ongoing plan for single-grain tests, to enable proper burn-rate characterisation across the larger combined burning surface area of a multi-grain assembly.

Nakuja Project — Solid Propulsion Team, KNSB Solid Rocket Motor Development

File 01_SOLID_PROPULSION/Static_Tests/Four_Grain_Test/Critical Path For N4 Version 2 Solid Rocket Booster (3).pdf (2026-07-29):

## Critical Path For N4 Version 2 Solid Rocket Booster

Nakuja Rocketry Club – Solid Propulsion Team
Critical Path Documentation: N4 Version 2 Solid Rocket Booster
Design → Static Test (3-Week Cycle)

Target: Complete one full 4-grain SRB design-to-static-test cycle within 3 weeks. After a successful static test, produce two flight-ready SRBs (one per week) for early-September dual launch.

Overall Goal: Reliable 4-grain KNSB BATES motor delivering ~2.5 kN peak thrust for 3.5 km apogee.

## 1. Critical Path Overview

The critical path is the sequence of dependent tasks that determines the shortest possible time to complete the cycle. Any delay on these tasks delays the entire project.

Critical Path Sequence:

Total Target Duration: 21 days (3 weeks)

## 2. Team Roles & Responsibilities

1. Design (OpenMotor + OpenRocket) →
2. Purchasing →
3. Parallel Fabrication (3D printing + Machining + Grain cooking) →
4. Grain curing (1 week) + concurrent non-grain tasks →
5. Dry assembly → Wet assembly →
6. Static fire test

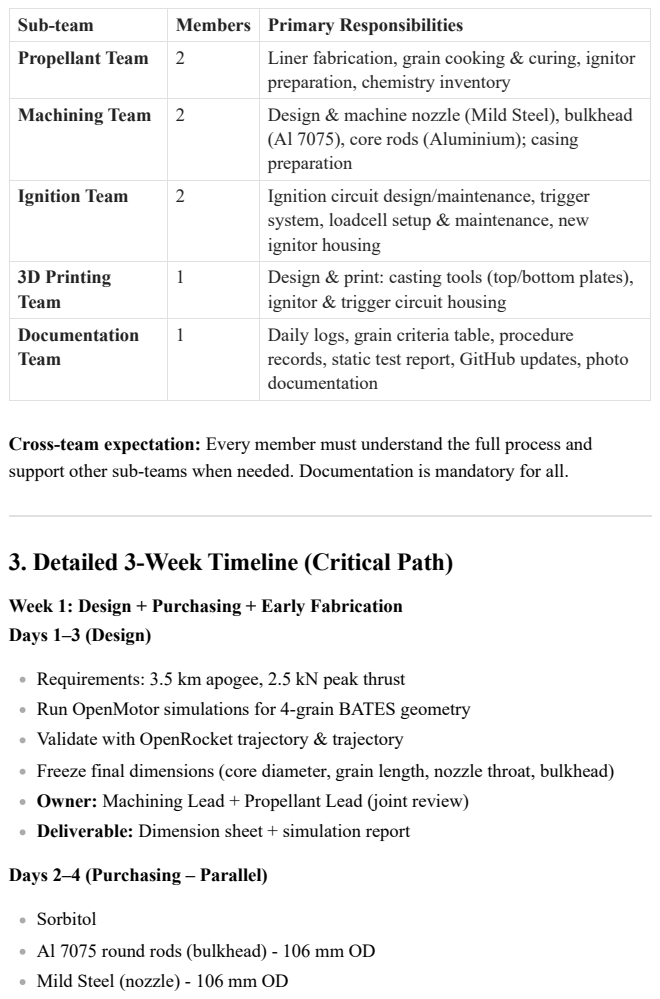
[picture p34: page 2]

Sub-team | Members | Primary Responsibilities
Propellant Team | 2 | Liner fabrication, grain cooking & curing, ignitor preparation, chemistry inventory

Machining Team | 2 | Design & machine nozzle (Mild Steel), bulkhead (Al 7075), core rods (Aluminium); casing preparation

Ignition Team | 2 | Ignition circuit design/maintenance, trigger system, loadcell setup & maintenance, new ignitor housing

3D Printing Team | 1 | Design & print: casting tools (top/bottom plates), ignitor & trigger circuit housing

Documentation Team | 1 | Daily logs, grain criteria table, procedure records, static test report, GitHub updates, photo documentation

Cross-team expectation: Every member must understand the full process and
support other sub-teams when needed. Documentation is mandatory for all.

3. Detailed 3-Week Timeline (Critical Path)

Week 1: Design + Purchasing + Early Fabrication
Days 1–3 (Design)

Requirements: 3.5 km apogee, 2.5 kN peak thrust
Run OpenMotor simulations for 4-grain BATES geometry
Validate with OpenRocket trajectory & trajectory
Freeze final dimensions (core diameter, grain length, nozzle throat, bulkhead)
Owner: Machining Lead + Propellant Lead (joint review)
Deliverable: Dimension sheet + simulation report

Days 2–4 (Purchasing – Parallel)

Sorbitol
Al 7075 round rods (bulkhead) - 106 mm OD
Mild Steel (nozzle) - 106 mm OD

Days 3–7 (Early Fabrication)

Week 2: Main Fabrication + Curing Start Days 8–14

Critical Note: Grain curing occupies 7 days. Use this time for test-stand reinforcement, load-cell calibration, and dry-assembly preparation.

Aluminium core rods - 50 mm OD PLA filament - High Speed
Crafting paper, epoxy, brushes/rollers Springs, nuts, compression hardware
Ziplock bags
1 pyrogenic ignitor
Owner: Designated purchasing member (coordinate bulk order) - BenCollins Mureithi, Alex
Deliverable: All materials received and logged

3D Printing: 4 pairs of casting tools (top + bottom plates) – 1 day Machining: Core rods (multiple diameters) – 2 days per rod (parallel where possible)
Fabricate liners (crafting paper + epoxy)
Owner: 3D Printing (1 day), Machining Team (ongoing)

Propellant Team:
Cook 4 grains (2 per day)
Start 7-day cure under compression Machining Team:
Machine nozzle (3 days)
Machine bulkhead (3 days) – run in parallel Ignition Team:
Design/print new ignitor housing Prepare/test ignition circuit & pressure sensor 3D Printing: Support any remaining tools Documentation: Update grain criteria table daily

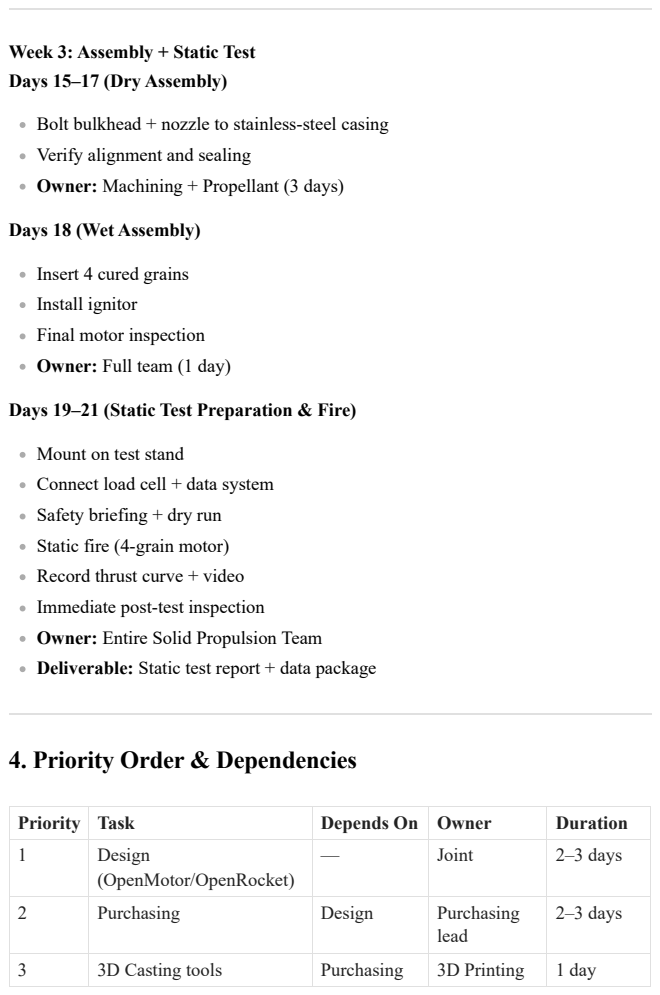
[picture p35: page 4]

Week 3: Assembly + Static Test
Days 15–17 (Dry Assembly)

Bolt bulkhead + nozzle to stainless-steel casing
Verify alignment and sealing
Owner: Machining + Propellant (3 days)

Days 18 (Wet Assembly)

Insert 4 cured grains
Install ignitor
Final motor inspection
Owner: Full team (1 day)

Days 19–21 (Static Test Preparation & Fire)

Mount on test stand
Connect load cell + data system
Safety briefing + dry run
Static fire (4-grain motor)
Record thrust curve + video
Immediate post-test inspection
Owner: Entire Solid Propulsion Team
Deliverable: Static test report + data package

4. Priority Order & Dependencies

Priority | Task | Depends On | Owner | Duration
1 | Design (OpenMotor/OpenRocket) | — | Joint | 2–3 days

2 | Purchasing | Design | Purchasing lead | 2–3 days

3 | 3D Casting tools | Purchasing | 3D Printing | 1 day

Priority | Task | Depends On | Owner | Duration
4 | Core rods machining | Purchasing | Machining | 2 days each
5 | Liner + Grain cooking | Casting tools + core rods | Propellant | 2 days cooking
6 | Nozzle + Bulkhead | Purchasing | Machining | 3 days each (parallel)
7 | Grain curing | Cooking | Propellant | 7 days
8 | Dry assembly | Nozzle + Bulkhead | Machining | 3 days
9 | Wet assembly | Cured grains | Propellant + Machining | 1 day
10 | Static test | Full assembly | Full team | 1–2 days

## 5. Post-Static-Test Plan (Two Flight Motors)

After successful static test:

## 6. Daily Operating Rules

Week 4: Re-use SRB #1 (repeat critical path at accelerated pace) Week 5: Produce SRB #2
Target: Both motors ready for dual launch in early September

Working hours: 9:00 AM – 5:00 PM (lunch 1–2 PM)
Daily photo + activity summary required
Clean workstation by 4:45 PM
All changes and data logged in GitHub by Documentation Team

## 7. Risk Mitigation

Risk | Mitigation
Delayed materials | Consolidate purchasing early; maintain buffer stock
Grain voids/cracks | Pressure curing + vacuum if available; microscope checks
Machining delays | Parallel nozzle/bulkhead work; prioritize critical items
Curing delay | Start cooking as soon as tools are ready
Test stand issues | Use curing week for reinforcement and load-cell calibration

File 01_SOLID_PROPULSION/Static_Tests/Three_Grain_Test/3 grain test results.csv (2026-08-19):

Time | Thrust (N)
8 | 30.79
21 | 43.58
34 | 50.3
59 | 44.03
71 | 43.8
89 | 44.63
101 | 31.85
115 | 17.96
127 | 26.77
139 | 37.81
159 | 41.95
183 | 37.7
195 | 37.7
205 | 48.14
227 | 62.63
241 | 73.96
253 | 93.14
263 | 117.48
282 | 144.86
292 | 172.7
301 | 207.09
317 | 239.28
331 | 269.02
341 | 300.66
352 | 331.77
371 | 360.36
380 | 390.76
397 | 423.06
406 | 454.9
416 | 485.22
427 | 513.77
449 | 540.44
462 | 565.01
474 | 587.2
493 | 605.29
507 | 620.54
517 | 633.26
534 | 644
544 | 655.38
555 | 666.61
567 | 677.43
581 | 688.09
593 | 698.81
611 | 708.65
621 | 737.9
631 | 747.27
642 | 757.8
661 | 768.13
674 | 777.77
689 | 786.6
701 | 794.77
729 | 803.07
739 | 812.31
757 | 821.19
768 | 828.82
781 | 836.54
798 | 846.13
816 | 856.55
835 | 866.55
845 | 876.32
863 | 886.03
874 | 895.28
886 | 904.19
898 | 914.26
909 | 923.27
919 | 931.26
936 | 940.29
947 | 948.21
960 | 956.08
974 | 964.64
991 | 972.64
1005 | 978.96
1019 | 984.69
1030 | 990.72
1049 | 995.52
1059 | 1002.48
1078 | 1008.78
1089 | 1013.44
1099 | 1018.04
1113 | 1023.71
1135 | 1028.62
1149 | 1035.34
1160 | 1039.98
1178 | 1044.54
1189 | 1049.51
1202 | 1055.53
1221 | 1060.33
1233 | 1065.45
1245 | 1070.34
1255 | 1075.51
1273 | 1077.86
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

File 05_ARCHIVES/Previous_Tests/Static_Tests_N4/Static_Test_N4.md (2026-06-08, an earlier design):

This file contains information about all tests done in the N4 rocket development.

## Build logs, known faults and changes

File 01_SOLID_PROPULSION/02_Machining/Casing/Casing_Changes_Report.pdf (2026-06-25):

NAKUJA PROJECT | Solids Mechanical — 2026 Progress Report | CONFIDENTIAL | June 2026

# 2026 SOLIDS MECHANICAL

## Progress Report — Attachment Team

Original: 16 June 2026 | Updated: 17 June 2026 | Classification: Internal

## 1. Introduction

This document is the Solids team's 2026 internal progress ledger for the attachment sub-team. It covers the existing motor casing design, structural calculations, open-motor simulation results, key challenges encountered this season, and the evaluation of alternative casing materials. Update (17 June 2026): Sections 9–12 have been added, covering formalised BATES grain geometry design rules and the structural and performance evaluation of a third candidate casing material, Stainless Steel G316, against the Aluminium and Carbon Steel designs above.

## 2. Existing Motor Casing Design

### 2.1 Geometry & Material

The baseline motor casing is fabricated from Aluminium 6063-T5 alloy. The key dimensional and material parameters are listed below.

Material: Aluminium 6063-T5 Alloy
Inner Diameter: 94 mm
Outer Diameter: 100 mm (wall thickness = 3 mm) Length: 825 mm

Young's Modulus (E): 70,000 MPa
Poisson's Ratio (μ): 0.33
Yield Strength (σyp): 110 MPa
Ultimate Tensile Strength (σuts): 150 MPa

### 2.2 Design Loads

The following design inputs were used across all structural calculations:
- Maximum Expected Operating Pressure (MEOP, Pe): 4.26 MPa
- Safety Factor (Sf): 1.5

### 2.3 Structural Calculations — Aluminium Casing

Minimum Wall Thickness
Formula: t = (Pe × d × Sf) / (2 × σyp)
Result: t = (4.26 × 94 × 1.5) / (2 × 110) = 2.730 mm → Selected thickness: 3 mm (manufacturing tolerance)

Expected Change in Length
Formula: ΔL = (Pe × d × L × (1 − 2μ)) / (4 × t × E)
Result: ΔL = (4.26 × 94 × 725 × (1 − 2×0.33)) / (4 × 3 × 70,000) → ≈ 0.1379 mm

Expected Change in Diameter
Formula: Δd = (Pe × d² × (1 − μ)) / (4 × t × E)
Result: Δd = (4.26 × 94² × (1 − 0.33)) / (4 × 3 × 70,000) → ≈ 0.0352 mm

Burst Pressure
Formula: PB = (2 × t × σuts) / d
Result: PB = (2 × 3 × 150) / 94 → ≈ 9.57 MPa (safety margin vs MEOP: ~2.25×)

## 3. Open Motor Simulation — Baseline Aluminium Design

An open-motor simulation of the propellant grain stack generated the following performance estimates. The configuration consists of five grains, each 145 mm long and 86 mm in diameter for the aluminium design and 96.26 mm in diameter for the carbon steel design, with a stepped-core diameter sequence (bulk-head to aft) of {38, 35, 35, 34, 34} mm.

Metric | Aluminium Design | Carbon Steel Design
Motor Designation | M2458 (58%) | M3458 (38%)
Impulse | 8,114.60 Ns | 10,855 Ns
Average Pressure | 3.98 MPa | 4.74 MPa
Peak Pressure | 4.42 MPa | 5.47 MPa
Delivered ISP | 134.92 s | 137.30 s

Metric | Aluminium Design | Carbon Steel Design
Burn Time | 3.27 s | 3.60 s
Propellant Mass | 6.13 kg | 8.06 kg
Propellant Length | 725 mm | 725 mm
Thrust | 2,458 N | 2,990 N
Port/Throat Ratio | 2.73 | 2.73
Volume Loading | 83.22% | 86.70%

## 4. Challenges

Two primary challenges have been identified this season:

- Material sourcing (primary challenge): Aluminium 6063-T5 stock with the required inner or outer diameter is not readily available from local Kenyan suppliers. This was the principal factor behind previous failed static tests.
- Grain porosity: Prior motors suffered catastrophic failures attributable in part to air cavities within the propellant grain, leading to unpredictable burn behaviour.

## 5. Team Goals & Responsibilities — 2026 Season

- Identify and qualify a locally available casing material and adapt the design accordingly.
- Improve grain casting procedures to minimise internal porosity and air cavities.
- Conduct a successful static motor test.
- Produce flight-ready motors for the actual launch campaign.

## 6. Motor Casing Material Selection

Because neither Aluminium 6063-T5 nor 6061-T6 is available locally in dimensions close to those required, two alternative materials were assessed. Machining constraints restrict pipe modifications to turning (OD reduction) or boring (ID enlargement) — not both simultaneously.

### 6.1 Option A — Mild Steel (Existing Inventory)

Available Stock (Nakuja inventory):
- Inner Diameter: 89.03 mm
- Outer Diameter: 115 mm
- Cut Length: 750 mm

Machining plan: Hold ID constant; turn OD down to 94 mm for a wall thickness of ~2.5 mm Liner thickness: 3 mm → effective grain diameter: 83 mm
Grain height: 130 mm (5 grains)

Simulation Results (Mild Steel)
- Impulse: 6,525 Ns (vs. 8,114.60 Ns baseline — 20% reduction)
- Thrust: 2,014 N (vs. 2,458 N baseline — 18% reduction)
- Port/Throat Ratio: 2.73

Assessment
- Advantages: Already in inventory; can be turned to fit.
- Disadvantages: Heavier than aluminium; pre-cut length limits usable grain volume despite available casing height; lower impulse than baseline.
- Verdict: Not recommended. The combined effect of reduced thrust (2,014 N vs 2,458 N) and higher casing mass would significantly compromise the target apogee.

### 6.2 Option B — Grade B API 5L Schedule 40 Carbon Steel

Off-the-shelf dimensions:
- Outer Diameter: 114.3 mm
- Inner Diameter: 102.26 mm (off-the-shelf)
- Stock Length: 5,800 mm

Material properties:
- Yield Strength (σyp): 241 MPa (SMYS)
- UTS (σuts): | 415 MPa (minimum)

- Young's Modulus (E): | 200,000 MPa
- Poisson's Ratio (μ): | 0.30

Structural Calculations — Carbon Steel Casing
Min. Thickness: t = (4.26 × 102.26 × 1.5) / (2 × 241) → ≈ 1.34 mm → Selected: 2 mm
ΔL: ΔL = (4.26 × 102.26 × 825 × (1 − 2×0.3)) / (4 × 2 × 200,000) → ≈ 0.090 mm
Δd: Δd = (4.26 × 102.26² × (1 − 0.3)) / (4 × 2 × 200,000) → ≈ 0.0195 mm
Burst Pressure: PB = (2 × 2 × 415) / 102.26 → ≈ 16.23 MPa (safety margin vs MEOP: ~3.81×)

Simulation Results (Carbon Steel, grain dia. = 96.26 mm, h = 145 mm)
- Impulse: 10,855 Ns (vs. 8,114.60 Ns baseline — +34%)
- Thrust: 2,990 N (vs. 2,458 N baseline — +22%)
- Port/Throat Ratio: 2.73
- Note: Peak mass flux exceeds the 2.0 lb/s/in² threshold for non-erosive burning. Nozzle redesign is required.

Assessment
- Advantages: Locally available in Kenya; high burst pressure (16.23 MPa); larger bore increases propellant volume and compensates for added casing mass.
- Disadvantages: Heavier than aluminium; peak mass flux exceeds non-erosive limit — nozzle must be redesigned to accomodate the high flow rates of between 2.0 and 3.0.

## 7. Material Comparison Summary

The table below compares the two candidate materials against the aluminium baseline across all structural and performance metrics.

Parameter | Aluminium 6063-T5 | API 5L Gr B Carbon Steel | Notes
Inner Diameter | 94 mm | 102.26 mm | Steel has larger bore
Wall Thickness | 3 mm | 2 mm | Steel needs less material
Min. Required t (hoop) | 2.73 mm | 1.34 mm | Steel ~2× stronger
ΔL (length change) | 0.157 mm | 0.090 mm | Steel ~1.8× less deformation

Parameter | Aluminium 6063-T5 | API 5L Gr B Carbon Steel | Notes
Δd (diameter change) | 0.040 mm | 0.0195 mm | Steel ~2.1× less change
Burst Pressure | 9.57 MPa | 16.23 MPa | Steel ~70% higher
Safety Margin vs MEOP | ~2.25× | ~3.81× | Steel significantly safer
Weight | Lighter | Heavier | Higher density + thickness
Simulated Impulse | 8,114.60 Ns | 10,855 Ns | Steel ~34% more impulse
Simulated Thrust | 2,458 N | 2,990 N | Steel ~22% more thrust

## 8. Recommendation & Next Steps 16 June 2026

Based on the structural analysis and simulation results, the team recommends proceeding with Grade B API 5L Schedule 40 carbon steel as the motor casing material.

RECOMMENDED: Grade B — API 5L Schedule 40 Carbon Steel

Action items:
1. Procure API 5L Gr B Schedule 40 pipe stock (OD 114.3 mm, ID 102.26 mm).
2. Turn casing wall to a final thickness of 1.5 – 2.0 mm.
3. Maintain inner casing diameter at 102.26 mm.
4. Determine final grain diameter after liner thickness is confirmed.
5. Redesign the nozzle to bring peak mass flux below 2.0 lb/s/in².
This eliminates the risk of erosive burning, over-pressurisation, and CATO.

## 9. BATES Grain Geometry & Erosive Burning Design Limits

Before evaluating Stainless Steel G316 as a casing material, the team formalised three geometric design rules that govern safe BATES grain combustion. These rules were applied retroactively to flag a margin issue in the existing aluminium-based design and were used going forward to size the G316 grain stack.

### 9.1 Grain Length-to-Diameter Ratio (Neutrality)

Each individual BATES grain segment burns from the inner core outward (progressive, as internal surface area increases) and from its two flat ends inward (regressive, as the segment shortens). These two effects cancel almost exactly when the segment length is approximately 1.5 times its outer diameter, producing a near-neutral thrust profile.

Lg / Do ≈ 1.5
Lg = length of a single grain segment | Do = outer diameter of the propellant grain

References
(U.S. Air Force Rocket Propulsion Laboratory and United Technology Center (https://apps.dtic.mil/sti/tr/pdf/ADA004218.pdf) #Pg 4-5) (Davenas #Chapter 2)Access this book here (https://archive.org/details/A.DavenasEds.SolidRocketPropulsionTechnology)

### 9.2 Port-to-Throat Area Ratio (Erosive Burning Safety)

When multiple BATES segments are stacked into a single motor, the ratio of core cross-sectional area (AP) to nozzle throat area (AT) sets the absolute ceiling on how much gas can travel down the core before erosive burning becomes dangerous. This is treated as the single most safety-critical metric for a KNSB motor of this scale.

AP / AT = (core cross-sectional area) / (nozzle throat cross-sectional area)

### 2.0 to 3.0 — acceptable range, scaled by motor length

- Short motors (2–3 grains): an AP/AT of 2.0 is acceptable.
- Long motors (4–6 grains): AP/AT of 2.5–3.0 is required to accommodate the larger accumulated gas volume travelling down the core provide peak pressures are below 4.14 Mpa (Kloeblen)

References
(Sutton and Biblarz) Access this book here (https://books.google.co.ke/books/about/Rocket_Propulsion_Elements.html?id=XwSRDQAAQBAJ&redir_esc=y)
(Kloeblen) Access this Applied Engineering Citation (https://www.nakka-rocketry.net/articles/Erosive_Burning_Design_Criteria.pdf)

### 9.3 Port Length-to-Diameter Ratio (Overall Core Length Limit)

If total grain stack length is too long relative to grain diameter, gas generated at the forward end of the motor must travel a long distance down the core before reaching the nozzle, accelerating to velocities that drive severe erosive burning and chamber pressures beyond the casing's structural limit.
- Standard range for 3–4 grain KNSB BATES motors: L/D between 4.5 and 6.0.
- Absolute maximum: L/D = 7.5. Crossing this threshold with standard straight BATES grains makes erosive burning practically unavoidable unless the core is deliberately widened well past the normal standard, which wastes propellant volume. For stepped cores 8.5 is the absolute maximum

Design flag: the previous aluminium design's port length-to-grain-diameter ratio was 8.4 —
close the 8.5 maximum for stepped core designs.

References
Nakka, R. (2020). KNPSB propellant chemistry and performance characteristics. Richard Nakka's Experimental Rocketry Site. nakka-rocketry.net

## 10. Stainless Steel G316 — Candidate Casing Material

A third candidate material, Stainless Steel Round Tube Grade 316, was identified for sourcing from Ken's Metal Industries. Its properties were compared against the Grade B API 5L Schedule 40 carbon steel evaluated on 16 June 2026 (Section 6.2) and against the original Aluminium 6063-T5 baseline (Section 2).

### 10.1 Geometry & Material Properties

Material: Stainless Steel G316 (Austenitic, molybdenum-bearing for superior corrosion resistance)
Outer Diameter: 101.6 mm (off-the-shelf)
Inner Diameter: 97.6 mm (off-the-shelf) → casing wall thickness = 2.0 mm
Stock Length: 5,800 mm

Liner thickness (insulation, inside casing): 3 mm → effective grain outer diameter = 91.6 mm

Yield Strength (σyp): 205 MPa (SMYS)
Ultimate Tensile Strength (σuts): 515 MPa (minimum)
Young's Modulus (E): 200,000 MPa
Poisson's Ratio (μ): 0.30

### 10.2 Grain Stack Sizing Against the Section 9 Design Rules

With a grain outer diameter of 91.6 mm (after liner), the Section 9 ratios were used to size the grain stack:
- Max port length (L/D ≤ 7.5): 91.6 × 7.5 ≈ 687 mm
- Max single-grain length (Lg/Do ≈ 1.5): 91.6 × 1.5 ≈ 137 mm
Selected configuration: 5 grains at 130 mm each.
- Grain geometry ratio: 130 / 91.6 ≈ 1.4 — slightly below the 1.5 neutral point, giving a mildly regressive burn (a small thrust tail-off near the end of burn). This is treated as desirable for a long motor since it naturally relieves chamber pressure as the casing heats up.
- Port length: 130 × 5 = 650 mm
- Port L/D ratio: 650 / 91.6 ≈ 7.1, rounded to 7.0 for reporting — comfortably under the 8.5 ceiling and a meaningful improvement over the aluminium design's 8.4.

Why not push closer to the 8.5 limit: at this 91.6 mm grain diameter, KNSB propellant shrinks slightly as it cools after casting, which can leave small structural gaps or micro-cracks. Designing right at the geometric maximum leaves no margin — a minor casting imperfection could trigger an ignition pressure spike. The 7.0–7.1 ratio leaves room for that variability.

## 11. Structural Calculations & Simulation — G316 Casing

### 11.1 Open Motor Simulation

Holding the same stepped core diameter configuration used in the aluminium design (nozzle-end to bulkhead: 38, 35, 35, 34, 34 mm), an open-motor simulation of the five-grain, 91.6 mm diameter G316 stack produced the following:

Metric | Aluminium Baseline | Stainless Steel G316
Impulse | 8,114.60 Ns | 8,347.56 Ns
Thrust | 2,458 N | 2,226 N
Port/Throat Ratio | 2.73 | 2.73
MEOP (Pe) | 4.26 MPa | 4.06 MPa

Impulse is marginally higher than the aluminium baseline, but thrust is lower than both the aluminium baseline (2,458 N) and the carbon steel design (2,990 N, Section 3). This trade-off is a direct consequence of designing strictly within the Section 9 erosive-burning limits rather than pushing grain geometry as far as the carbon steel design did.

### 11.2 Structural Calculations

Min. Thickness: t = (Pe × d × Sf) / (2 × σyp) = (4.06 × 97.6 × 1.5) / (2 × 205) ≈ 1.45 mm → Selected: 2.0 mm (~1.38× minimum required)
ΔL (length change): ΔL = (Pe × d × L × (1 − 2μ)) / (4 × t × E) = (4.06 × 97.6 × 750 × (1 − 0.6)) / (4 × 2 × 200,000)
≈ 0.074 mm
Δd (diameter change): Δd = (Pe × d² × (1 − μ)) / (4 × t × E) = (4.06 × 97.6² ×
0.7) / (4 × 2 × 200,000)
≈ 0.017 mm
Burst Pressure: PB = (2 × t × σuts) / d = (2 × 2.0 × 515) / 97.6
≈ 21.11 MPa (safety margin vs MEOP: ~5.2×)

### 11.3 Thrust-to-Weight Ratio

Design | Thrust (N) | Rocket Weight (N) | Thrust : Weight
Aluminium 6063-T5 | 2,458 | 247.7 | 9.93 : 1
Stainless Steel G316 | 2,226 | 286.7 | 7.76 : 1

A thrust-to-weight ratio between 5:1 and 10:1 is considered acceptable for this airframe. G316's 7.76:1 clears that bar but sits below the aluminium baseline, driven by the casing's higher density.

## 12. Three-Way Material Comparison & Recommendation

The table below extends the Section 7 comparison to include Stainless Steel G316 alongside the Aluminium 6063-T5 baseline and the API 5L Gr B Carbon Steel candidate.

Parameter | Aluminium 6063-T5 | Mild steel (In stores) | API 5L Gr B Mild Steel | Stainless Steel G316
Available length | - | 725 mm | - | -
Outer Diameter | 100 mm | 115 mm | 114.3 mm | 101.6 mm
Inner Diameter | 94 mm | 89.03 mm | 102.26 mm | 97.6 mm
Liner thickness | 3 mm | 3 mm | 3 mm | 3 mm
Grain Diameter | 88 mm | 83 mm | 96.26 mm | 91.6 mm
Peak Pressure | 4.26 MPa | 3.58 MPa | 6.63 MPa | 4.63 MPa
Grain Length | 145 mm | 130 mm | 145 mm | 140 mm
No. of Grains | 5 | 5 | 5 | 5
Grain Steps (Bulk head to nozzle) | (34,34,35,35,38) | (34,34,35,35,38) | (34,34,35,35,38) | (34,34,35,35,38)
Yield Strength | 110 MPa | 250 MPa | 245 MPa | 205 MPa
UTS | 150 MPa | 400 MPa | 415 MPa | 515 MPa
Youngs Modulus | 70 GPa | 200 GPa | 200 GPa | 200 GPa
Min. Required t [sf = 1.5] | 2.73 mm | 1.2 mm | 2.1 mm | 1.7 mm
Min. Required t [sf = 2.0] | 3.6 mm | 1.6 mm | 2.8 mm | 2.2 mm
Selected Thickness | 3.0 mm (fixed) | 2.5 mm | 2.5 mm | 2.0 mm (fixed)
Final Outer Diameter | 100 mm | 91.53 mm | 104.76 mm* | 101.6 mm
Burst Pressure | 9.57 MPa | 22.46 MPa | 20.29 MPa | 21.11 MPa
Safety Margin vs MEOP | ~2.25× | ~6.27× | ~3.10× | ~4.56×
Simulated Impulse | 8,114.60 Ns | 6,525.66 Ns | 10,768.32 Ns | 9135.88 Ns
Simulated Thrust | 2,458 N | 2,014 N | 2,966 N | 2,537 N
Density | ~ 2800 kg/m³ | ~ 8000 kg/m³ | ~ 8000 kg/m³ | ~ 8000 kg/m³
Casing Length | 825 mm | 750 mm | 825 mm | 800 mm
−6 Casing Volume (× 10 ) | 754.22 m³ | 265.90 m³ | 335.35 m³ | 500.64 m³
Casing Mass | 2.11 kg | 2.13 kg | 2.68 kg | 4.01 kg
Propellant Mass | 6.48 kg | 5.05 kg | 8.00 kg | 6.86 kg
Motor Mass (Bulk head mass ~594g) (Nozzle mass ~3500g) | ~12.68 kg | ~11.27 kg | ~14.77 kg | ~14.96 kg

Parameter | Aluminium 6063-T5 | Mild steel (In stores) | API 5L Gr B Mild Steel | Stainless Steel G316
Simulated Apogee | | | | ~2922 m
Thrust : Weight | 9.93 : 1 | | — | 7.76 : 1
Local Availability (Kenya) | Limited | In Stores | Available | Available

### 12.1 Assessment

- Advantages: Highest burst pressure and safety margin of the three candidates (~5.2× MEOP); off-the-shelf dimensions require no machining; no nozzle or core redesign needed; superior corrosion resistance versus carbon steel; the only candidate designed within the full Section 9 erosive-burning limits (Port L/D = 7.0 vs the carbon steel design's unresolved nozzle redesign requirement).
- Disadvantages: Lower thrust than both other candidates, driven by conservative grain geometry rather than material limitations; heavier than aluminium, reducing thrust-to-weight ratio and projected apogee; cost not yet confirmed with the supplier.

### 12.2 Conclusion

Stainless Steel G316 tube, 4" (101.6 mm) OD with a 2 mm wall thickness, is usable as a casing material with no additional machining, no nozzle redesign, and no body tube redesign. The resulting motor still qualifies as M-class despite the reduction in thrust, and simulated burn time increased from 3.27 s (aluminium) to 3.72 s. This is a direct result of designing the grain stack for smoother, non-erosive combustion under the Section 9 geometry rules, rather than maximising thrust. The aluminium design's Port L/D ratio of 8.4 close the 8.5 safety threshold; the G316 design's ratio of 7.0 corrects this and increases confidence in the motor's probability of a successful burn. The main open concern is the impact of the added casing weight on projected apogee.

RECOMMENDATION — Next Steps 17 June 2026
1. Contact Ken's Metal Industries for a firm quote on Stainless Steel G316 tube stock.
2. Obtain a comparable quote for API 5L Gr B carbon steel, inclusive of machining to size, for a direct cost comparison.
3. Model the impact of the increased G316 casing weight on projected apogee.
4. Confirm final grain outer diameter (91.6 mm) once liner thickness is verified against the as-received tube ID.
5. Carry forward the Section 9 BATES geometry rules as a standing design check for all future grain stack revisions if a successful static test is achieved

Works Cited
1. Richard Nakka's Experimental Rocketry Site, http://nakka-rocketry.net. Accessed 17 June

2026.

2. Davenas, Alain, editor. Solid Rocket Propulsion Technology. Elsevier Science &

Technology Books, 1993. Accessed 17 June 2026.

3. Kloeblen, William R. “Erosive Burning Design Criteria for High Power and Experimental

Solid Rocket Motors.” Richard Nakka Rocketry Research Portal,

https://www.nakka-rocketry.net/articles/Erosive_Burning_Design_Criteria.pdf. Accessed

17 June 2026.

4. Sutton, George P., and Oscar Biblarz. Rocket Propulsion Elements. Wiley, 2016.

Accessed 17 June 2026.

5. U.S. Air Force Rocket Propulsion Laboratory, and United Technology Center. “BALLISTIC

MISSILE PROPELLANT EVALUATION TEST MOTOR SYSTEM (SUPER BATES).”

Technical Report AFRPL-TR-74-63 details the Super BATES (Ballistic Test and

Evaluation System), a standardized, case-bonded solid propellant system developed for

high-precision motor performance measurements. This 1974 Air Force Rocket Propulsion

Laborator. TECHNICAL REPORT - AFRPL-TR-74-63, NATIONAL TECHNICAL

INFORMATION SERVICE - U. S. DEPARTMENT OF COMMERCE, 25 November 1974,

https://apps.dtic.mil/sti/tr/pdf/ADA004218.pdf. Accessed 17 June 2026.

— End of Report —

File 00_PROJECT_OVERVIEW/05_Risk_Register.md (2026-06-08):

This file outlines the possible risks one is exposed to due to the nature of the project.

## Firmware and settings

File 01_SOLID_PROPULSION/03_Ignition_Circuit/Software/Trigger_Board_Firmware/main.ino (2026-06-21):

/*
  Nakuja Project — Trigger Board Firmware

  Purpose:
  - Receive telemetry from the igniter board through ESP-NOW.
  - Parse igniter telemetry in CSV format: thrust,temp,pressure.
  - Convert telemetry into JSON for the web dashboard.
  - Create a Wi-Fi access point for dashboard connection.
  - Run a WebSocket server on port 81.
  - Send ignition command to the igniter board when the operator button is released.
  - Provide local feedback through LCD and buzzer.

  Dashboard JSON format:
  {
    "thrust": 12.8,
    "temp": 27.5,
    "pressure": 101.3,
    "ignition_armed": false,
    "event": "Telemetry update"
  }
*/

#include <Arduino.h>
#include <WiFi.h>
#include <esp_now.h>
#include <WebSocketsServer.h>
#include <ArduinoJson.h>
#include <LiquidCrystal_I2C.h>
#include "pitches.h"

// -----------------------------------------------------------------------------
// LCD Setup
// -----------------------------------------------------------------------------

const int LCD_COLUMNS = 16;
const int LCD_ROWS = 2;

LiquidCrystal_I2C lcd(0x3F, LCD_COLUMNS, LCD_ROWS);

// -----------------------------------------------------------------------------
// Pin Definitions
// -----------------------------------------------------------------------------

#define BUZZER_PIN 18
#define STATUS_BUTTON_PIN 32

// -----------------------------------------------------------------------------
// Button State
// -----------------------------------------------------------------------------

// INPUT_PULLUP logic:
// HIGH = button released
// LOW  = button pressed
bool buttonReleased = true;

// -----------------------------------------------------------------------------
// Melody Setup
// -----------------------------------------------------------------------------

int melody[] = {
  NOTE_C4, NOTE_G3, NOTE_G3, NOTE_A3,
  NOTE_G3, 0, NOTE_B3, NOTE_C4
};

int noteDurations[] = {
  4, 8, 8, 4,
  4, 4, 4, 4
};

const int MELODY_LENGTH = 8;

bool isPlayingMelody = false;
int currentNote = 0;
unsigned long noteStartTime = 0;

// -----------------------------------------------------------------------------
// Wi-Fi and WebSocket Setup
// -----------------------------------------------------------------------------

const char *WIFI_AP_SSID = "NAKUJA";
const char *WIFI_AP_PASSWORD = "12345678";

const uint16_t WEBSOCKET_PORT = 81;

WebSocketsServer webSocket = WebSocketsServer(WEBSOCKET_PORT);

// -----------------------------------------------------------------------------
// Telemetry Data
// -----------------------------------------------------------------------------

float thrustVal = 0.0;
float tempVal = 0.0;
float pressureVal = 0.0;

// ESP-NOW receive buffer.
// The callback copies received data here, then loop() processes it.
volatile bool newDataReady = false;
char packetBuffer[ESP_NOW_MAX_DATA_LEN + 1];

// -----------------------------------------------------------------------------
// Timing Variables
// -----------------------------------------------------------------------------

unsigned long lastLcdUpdate = 0;
const unsigned long LCD_UPDATE_INTERVAL_MS = 250;

// -----------------------------------------------------------------------------
// Function Prototypes
// -----------------------------------------------------------------------------

void receiveCallback(const esp_now_recv_info_t *recvInfo, const uint8_t *data, int dataLen);
void sentCallback(const wifi_tx_info_t *info, esp_now_send_status_t status);
void broadcastCommand(const String &message);
void onWebSocketEvent(uint8_t num, WStype_t type, uint8_t *payload, size_t length);
void updateLcdTelemetry();
void startIgnitionFeedback();
void updateMelody();

// -----------------------------------------------------------------------------
// ESP-NOW Receive Callback
// -----------------------------------------------------------------------------

void receiveCallback(const esp_now_recv_info_t *recvInfo, const uint8_t *data, int dataLen) {
  int msgLen = min(ESP_NOW_MAX_DATA_LEN, dataLen);

  strncpy(packetBuffer, (const char *)data, msgLen);
  packetBuffer[msgLen] = '\0';

  newDataReady = true;
}

// -----------------------------------------------------------------------------
// ESP-NOW Send Callback
// -----------------------------------------------------------------------------

void sentCallback(const wifi_tx_info_t *info, esp_now_send_status_t status) {
  // Kept silent to reduce serial overhead during high-rate telemetry.
}

// -----------------------------------------------------------------------------
// ESP-NOW Broadcast Command
// -----------------------------------------------------------------------------

void broadcastCommand(const String &message) {
  uint8_t broadcastAddress[] = {0xFF, 0xFF, 0xFF, 0xFF, 0xFF, 0xFF};

  esp_now_peer_info_t peerInfo = {};
  memcpy(peerInfo.peer_addr, broadcastAddress, 6);

  if (!esp_now_is_peer_exist(broadcastAddress)) {
    esp_now_add_peer(&peerInfo);
  }

  esp_now_send(broadcastAddress, (const uint8_t *)message.c_str(), message.length());
}

// -----------------------------------------------------------------------------
// WebSocket Event Handler
// -----------------------------------------------------------------------------

void onWebSocketEvent(uint8_t num, WStype_t type, uint8_t *payload, size_t length) {
  if (type == WStype_CONNECTED) {
    webSocket.sendTXT(num, "{\"status\":\"Connected to Trigger Board\"}");
  }
}

// -----------------------------------------------------------------------------
// Setup
// -----------------------------------------------------------------------------

void setup() {
  Serial.begin(115200);

  pinMode(STATUS_BUTTON_PIN, INPUT_PULLUP);
  pinMode(BUZZER_PIN, OUTPUT);

  // ---------------------------------------------------------------------------
  // LCD Startup Message
  // ---------------------------------------------------------------------------

  lcd.init();
  lcd.backlight();

  lcd.setCursor(0, 0);
  lcd.print("NAKUJA PROJECT");
  delay(1500);

  lcd.clear();
  lcd.print("SOLID PROPULSION");
  delay(1500);

  lcd.clear();

  // ---------------------------------------------------------------------------
  // Wi-Fi Access Point Setup
  // ---------------------------------------------------------------------------

  WiFi.mode(WIFI_AP_STA);
  WiFi.softAP(WIFI_AP_SSID, WIFI_AP_PASSWORD);

  IPAddress myIP = WiFi.softAPIP();

  Serial.print("Wi-Fi AP started. IP: ");
  Serial.println(myIP);

  lcd.setCursor(0, 0);
  lcd.print("AP: NAKUJA");
  lcd.setCursor(0, 1);
  lcd.print(myIP);
  delay(2000);
  lcd.clear();

  // ---------------------------------------------------------------------------
  // ESP-NOW Setup
  // ---------------------------------------------------------------------------

  if (esp_now_init() != ESP_OK) {
    Serial.println("ESP-NOW initialization failed. Restarting...");
    ESP.restart();
  }

  esp_now_register_recv_cb(receiveCallback);
  esp_now_register_send_cb(sentCallback);

  // ---------------------------------------------------------------------------
  // WebSocket Setup
  // ---------------------------------------------------------------------------

  webSocket.begin();
  webSocket.onEvent(onWebSocketEvent);

  Serial.println("Trigger Board ready.");
}

// -----------------------------------------------------------------------------
// Main Loop
// -----------------------------------------------------------------------------

void loop() {
  webSocket.loop();

  // ---------------------------------------------------------------------------
  // 1. Process Telemetry from Igniter Board
  // ---------------------------------------------------------------------------

  if (newDataReady) {
    newDataReady = false;

    String dataString = String(packetBuffer);

    int firstComma = dataString.indexOf(',');
    int secondComma = dataString.indexOf(',', firstComma + 1);

    if (firstComma != -1 && secondComma != -1) {
      // Igniter telemetry format: thrust,temp,pressure
      thrustVal = dataString.substring(0, firstComma).toFloat();
      tempVal = dataString.substring(firstComma + 1, secondComma).toFloat();
      pressureVal = dataString.substring(secondComma + 1).toFloat();

      StaticJsonDocument<200> doc;

      doc["thrust"] = thrustVal;
      doc["temp"] = tempVal;
      doc["pressure"] = pressureVal;
      doc["ignition_armed"] = false;

      String jsonData;
      serializeJson(doc, jsonData);

      webSocket.broadcastTXT(jsonData);
    }
  }

  // ---------------------------------------------------------------------------
  // 2. LCD Telemetry Update
  // ---------------------------------------------------------------------------

  if (!isPlayingMelody && (millis() - lastLcdUpdate > LCD_UPDATE_INTERVAL_MS)) {
    updateLcdTelemetry();
    lastLcdUpdate = millis();
  }

  // ---------------------------------------------------------------------------
  // 3. Button Logic — Send Ignition Command on Release
  // ---------------------------------------------------------------------------

  if (digitalRead(STATUS_BUTTON_PIN) == HIGH) {
    // Button is released.
    if (!buttonReleased) {
      buttonReleased = true;

      broadcastCommand("on");

      Serial.println("Ignition command sent.");

      StaticJsonDocument<120> eventDoc;
      eventDoc["event"] = "Ignition command sent from trigger board";
      eventDoc["ignition_armed"] = true;

      String eventJson;
      serializeJson(eventDoc, eventJson);
      webSocket.broadcastTXT(eventJson);

      startIgnitionFeedback();
    }
  } else {
    // Button is pressed.
    buttonReleased = false;
  }

  // ---------------------------------------------------------------------------
  // 4. Non-Blocking Melody Player
  // ---------------------------------------------------------------------------

  updateMelody();
}

// -----------------------------------------------------------------------------
// LCD Helper
// -----------------------------------------------------------------------------

void updateLcdTelemetry() {
  lcd.setCursor(0, 0);
  lcd.print("F:");
  lcd.print(thrustVal, 1);
  lcd.print(" N    ");

  lcd.setCursor(0, 1);
  lcd.print("T:");
  lcd.print(tempVal, 1);

  lcd.setCursor(8, 1);
  lcd.print("P:");
  lcd.print(pressureVal, 1);
  lcd.print("  ");
}

// -----------------------------------------------------------------------------
// Ignition Feedback Helper
// -----------------------------------------------------------------------------

void startIgnitionFeedback() {
  lcd.clear();
  lcd.setCursor(0, 0);
  lcd.print("! IGNITION !");
  lcd.setCursor(0, 1);
  lcd.print("CMD SENT");

  isPlayingMelody = true;
  currentNote = 0;

  int duration = 1000 / noteDurations[currentNote];
  tone(BUZZER_PIN, melody[currentNote], duration);

  noteStartTime = millis();
}

// -----------------------------------------------------------------------------
// Melody Helper
// -----------------------------------------------------------------------------

void updateMelody() {
  if (!isPlayingMelody) {
    return;
  }

  int noteDuration = 1000 / noteDurations[currentNote];
  unsigned long pauseBetweenNotes = noteDuration * 1.3;

  if (millis() - noteStartTime >= pauseBetweenNotes) {
    currentNote++;

    if (currentNote >= MELODY_LENGTH) {
      isPlayingMelody = false;
      noTone(BUZZER_PIN);
    } else {
      int nextDuration = 1000 / noteDurations[currentNote];
      tone(BUZZER_PIN, melody[currentNote], nextDuration);
      noteStartTime = millis();
    }
  }
}

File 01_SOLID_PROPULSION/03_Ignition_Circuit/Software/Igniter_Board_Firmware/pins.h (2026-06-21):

#ifndef PINS_H
#define PINS_H

// Igniter Board Pin Mapping
// Update this file whenever the PCB, wiring, or firmware pin assignment changes.

// Ignition output
#define IGNITION_MOSFET_PIN 26

// HX711 load-cell interface
#define HX711_DOUT_PIN 33
#define HX711_SCK_PIN 32

// Temperature sensor
#define DS18B20_DATA_PIN 14

// Pressure sensor / transmitter analog input
#define PRESSURE_INPUT_PIN 13

#endif

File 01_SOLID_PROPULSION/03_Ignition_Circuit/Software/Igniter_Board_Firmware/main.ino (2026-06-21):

/*
  Nakuja Project — Igniter Board Firmware

  Purpose:
  - Read thrust data from HX711 load-cell module.
  - Read temperature data from DS18B20 sensor.
  - Read pressure data from analog pressure interface.
  - Receive ignition command from trigger board through ESP-NOW.
  - Control MOSFET-based ignition output.
  - Send telemetry to the trigger board.

  Notes:
  - The ESP32 does not directly power the ignition load.
  - GPIO26 only controls the MOSFET switching stage.
  - The ignition output is limited to a 15-second firmware window.
  - Telemetry format sent by this board: thrust,temp,pressure
*/

#include <Arduino.h>
#include <WiFi.h>
#include <esp_now.h>
#include <HX711_ADC.h>
#include <OneWire.h>
#include <DallasTemperature.h>

// -----------------------------------------------------------------------------
// Pin Definitions
// -----------------------------------------------------------------------------

#define PRESSURE_PIN 13
#define ONE_WIRE_BUS 14
#define IGNITION_PIN 26

const int HX711_DOUT_PIN = 33;
const int HX711_SCK_PIN  = 32;

// -----------------------------------------------------------------------------
// Temperature Sensor
// -----------------------------------------------------------------------------

OneWire oneWire(ONE_WIRE_BUS);
DallasTemperature sensors(&oneWire);

unsigned long lastTempRequest = 0;
float currentTemp = 0.0;

// -----------------------------------------------------------------------------
// Load Cell
// -----------------------------------------------------------------------------

HX711_ADC LoadCell(HX711_DOUT_PIN, HX711_SCK_PIN);

// Adjust after calibration.
const float LOAD_CELL_CALIBRATION_FACTOR = 1000.0;

// -----------------------------------------------------------------------------
// Ignition State
// -----------------------------------------------------------------------------

bool ignitionActive = false;
unsigned long ignitionStartTime = 0;

const unsigned long IGNITION_WINDOW_MS = 15000;

// -----------------------------------------------------------------------------
// Pressure Sensor Configuration
// -----------------------------------------------------------------------------

const int ADC_RESOLUTION = 4095;
const float ESP32_ADC_REFERENCE_VOLTAGE = 3.3;

// Sensor/interface calibration values.
// Ensure the analog voltage connected to the ESP32 ADC does not exceed 3.3 V.
const float SENSOR_MIN_VOLTAGE = 0.5;
const float SENSOR_MAX_VOLTAGE = 4.5;
const float SENSOR_MAX_PRESSURE = 1.2;

const int NUM_PRESSURE_READINGS = 10;

float pressureValue = 0.0;

// -----------------------------------------------------------------------------
// Function Prototypes
// -----------------------------------------------------------------------------

void receiveCallback(const esp_now_recv_info_t *recvInfo, const uint8_t *data, int dataLen);
void broadcastTelemetry(const String &message);
float mapPressure(float voltage);

// -----------------------------------------------------------------------------
// ESP-NOW Receive Callback
// -----------------------------------------------------------------------------

void receiveCallback(const esp_now_recv_info_t *recvInfo, const uint8_t *data, int dataLen) {
  char buffer[ESP_NOW_MAX_DATA_LEN + 1];

  int msgLen = min(ESP_NOW_MAX_DATA_LEN, dataLen);
  strncpy(buffer, (const char *)data, msgLen);
  buffer[msgLen] = '\0';

  if (strcmp(buffer, "on") == 0) {
    Serial.println(">>> IGNITION COMMAND RECEIVED <<<");

    ignitionActive = true;
    ignitionStartTime = millis();
  }
}

// -----------------------------------------------------------------------------
// ESP-NOW Broadcast
// -----------------------------------------------------------------------------

void broadcastTelemetry(const String &message) {
  uint8_t broadcastAddress[] = {0xFF, 0xFF, 0xFF, 0xFF, 0xFF, 0xFF};

  esp_now_peer_info_t peerInfo = {};
  memcpy(peerInfo.peer_addr, broadcastAddress, 6);

  if (!esp_now_is_peer_exist(broadcastAddress)) {
    esp_now_add_peer(&peerInfo);
  }

  esp_now_send(broadcastAddress, (const uint8_t *)message.c_str(), message.length());
}

// -----------------------------------------------------------------------------
// Sensor Helper Functions
// -----------------------------------------------------------------------------

float mapPressure(float voltage) {
  voltage = constrain(voltage, SENSOR_MIN_VOLTAGE, SENSOR_MAX_VOLTAGE);

  return (voltage - SENSOR_MIN_VOLTAGE) *
         SENSOR_MAX_PRESSURE /
         (SENSOR_MAX_VOLTAGE - SENSOR_MIN_VOLTAGE);
}

// -----------------------------------------------------------------------------
// Setup
// -----------------------------------------------------------------------------

void setup() {
  Serial.begin(115200);

  pinMode(PRESSURE_PIN, INPUT);
  pinMode(IGNITION_PIN, OUTPUT);

  // Safety on boot: ignition output must remain OFF.
  digitalWrite(IGNITION_PIN, LOW);

  // Configure ESP32 ADC range.
  analogSetAttenuation(ADC_11db);

  // ---------------------------------------------------------------------------
  // Temperature Sensor Setup
  // ---------------------------------------------------------------------------

  sensors.begin();
  sensors.setWaitForConversion(false);
  sensors.requestTemperatures();

  Serial.println("DS18B20 initialized in asynchronous mode.");

  // ---------------------------------------------------------------------------
  // Load Cell Setup
  // ---------------------------------------------------------------------------

  Serial.println("Initializing HX711 load-cell interface...");

  LoadCell.begin();

  // 8 samples at 80 SPS gives approximately 100 ms smoothing.
  LoadCell.setSamplesInUse(8);

  // Startup tare.
  LoadCell.start(2000, true);

  if (LoadCell.getTareTimeoutFlag()) {
    Serial.println("HX711 timeout. Check wiring, solder bridge, and sampling-rate configuration.");
    while (1);
  }

  LoadCell.setCalFactor(LOAD_CELL_CALIBRATION_FACTOR);

  Serial.println("Load cell zeroed and ready.");

  // ---------------------------------------------------------------------------
  // ESP-NOW Setup
  // ---------------------------------------------------------------------------

  WiFi.mode(WIFI_STA);
  WiFi.disconnect();

  if (esp_now_init() == ESP_OK) {
    Serial.println("ESP-NOW initialization successful.");
    esp_now_register_recv_cb(receiveCallback);
  } else {
    Serial.println("ESP-NOW initialization failed. Restarting...");
    ESP.restart();
  }
}

// -----------------------------------------------------------------------------
// Main Loop
// -----------------------------------------------------------------------------
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

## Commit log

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2026-06-21 Add README for ignition subsystem documentation
    Added comprehensive documentation for the ignition subsystem, detailing its purpose, system architecture, components, communication flow, telemetry variables, safety logic, and repository scope.
2026-06-21 Add README.md for Ignition Circuit software
    Added a comprehensive README.md for the Ignition Circuit software, detailing the project overview, folder structure, software modules, firmware responsibilities, web dashboard functions, communicatio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
2026-06-21 Add hardware documentation for ignition circuit
    This README.md file contains detailed hardware documentation for the Nakuja Project ignition circuit, including module descriptions, recommended folder structure, main components, and documentation r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
2026-06-21 Add README for Igniter Board Firmware
    Added README.md for Igniter Board Firmware, detailing its responsibilities, hardware interfaces, pin mapping, firmware logic, documentation requirements, and safety notes.
2026-06-21 Add README for Trigger Board Firmware
    Added detailed README for Trigger Board Firmware, outlining its responsibilities, interfaces, logic, and documentation requirements.
2026-06-21 Create README files for ignition system documentation
    Added README files for Schematics, PCB, Wiring Diagrams, and Photos sections of the ignition system documentation.
2026-06-21 Add pin mapping documentation for ignition circuit
    This document outlines the ESP32 pin assignments for the ignition and telemetry system, including details on the igniter and trigger board mappings, communication methods, and important hardware note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
2026-06-21 Create README.md for PCB documentation
    Added documentation for PCB layout and fabrication details for the ignition circuit hardware.
2026-06-21 Add README for wiring diagrams in ignition circuit
    Added a README file outlining the wiring diagrams for the Nakuja Project ignition circuit hardware, including an overview, recommended contents, diagrams to include, documentation requirements, namin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
2026-06-21 Add README for hardware photos in ignition circuit
    This README.md file provides an overview and guidelines for including hardware photos related to the Nakuja Project ignition circuit. It outlines recommended contents, photo types, naming formats, do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
2026-06-21 Add igniter board firmware library list
    This file lists the main libraries required by the igniter board firmware, including their purposes and notes for usage.
2026-06-21 Add igniter board firmware placeholder
    Initial implementation of Igniter Board firmware to handle telemetry and commands.
2026-06-21 Create pins.h for Trigger Board pin mapping
    Added pin definitions for the Trigger Board.
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2026-06-21 Add libraries documentation for Trigger Board Firmware
    This file lists the main libraries required by the trigger board firmware, including their purposes and notes for library management.
2026-06-21 Add initial Trigger Board firmware
    Initial implementation of the Trigger Board firmware to handle telemetry and commands.
2026-06-21 Add connection guide for Nakuja ignition dashboard
    This document provides a comprehensive guide on connecting the Nakuja ignition web dashboard to the ESP32 trigger board, including connection steps, default WebSocket settings, expected connection fl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
2026-06-21 Add README for sample dashboard data
    This README.md file provides an overview of the sample telemetry data used for testing the Nakuja ignition web dashboard, including recommended files and expected telemetry variables.
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2026-06-21 Add sample dashboard data CSV for testing
    [sample_dashboard_data.csv]
2026-06-21 Revise library list for Igniter Board Firmware
    Updated library names and added core Arduino references.
2026-06-21 Update trigger board library documentation
    Updated library list and descriptions for Trigger Board Firmware.
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2026-06-21 Add firmware integration notes
    Added detailed firmware integration notes for the Nakuja ignition system, including roles of the igniter and trigger boards, telemetry formats, safety notes, pin summaries, and integration checklist.
2026-06-27 Add files via upload
    Added the final launchpad step fie
    [END LAUNCHPAD ASSEMBLY.stp]
2026-07-01 Open Motor Simulations
    "N4_05-2025_OM_V1-AL.ric" ---> This is the N4 open motor grain simulation with grain dimensions for the Aluminum casing from 2025
    "N4_06-2026_OM_V2-SS.ric" ---> This is the N4 open motor grain simulation with grain dimensions for the new Stainless Steel casing
2026-07-03 Added Photos folder to each sub-team and updated the Static_tests folder to include the open motor files for one and five grain tests
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2026-07-20 One-grain Static Tests Motor
    Working Drawings for the one-grain static tests motor
    [bulkHead_94mm.dwg, bulkHead_94mm.ipt, casing_258mm.dwg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]
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2026-08-19 Uploaded Static test #7: 3 grain test results
    [3 grain test results.csv]
